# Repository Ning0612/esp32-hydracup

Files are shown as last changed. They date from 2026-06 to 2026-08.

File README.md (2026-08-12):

# HydraCup








ESP32-based smart water cup tracker. Measures cup weight via HX711, detects drink events, provides a local Device Console, and can sync with a separate LINE/LIFF service.

The firmware runs on native ESP-IDF/FreeRTOS through PlatformIO. Hardware access uses
ESP-IDF drivers; the web server, MQTT, Discord HTTPS client, NVS, and LittleFS are
all initialized from `app_main()` without the Arduino framework.

## Project Status

Personal side project for daily hydration tracking. It may continue to receive maintenance when new feature ideas or practical usage needs come up.

Real hardware:

<div align="center">
  <table align="center">
    <tr>
      <td align="center" valign="top">
        <strong>HydraCup real setup</strong><br>
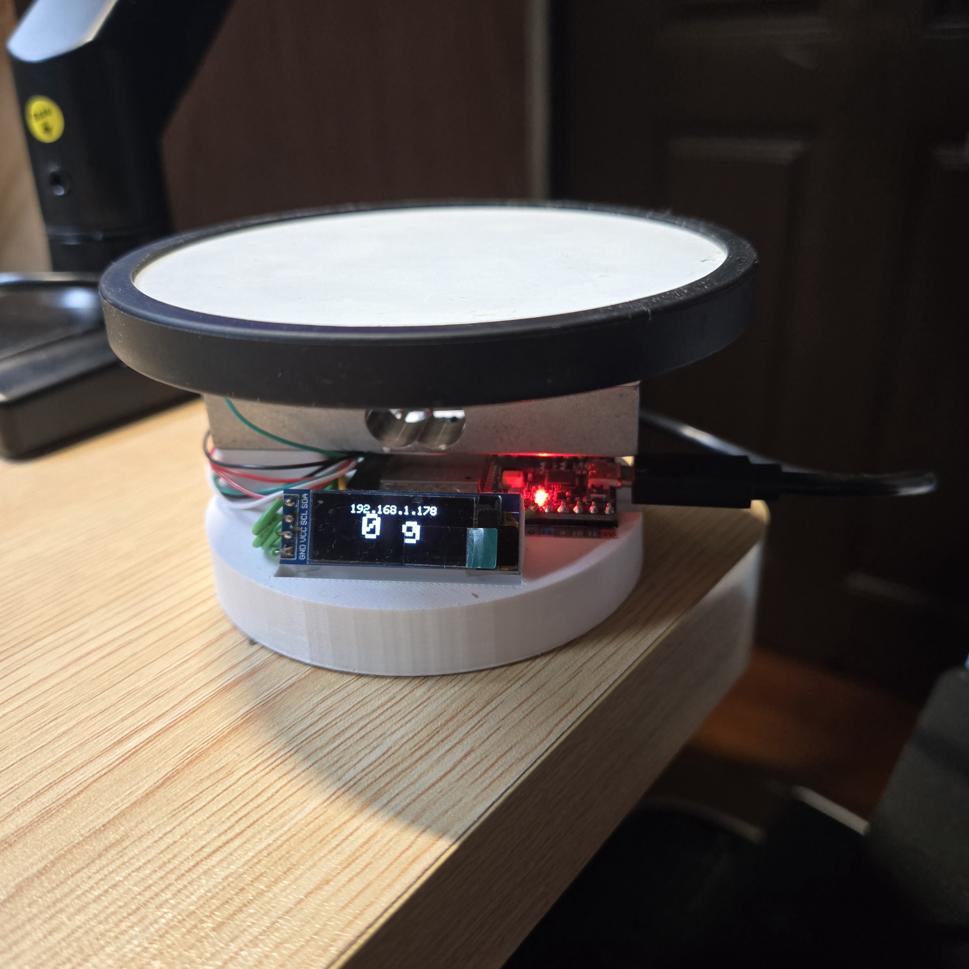
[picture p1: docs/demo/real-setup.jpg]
HydraCup real hardware setup
        
      </td>
      <td align="center" valign="top">
        <strong>OLED status</strong><br>
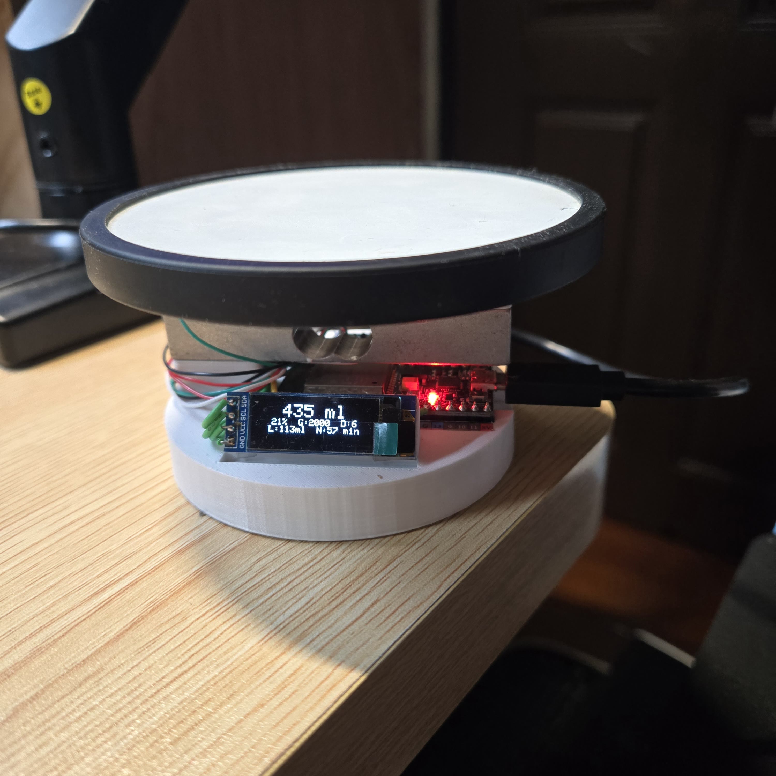
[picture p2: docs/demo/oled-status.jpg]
HydraCup OLED status on real hardware
        
      </td>
    </tr>
  </table>
</div>

## Demo

<p align="center">
  HydraCup drink detection preview
</p>

The GIF above is a compressed full-length preview; use the MP4 link below for the full-quality demo.

Full demo video:

- [Drink detection demo (MP4)](docs/demo/drink-detection-demo.mp4)

WebUI screenshots:

The local dashboard is served by the ESP32 at `http://<device-ip>`. The current Console uses the same cup-and-ripple visual language as the hosted LIFF UI, supports light and dark themes, and changes to a fixed three-item dock on small screens. It keeps live hardware diagnostics dense while the hosted UI remains focused on daily hydration. The screenshots below cover the dashboard, history analytics, and device configuration workflows; minor styling may evolve between releases.

<div align="center">
  <table align="center">
    <tr>
      <td colspan="2" align="center" valign="top">
        <strong>Dashboard overview</strong><br>
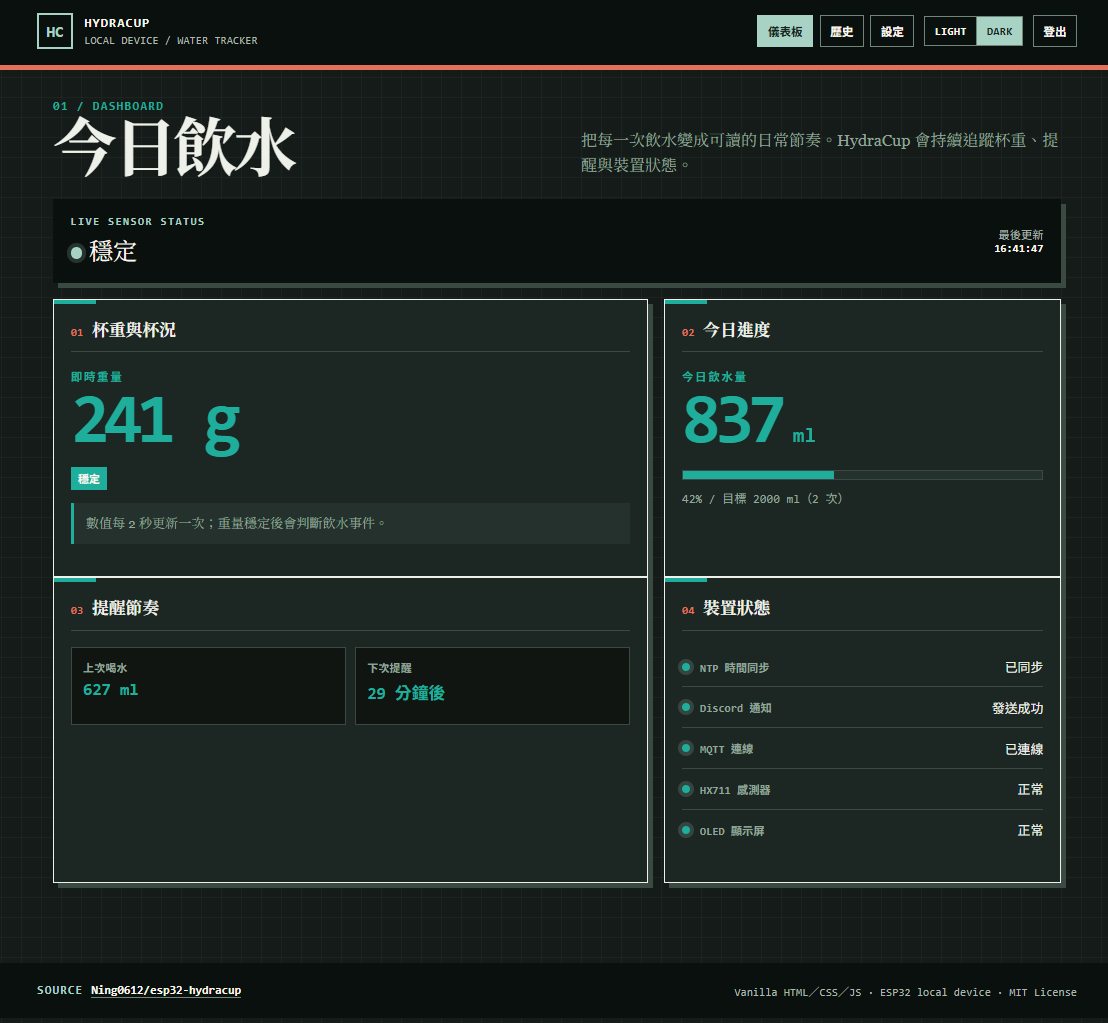
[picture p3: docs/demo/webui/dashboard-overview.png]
HydraCup WebUI dashboard overview
        
      </td>
    </tr>
    <tr>
      <td align="center" valign="top">
        <strong>History overview</strong><br>
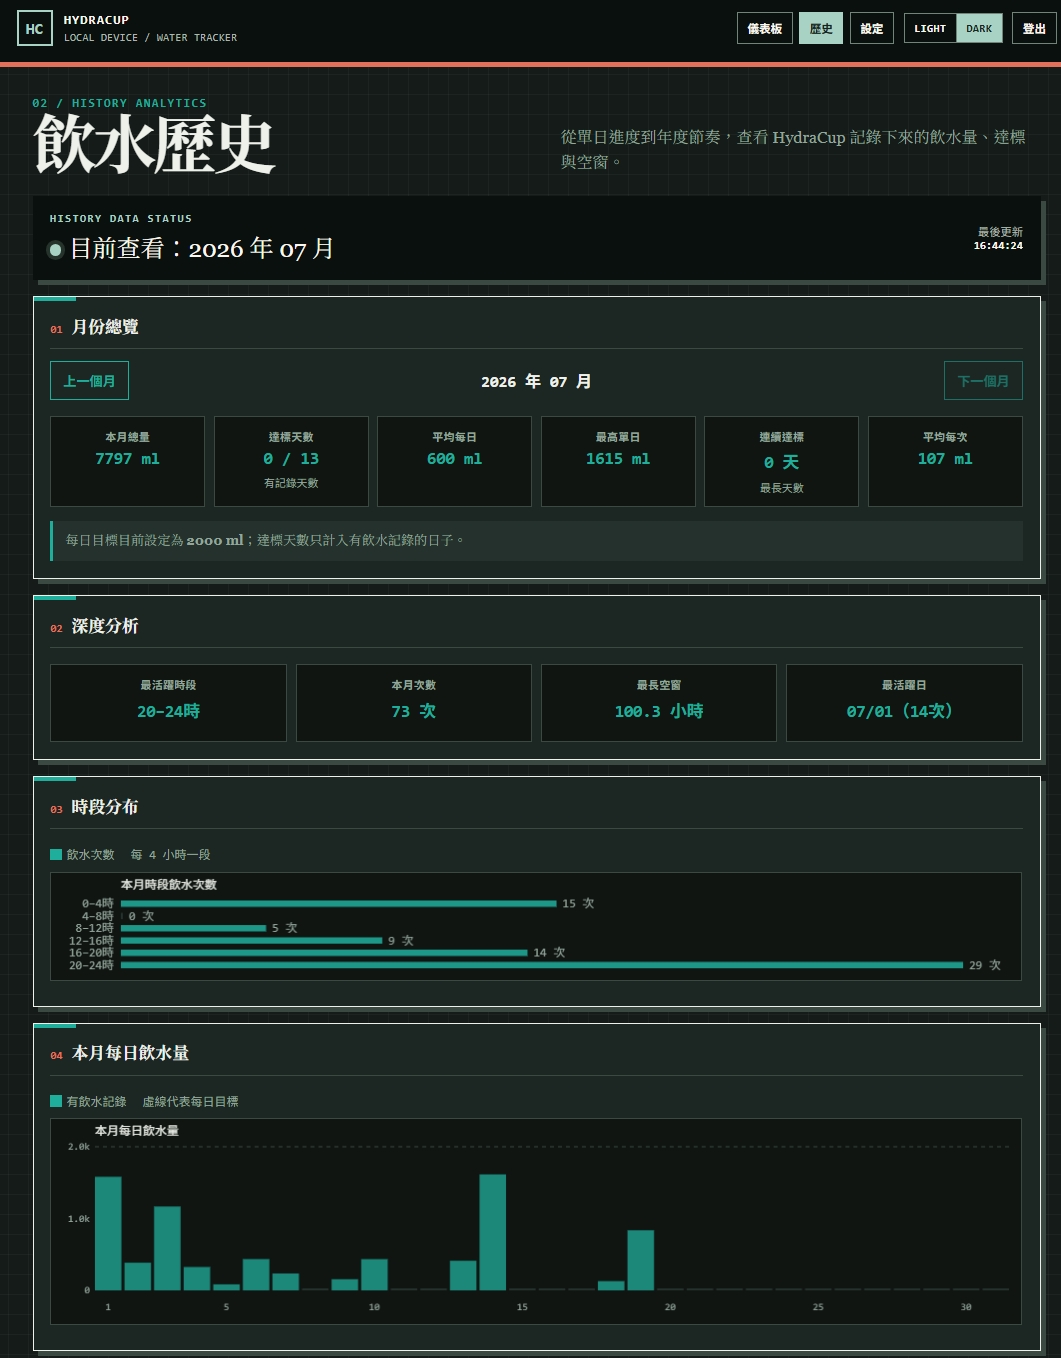
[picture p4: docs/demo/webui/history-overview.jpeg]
HydraCup WebUI history overview
        
      </td>
      <td align="center" valign="top">
        <strong>History statistics</strong><br>
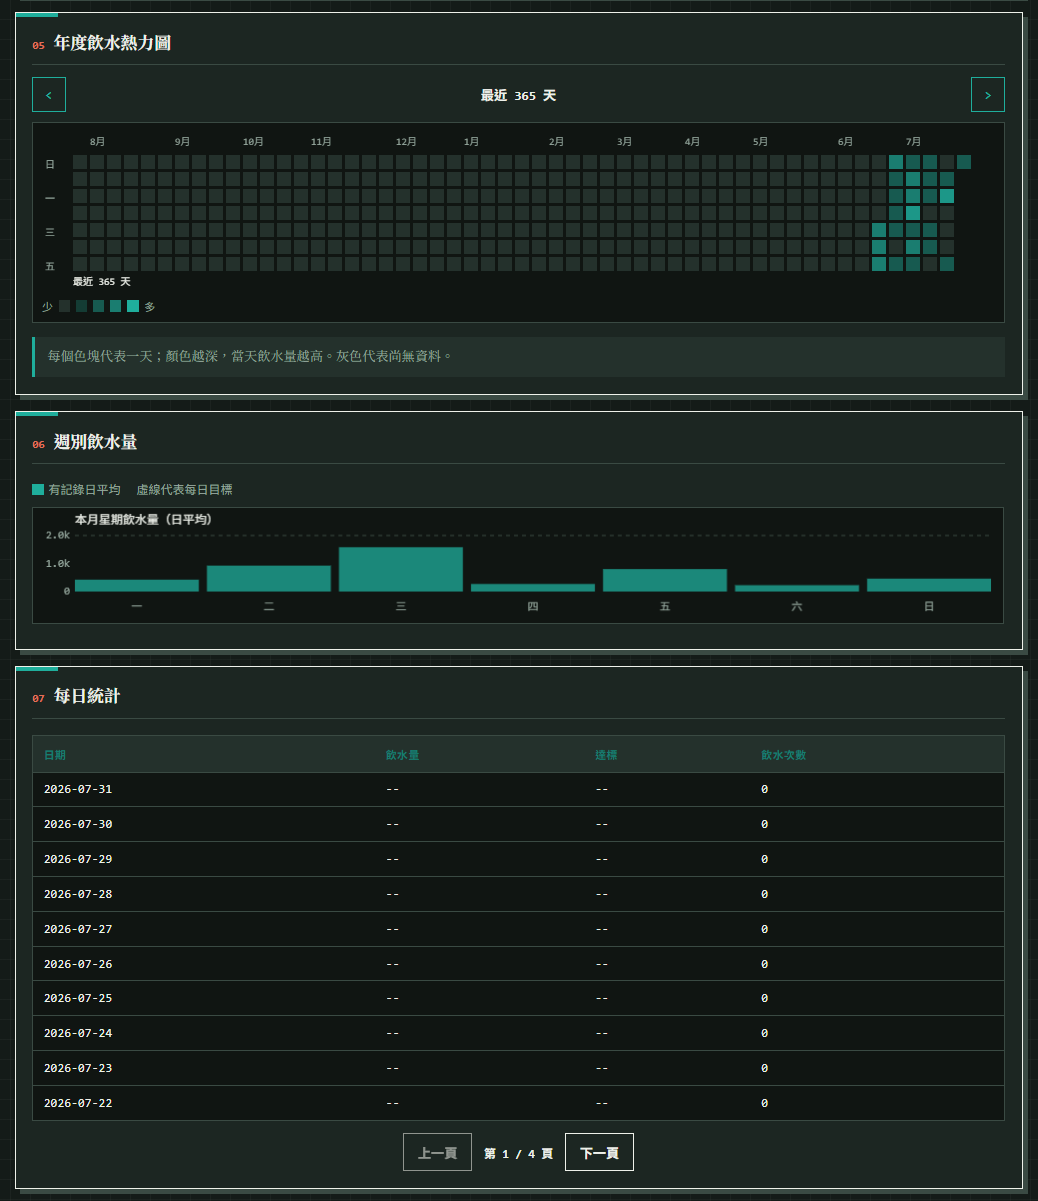
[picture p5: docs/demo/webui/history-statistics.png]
HydraCup WebUI history statistics
        
      </td>
    </tr>
    <tr>
      <td align="center" valign="top">
        <strong>Device settings</strong><br>
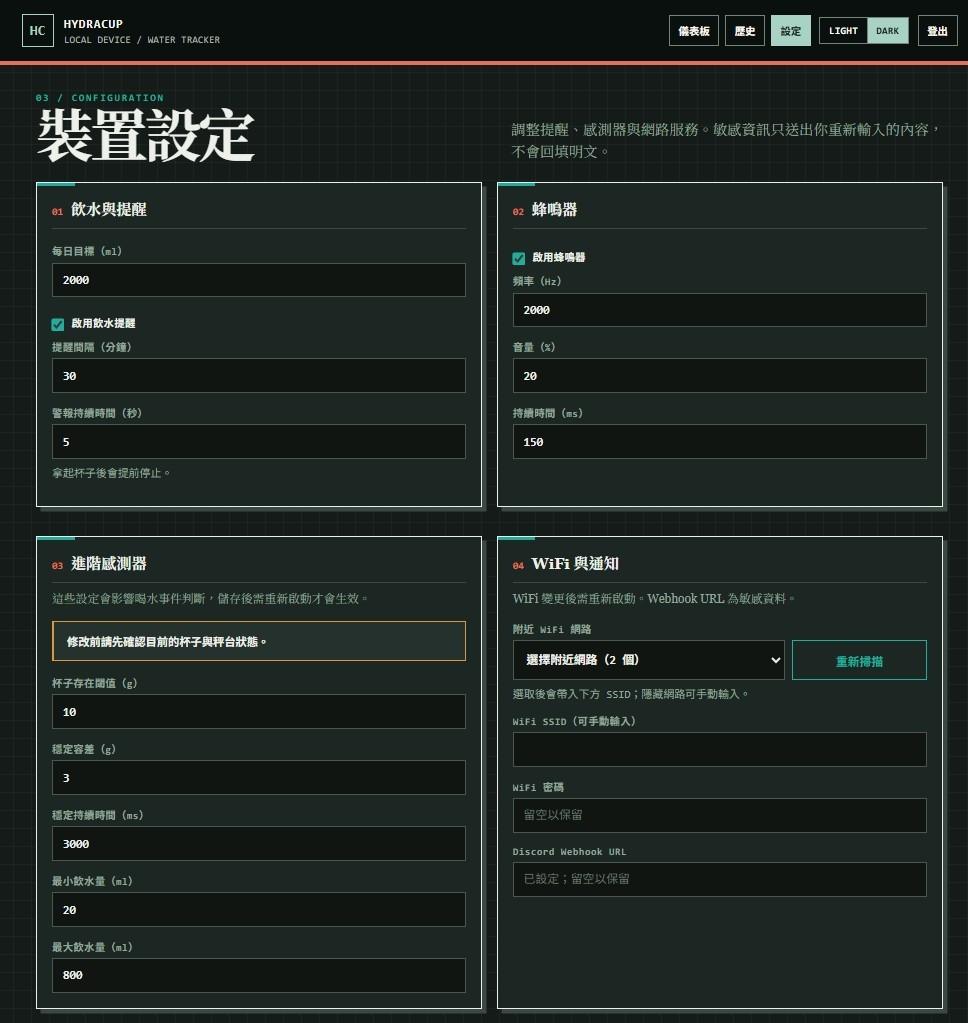
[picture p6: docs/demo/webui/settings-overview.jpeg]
HydraCup WebUI device settings
        
      </td>
      <td align="center" valign="top">
        <strong>Scale calibration</strong><br>
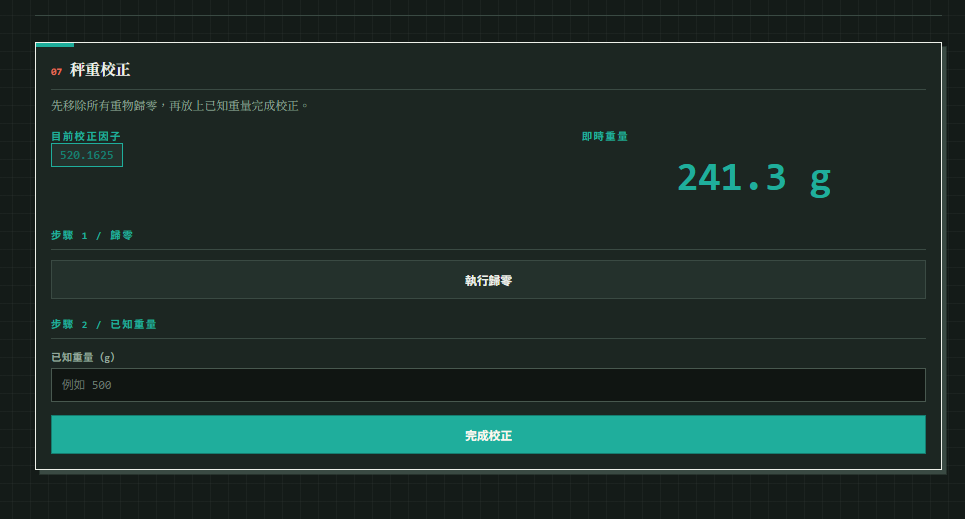
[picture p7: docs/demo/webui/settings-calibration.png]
HydraCup WebUI scale calibration
        
      </td>
    </tr>
  </table>
</div>

---

## Features

- **Automatic drink detection** — 6-state machine triggered only via cup-lift path, avoids false positives
- **Responsive Device Console** — cup/reminder state, real-time weight, progress, history, diagnostics, and progressively disclosed device settings at `http://<device-ip>`
- **Discord Webhook** — online notification, per-drink notification, daily summary at midnight
- **JSONL event log** — monthly log files stored on a dedicated LittleFS partition (`/logs/`)
- **OLED display** — 2-page rotating status display with auto-sleep
- **Cup-aware reminders** — counts only while a stable cup is present; a confirmed drink restarts the interval
- **Durable cloud sync** — LittleFS outbox with ACK-based replay plus resumable daily-history backfill for the separate LINE/LIFF WebUI service
- **OTA firmware updates** — check and install from GitHub Releases in the Device Console, with bootloader rollback if the new image fails to come up
- **Captive config portal** — WiFi setup at `192.168.4.1` on first boot (no app needed)
- **FreeRTOS control isolation** — scale/detection/reminder/display run in one high-priority control task; network operations stay in background workers
- **Non-blocking tare and workers** — tare is sample-driven; Discord, MQTT and drink logging use persistent/background workers

Cloud events are durably committed before the confirmed drink/refill callback returns. A transient LittleFS append failure falls back to an 8-record NVS emergency overflow. This adds bounded flash latency after a confirmed event; if both the 512 KiB outbox and emergency overflow are unavailable, Device Console reports a hard-drop counter. Measure worst-case LittleFS/NVS latency on the target board before production use.

---

## Hardware Requirements

| Component | Spec | GPIO |
|---|---|---|
| ESP32 dev board | 30-pin or 38-pin | — |
| HX711 load cell amplifier | 10 Hz or 80 Hz | DOUT→4, SCK→5 |
| Load cell / strain gauge | 1–5 kg range | via HX711 |
| SSD1306 OLED | 128×32, I2C | SDA→21, SCL→22 |
| Passive buzzer | 3.3 V compatible | PWM→18 |

See [docs/hardware.md](docs/hardware.md) for wiring details and BOM.

---

## Quick Start

**Prerequisites**: [PlatformIO](https://platformio.org/install/cli), Python 3.x, CP210x / CH340 USB driver

```bash
# 1. Clone
git clone https://github.com/<your-user>/esp32-hydracup.git
cd esp32-hydracup

# 2. Build firmware (ESP-IDF environment)
pio run -e esp32dev

# 3. Flash firmware + web assets (first time)
pio run -e esp32dev --target upload
pio run -e esp32dev --target uploadfs

# 4. If WiFi is not configured or the STA connection times out, the device
#    broadcasts "WaterCupTracker-Setup" AP. Connect and open http://192.168.4.1
#    The default AP password is 12345678. Enter your WiFi credentials and save.
#    This is not the admin password; no admin password has a default value.

# 5. After reboot, find the device IP and open http://<ip>/login
#    Set an admin password (at least 8 characters) on first use, then sign in.
```

See [docs/guides/getting-started.md](docs/guides/getting-started.md) for the complete first-time setup walkthrough.

---

## Architecture Overview

```
┌─────────────────── Normal Mode ───────────────────────┐
│  hydracup_control (Core 1, 10 ms)                     │
│  ├─ ScaleManager → DrinkDetector                      │
│  ├─ Reminder / Buzzer / Display / Time                │
│  └─ RuntimeSnapshot + ControlCommand Queue             │
│                                                       │
│  hydracup_service (50 ms) → WiFi / MQTT / health      │
│  esp_http_server task → Dashboard / REST API           │
│  workers → Cloud sync / Discord / MQTT / Log / NVS    │
└───────────────────────────────────────────────────────┘

┌────── AP Mode (no WiFi configured) ──────────────────┐
│  ConfigPortal  (HTTP at 192.168.4.1)                 │
└──────────────────────────────────────────────────────┘
```

---

## API Quick Reference

| Method | Path | Description |
|---|---|---|
| GET | `/api/status` | Full system state snapshot |
| GET | `/api/weight` | Current weight + cup state |
| GET | `/api/config` | All settings |
| POST | `/api/config` | Update settings |
| POST | `/api/tare` | Tare scale |
| POST | `/api/calibrate` | Calibrate with known weight |
| GET | `/api/logs?month=YYYY-MM` | Drink history |
| POST | `/api/cloud/history-backfill` | Start resumable Local-history backfill |
| GET | `/api/ota/status` | Firmware update state, progress and version |
| POST | `/api/ota/check` | Check GitHub Releases for a newer firmware |
| POST | `/api/ota/update` | Download and install the newer firmware |
| GET | `/api/wifi/scan` | Scan nearby networks |
| POST | `/api/reboot` | Reboot device |

All responses: `{"ok": true, ...}` or `{"ok": false, "error": "..."}`.  
Full API reference: [docs/api.md](docs/api.md)

---

## Documentation

| Document | Description |
|---|---|
| [docs/hardware.md](docs/hardware.md) | GPIO wiring and bill of materials |
| [docs/architecture.md](docs/architecture.md) | System architecture, boot flow, drink detection state machine |
| [docs/api.md](docs/api.md) | Complete REST API reference |
| [docs/modules.md](docs/modules.md) | Firmware module descriptions and public APIs |
| [docs/data-formats.md](docs/data-formats.md) | JSONL log format and NVS storage schema |
| [docs/guides/getting-started.md](docs/guides/getting-started.md) | First-time setup |
| [docs/guides/build-flash.md](docs/guides/build-flash.md) | Build and flash commands |
| [docs/guides/calibration.md](docs/guides/calibration.md) | Scale calibration |
| [docs/guides/configuration.md](docs/guides/configuration.md) | All settings explained |
| [docs/guides/discord-setup.md](docs/guides/discord-setup.md) | Discord Webhook setup |
| [docs/releases/v0.5.0.md](docs/releases/v0.5.0.md) | Cup-aware reminders, unified WebUI, LINE/LIFF sync, and history backfill |

The companion Cloudflare/LINE service is maintained in the private
[`hydracup-service`](https://github.com/Ning0612/hydracup-service) repository. Firmware `v0.5.0`
and service protocol v1 form the current tested pair; see the service user guide for pairing and
hosted LIFF operation.

## License

This public version is released under the MIT License. See [LICENSE](LICENSE).

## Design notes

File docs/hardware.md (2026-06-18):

# Hardware

## GPIO 腳位

所有腳位定義在 `include/pins.h`，原始碼中不得使用裸數字。

| 腳位名稱 | GPIO | 方向 | 說明 |
|---|---|---|---|
| `PIN_HX711_DOUT` | 4 | 輸入 | HX711 資料輸出（Data Out） |
| `PIN_HX711_SCK` | 5 | 輸出 | HX711 時脈（Serial Clock） |
| `PIN_OLED_SDA` | 21 | 雙向 | I2C 資料線（SSD1306 OLED） |
| `PIN_OLED_SCL` | 22 | 輸出 | I2C 時脈線（SSD1306 OLED） |
| `PIN_BUZZER` | 18 | 輸出 | LEDC PWM 蜂鳴器輸出 |

## 接線說明

### HX711 ↔ ESP32

```
HX711       ESP32
------      ------
VCC    →    3V3
GND    →    GND
DOUT   →    GPIO 4
SCK    →    GPIO 5
```

HX711 的 E+ / E- / A+ / A- 接稱重感測器（4線橋式）。  
使用 80 Hz 輸出速率時，將 RATE 腳位接高電位（3.3V）；使用 10 Hz 則接低或懸空。

### SSD1306 OLED ↔ ESP32

```
OLED        ESP32
------      ------
VCC    →    3V3
GND    →    GND
SDA    →    GPIO 21
SCL    →    GPIO 22
```

I2C 位址：`0x3C`，解析度：128×32。

### 蜂鳴器 ↔ ESP32

```
Buzzer      ESP32
------      ------
+      →    GPIO 18  (via 100Ω resistor recommended)
-      →    GND
```

使用無源蜂鳴器（Passive Buzzer）；有源蜂鳴器無法由 LEDC PWM 控制音調。

## 電源需求

| 供電 | 說明 |
|---|---|
| 5V USB | ESP32 板子 micro-USB 供電 |
| 3.3V | HX711、OLED、蜂鳴器（由 ESP32 板子 3V3 引腳供電） |

若使用超過 5 kg 的感測器或 HX711 增益 128 以外的設定，請確認感測器 E+ 供電穩定。

---

## 元件清單（BOM）

| 元件 | 規格 | 備注 |
|---|---|---|
| ESP32 Dev Board | 38-pin，帶 USB-UART（CP2102 或 CH340） | 任何標準 esp32dev 相容板皆可 |
| HX711 模組 | 10/80 Hz，24-bit ADC | 搭配 4線橋式稱重感測器 |
| 稱重感測器 | 1–5 kg，橋式應變計 | 建議搭配杯架固定 |
| SSD1306 OLED | 128×32，I2C，0.91 吋 | 0x3C 位址 |
| 無源蜂鳴器 | 3.3V，2 kHz | 不可用有源蜂鳴器 |
| 杯托 / 底座 | 平面壓力均勻分布 | 可 3D 列印 |
| 跳線 | 公對公 / 公對母 | 接麵包板或焊接 |
| 麵包板 / PCB | 830孔麵包板 或 洞洞板 | 原型用途 |

### 台灣採購建議

- ESP32 / HX711 / SSD1306：台灣各大網路電子材料商（露天、蝦皮、飆機器人）
- 稱重感測器：「應變計稱重」or「load cell 台灣」搜尋

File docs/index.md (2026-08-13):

# HydraCup Documentation

ESP32 智慧水杯追蹤器完整文件索引。

---

## 硬體與設定

- [hardware.md](hardware.md) — GPIO 接線圖、元件清單（BOM）

## 系統架構

- [architecture.md](architecture.md) — 模組架構、資料流、開機流程、飲水偵測狀態機

## API 參考

- [api.md](api.md) — 完整 REST API 端點（DashboardServer + ConfigPortal）

## 模組文件

- [modules.md](modules.md) — 18 個模組的責任、依賴與公開方法

## 資料格式

- [data-formats.md](data-formats.md) — JSONL 日誌格式、NVS 儲存 Schema

## 操作指南

- [guides/getting-started.md](guides/getting-started.md) — 首次使用設定流程
- [guides/build-flash.md](guides/build-flash.md) — 建置與燒錄指令
- [guides/calibration.md](guides/calibration.md) — 秤重校正步驟
- [guides/configuration.md](guides/configuration.md) — 所有設定說明
- [guides/discord-setup.md](guides/discord-setup.md) — Discord Webhook 設定

## LINE／LIFF 雲端服務

- [HydraCup Service 使用指南](https://github.com/Ning0612/hydracup-service/blob/main/docs/user-guide.md)（`hydracup-service` 為私有 repo，需有存取權限） — Cloud sync、配對、歷史補傳與 LIFF 操作
- [HydraCup Service v1 協定](https://github.com/Ning0612/hydracup-service/blob/main/docs/protocol.md)（`hydracup-service` 為私有 repo，需有存取權限） — 裝置同步、command／ACK 與歷史查詢合約

韌體 `v0.5.0` 與 service protocol v1 是目前驗證組合。ESP32 保留 Local 月檔並作為飲水事件與
提醒狀態的唯一真實來源；LIFF 顯示已同步事件及使用者主動執行的歷史補傳資料。

## 版本紀錄

- [releases/v0.5.0.md](releases/v0.5.0.md) — 杯況感知提醒、統一 WebUI、LINE／LIFF 同步與歷史補傳
- [releases/v0.4.0.md](releases/v0.4.0.md) — 原生 FreeRTOS/ESP-IDF 遷移與首次使用流程更新
- [releases/v0.3.0.md](releases/v0.3.0.md) — WebUI 風格重設計與展示素材更新
- [releases/v0.2.0.md](releases/v0.2.0.md) — FreeRTOS runtime 與背景 worker 更新

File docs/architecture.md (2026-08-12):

# Architecture

## 系統架構

HydraCup 以 PlatformIO + ESP-IDF 5.x 的 native FreeRTOS runtime 運行，分為兩個互斥模式。
`app_main()` 負責初始化硬體、NVS、LittleFS、網路與服務；固定在 Core 1 的高優先
`hydracup_control` task 負責感測與即時控制：

```
┌────────────────────────────────────────────────────────┐
│                    BOOT                                │
│  app_main → NVS → webfs/logfs → Config → OLED/HX711   │
│  → Buzzer → WiFi configured?                          │
│        No  → AP_MODE (ConfigPortal)                   │
│        Yes → STA connect → OK? → NORMAL : AP_MODE     │
└────────────────────────────────────────────────────────┘

┌────────── AP Mode ─────────────────────────────────────┐
│  ConfigPortal  HTTP server @ 192.168.4.1               │
│  → WiFi config saved → reboot → NORMAL                │
└────────────────────────────────────────────────────────┘

┌────────── Normal Mode ─────────────────────────────────┐
│  hydracup_control (10 ms, Core 1)                     │
│  ScaleManager → DrinkDetector                          │
│                     ├─→ EventLogger                    │
│                     ├─→ DiscordNotifier                │
│                     ├─→ ReminderManager                │
│                     ├─→ BuzzerController               │
│                     └─→ AppState                       │
│                                                        │
│  ├─ ReminderManager / BuzzerController                 │
│  ├─ DisplayManager / TimeManager                       │
│  └─ DailySummaryManager                                │
│                                                        │
│  hydracup_service (50 ms): WiFi / MQTT / health        │
│  esp_http_server task: DashboardServer                 │
│  workers: MQTT / Discord / EventLogger / CloudSync / NVS│
└────────────────────────────────────────────────────────┘
```

### 設計約束

- `hydracup_control` 是 Scale、Detector、Reminder、Buzzer、Display、Time 的單一 owner
- HTTP handler 不直接驅動控制模組；Dashboard 透過 snapshot / command 溝通
- 不使用 Arduino `setup()` / `loop()`；控制與服務 task 都必須保持非阻塞
- 所有時間取值使用 `hal_millis()` / `hal_micros()`（底層為 `esp_timer`），等待使用 `vTaskDelay`
- Discord 與 MQTT 各使用持久 FreeRTOS worker；兩者不共用阻塞 task
- tare 是 10 筆、每 100 ms 一筆的非阻塞狀態機；期間暫停飲水偵測
- NVS 操作透過共用 mutex 序列化；LogFS 讀寫也有獨立 mutex
- counter restore worker 只載入 POD，由 `hydracup_control` 套用；跨日資料即使非午夜開機也會立即結算
- Daily settlement 等待 counter save ack，再由 storage worker 寫 settled marker，控制 task 不等待 flash

---

## 模組職責表

| 模組 | 職責 |
|---|---|
| `AppState` | 共用執行時狀態結構（模式、杯子狀態、今日飲水量等） |
| `ConfigManager` | NVS 讀寫 `AppConfig`；命名空間 `water_config` |
| `WiFiManager` | STA 連線、AP 啟動、連線狀態管理 |
| `ConfigPortal` | AP Mode HTTP 伺服器（192.168.4.1），WiFi 設定 |
| `DashboardServer` | Normal Mode HTTP 伺服器，儀表板 + REST API |
| `ScaleManager` | HX711 取樣、移動平均濾波、秤台校正 |
| `DrinkDetectorCore` | framework-independent 的 6 態飲水偵測核心，輸出飲水/補水事件 |
| `DrinkDetector` | ESP32 adapter：對接 ScaleManager、AppState、每日計數器與通知管道 |
| `ReminderCore` | framework-independent 主動時間狀態機；穩定放杯才計時，杯子離開即暫停 |
| `ReminderManager` | 驅動 ReminderCore 與蜂鳴器；只有確認喝水才重新計時 |
| `CloudSyncClient` | LittleFS durable outbox、HTTPS 批次同步、command ACK、配對碼與可續傳歷史補傳 |
| `BuzzerController` | LEDC PWM 非阻塞蜂鳴佇列（7 種模式） |
| `DisplayManager` | SSD1306 OLED 輪播（2 頁，各 4 秒），自動睡眠 |
| `DiscordNotifier` | 非同步 HTTPS POST 至 Discord Webhook |
| `EventLogger` | LittleFS JSONL 飲水事件日誌（依月份分檔） |
| `OtaUpdater` | GitHub Releases 版本檢查與 `esp_https_ota` 韌體寫入；含開機確認與 rollback |
| `HistoryMaintenance` | 飲水紀錄清除：WebUI 只記錄要求，實際清除在下次開機、掛載前執行 |
| `TimeManager` | NTP 時間同步；提供 ISO-8601 時戳 |
| `DailySummaryManager` | 每日午夜聚合統計並送出 Discord 摘要 |
| `RuntimeCoordinator` | 一致 runtime snapshot、control command/result Queue |
| `StorageLock` | 跨 task 序列化 NVS 操作 |
| `Hal` | `esp_timer` 時間、FreeRTOS delay 與 ESP-IDF logging wrapper |
| `HttpAuth` | session token、CSRF、PBKDF2 密碼雜湊與 constant-time 比對 |
| `HttpServerSupport` | `esp_http_server` request、header、檔案與 response 共用工具 |

---

## 開機流程

```
1. `app_main()` 開始，ESP-IDF logging 以 115200 baud 輸出
2. `nvs_flash_init()`             → NVS 設定與計數器
2b. `ota_boot_check()`            → 記錄本次映像是否待確認（兩種模式都執行）
2c. `history_apply_pending_clear()` → 有待處理的清除要求時，在掛載前格式化 logfs 並清空計數
3. `esp_vfs_littlefs_register()`  → `/webfs` 與 `/logfs`
4. `ConfigManager.load(cfg)`      → 從 NVS 讀取設定
5. `DisplayManager.init()`        → 失敗則記錄並繼續
6. `ScaleManager.init()`          → 失敗則記錄並繼續
7. `BuzzerController.init()`      → 準備開機提示音
8. `WiFiManager.connectSTA()`
   ├─ WiFi SSID 空白 → AP_MODE
   ├─ 連線失敗       → AP_MODE
   └─ 連線成功       → NORMAL
9. NORMAL：初始化 NTP、Discord、MQTT、EventLogger、DailySummary、DashboardServer 與 OtaUpdater
10. AP_MODE：初始化 ConfigPortal（HTTP server @ `192.168.4.1`）
11. 建立 `hydracup_control`（Core 1）與 `hydracup_service` task
12. `esp_http_server` 自己處理 Dashboard／ConfigPortal request callback
```

外設（OLED、HX711）初始化失敗時**不中斷開機**，僅記錄錯誤並設
`AppState.oledOk = false` / `hx711Ok = false`。LittleFS mount 使用
`format_if_mount_failed = false`，因此 mount 失敗時不會自動格式化或清除資料。

---

## OTA 期間的併發降載

`esp_ota_write()` 內部呼叫 `spi_flash_disable_interrupts_caches_and_other_cpu()`，寫入
1 MB 級映像期間會分成約 300 次 4 KB 寫入，每次停用兩顆 core 的 flash cache 數百 µs 至數 ms。
`CONFIG_ESP_TASK_WDT_TIMEOUT_S=5`，單次停用遠低於此，不會誤觸發 watchdog。

`OtaUpdater` 只設定 `AppState::otaInProgress`（atomic），各模組在自己的迴圈頂端輪詢降載，
沒有任何模組被 OTA 直接呼叫：

| 子系統 | 處置 | 理由 |
|---|---|---|
| `drinkDetector.update()` 事件判定 | 跳過 | HX711 是時序敏感的 bit-bang，cache 停用造成的抖動會讓 24-bit 讀值失真，記入假事件會汙染 logfs 與雲端資料 |
| `ScaleManager` 取樣 | **不停** | 停掉會讓 Web 的重量顯示卡在舊值，體驗更差；資料只是暫時不可信 |
| `cloud_sync` / `discord_worker` | 暫停 | 各自的 mbedtls session 約 40 KB heap 與 1 個 socket，與韌體寫入直接競爭 |
| MQTT 心跳 | 暫停 | 省下 socket 預算 |
| `esp_http_server` | **不停** | 必須持續回報進度 |

`EventLogger` 不特別暫停：事件判定已停止，本來就不會有新的日誌寫入，且 ESP-IDF 的
spi_flash 層本身有互斥，競爭只會變慢不會損毀。

`otaInProgress` 是降載訊號，不是同步屏障——各模組只在自己的迴圈頂端觀察它，已經進入 HTTPS
請求的 worker 會持有 TLS heap 直到請求結束（其 HTTP timeout 為 10 秒）。因此下載開始前會
**輪詢等待可用 heap 回升**（每 250 ms，最多 12 秒，超過其 HTTP timeout），而不是固定延遲：
等待的對象直接就是真正稀缺的資源，worker 仍握著 session 正是 heap 偏低的原因。

`requestUpdate()` 另有一道事前檢查，可用 heap 低於 `OTA_MIN_FREE_HEAP_BYTES`（60 KB）直接回
`503`。寫入途中 OOM 會留下半寫入的 slot，事前拒絕遠優於此。

### 憑證信任

OTA 是唯一一條「壞掉之後無法用自己修好自己」的路徑，所以**不釘選根憑證**：GitHub 會把
release 資產 302 轉址到 `objects.githubusercontent.com`，兩個網域的憑證鏈由 GitHub 自行輪換，
釘選失效等於同時失去發佈修正的能力。改用 ESP-IDF 內建 CA bundle 的 CMN 子集（41 張、約
18 KB，涵蓋 DigiCert、Sectigo、ISRG、Amazon、GTS）。

`CloudSyncClient` 與 `DiscordNotifier` 維持既有的釘選 PEM——對端是自己可控的服務或固定的
第三方 API，釘選在那裡是更強的保證。

---

## 飲水偵測狀態機

### 狀態定義

| 狀態 | 值 | 說明 |
|---|----|---|
| `NO_CUP` | 0 | 無杯子（重量低於閾值） |
| `CUP_UNSTABLE` | 1 | 杯子已放上但重量未穩定 |
| `CUP_STABLE` | 2 | 杯子穩定放置 |
| `POSSIBLE_DRINK` | 3 | 重量下降中（可能正在喝） |
| `DRINK_CONFIRMED` | 4 | 飲水確認（瞬間狀態） |
| `REFILL_DETECTED` | 5 | 補水確認（瞬間狀態） |

### 狀態轉換圖

```
                    ┌─────────────────────────────┐
                    │                             │
                    ▼                             │ weight < threshold
              [NO_CUP]                            │ (_cupLifted = true)
                    │                             │
   weight >= threshold                            │
                    │                             │
                    ▼                             │
          [CUP_UNSTABLE] ◄────────────────────────┘
           (_cupLifted?)
                    │
    isStable() && !_cupLifted
                    │
                    ▼
           [CUP_STABLE] ◄──────────────────────────────────────────┐
                    │                                               │
    weight drops    │  weight < threshold          isStable()      │
    (not stable)    │  (_cupLifted = true)             │           │
                    │                                  │           │
                    ▼                                  │           │
        [POSSIBLE_DRINK]                               │           │
                    │                                  │           │
    weight < threshold     isStable()                  │           │
    (_cupLifted = true)        │                       │           │
                    │          └───────────────────────┘           │
                    │                                               │
                    └───────────────────────────────────────────────┘
                              (→ CUP_STABLE after update)

    isStable() && _cupLifted:
      delta in [minDrink, maxDrink]             → [DRINK_CONFIRMED]  → CUP_STABLE
      (newStable - prevRef) >= minDrink         → [REFILL_DETECTED]  → CUP_STABLE
      else                                      → CUP_STABLE
```

### 關鍵機制

**`_cupLifted` 旗標**：只有當狀態為 `CUP_STABLE`（或 `POSSIBLE_DRINK`）且重量低於 `cupPresentThresholdGram` 時才設置。確保**飲水與補水事件只能透過「拿起再放下」路徑觸發**，防止秤台上的重量微變造成誤判。

**`DRINK_LIFT_TIMEOUT_MS = 120,000 ms`**：若杯子被拿起超過 120 秒後放回，重置 `_cupLifted` 為 false，不觸發飲水事件（視為與飲水無關的操作）。

**杯子放置但重量變化（無拿起）**：只更新 `_prevStableWeight`，不觸發任何飲水或補水事件。

### 觸發條件參數

| 參數 | 預設值 | 說明 |
|---|---|---|
| `cupPresentThresholdGram` | 80.0 g | 低於此值視為無杯子 |
| `stableToleranceGram` | 3.0 g | 穩定判斷允許誤差 |
| `stableDurationMs` | 3000 ms | 必須在誤差內持續此時間才算穩定 |
| `minDrinkDeltaMl` | 20.0 ml | 最小有效飲水量 |
| `maxDrinkDeltaMl` | 500.0 ml | 最大有效飲水量 |

`1 g ≈ 1 ml` 在整個系統中成立。

### 濾波與穩定判定依據

`ScaleManager` 以 10 筆 moving average 平滑 HX711 讀值；取樣間隔為 100 ms，
因此約涵蓋 1 秒的短期輸入。這個窗口用來壓低單次 ADC 抖動，同時保留拿起杯子
與放回杯子的重量變化反應速度。

穩定判定預設允許重量在 ±3 g 內波動，並要求持續 3000 ms。3 g 是用來容許 load
cell 與平台的微幅噪聲；3 秒則避免短暫碰撞或放杯回彈直接進入 `CUP_STABLE`。
這兩個值是初始調校值，應依實際秤台、load cell 與環境振動調整：放寬誤差或縮短
時間會加快反應但提高誤判風險，收緊誤差或延長時間則相反。

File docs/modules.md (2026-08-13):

# Modules

HydraCup 共有 21 個模組，位於 `lib/` 目錄下。每個模組對應一個 `.h` 標頭與 `.cpp` 實作；
其中 `Hal`、`HttpAuth`、`HttpServerSupport` 是 ESP-IDF runtime 與 HTTP 安全邏輯的共用基礎模組。

---

## AppState

**職責**：保留控制 domain 內部狀態與少量 atomic worker 狀態。跨 task 的 Dashboard
讀取改由 `RuntimeCoordinator` 發布一致快照，不直接把 `AppState` 當同步機制。

**位置**：`lib/AppState/AppState.h`

| 欄位 | 型別 | 預設 | 說明 |
|---|---|---|---|
| `mode` | `AppMode` | `BOOT` | 運行模式（BOOT / AP_MODE / NORMAL） |
| `fsOk` | bool | false | `/webfs` LittleFS mount 可用 |
| `logFsOk` | bool | false | `/logfs` LittleFS mount 可用 |
| `oledOk` | bool | false | OLED 初始化成功 |
| `hx711Ok` | bool | false | HX711 初始化成功 |
| `buzzerOk` | bool | false | 蜂鳴器初始化成功 |
| `wifiConnected` | bool | false | WiFi 連線狀態 |
| `ntpSynced` | bool | false | NTP 同步狀態 |
| `weightGrams` | float | 0.0 | 目前秤重（g） |
| `cupState` | `CupState` | `NO_CUP` | 杯子狀態 |
| `todayTotalMl` | float | 0.0 | 今日累計飲水量（ml） |
| `lastDrinkMl` | float | 0.0 | 上次飲水量（ml） |
| `drinkCountToday` | uint32 | 0 | 今日飲水次數 |
| `nextReminderSec` | uint32 | 0 | 下次提醒倒數（秒） |
| `webhookConfigured` | bool | false | Discord Webhook URL 已設定 |
| `webhookLastOk` | atomic\<bool\> | false | 最後一次 Webhook 發送成功 |
| `ipAddress` | `std::string` | `""` | 目前 IP 位址 |

---

## ConfigManager

**職責**：以 ESP-IDF NVS API 持久化 `AppConfig` 的所有欄位。命名空間：`water_config`。

**位置**：`lib/ConfigManager/`

| 方法 | 說明 |
|---|---|
| `load(AppConfig& cfg)` | 從 NVS 讀取設定，未設定欄位保持預設值 |
| `save(const AppConfig& cfg)` | 將所有欄位寫入 NVS |
| `saveCalibration(float factor, long offset)` | 僅更新校正係數與 tare 偏移 |
| `saveWifi(const std::string& ssid, const std::string& password)` | 僅更新 WiFi 憑證 |
| `clear()` | 清除整個命名空間 |

NVS key 對應見 [data-formats.md](data-formats.md#nvs-schema)。

所有 NVS 操作都使用 `StorageLock` 共用 mutex，避免多個 worker 同時進入 NVS。

---

## RuntimeCoordinator

**職責**：發布帶 sequence 的一致 `RuntimeSnapshot`，並以固定大小 Queue 傳遞
`ControlCommand` / `ControlResult`。HTTP timeout 不會留下 caller-owned pointer。
同步 result Queue 明確由單一 `DashboardServer` requester 使用。

**位置**：`lib/RuntimeCoordinator/`

---

## StorageLock

**職責**：提供全專案共用的 NVS mutex；Config、飲水計數器與每日結算使用相同鎖。

**位置**：`lib/StorageLock/`

---

## Hal

**職責**：提供 ESP-IDF runtime 共用的時間與等待 wrapper，避免各模組重複處理底層 API。

**位置**：`lib/Hal/`、`include/hal_*.h`

| 函式 | 實作 |
|---|---|
| `hal_micros()` / `hal_millis()` | 由 ESP-IDF `esp_timer_get_time()` 取得單調時間 |
| `hal_delay_ms(uint32_t milliseconds)` | 以 FreeRTOS `vTaskDelay()` 非阻塞等待 |
| `LOG_INFO` / `LOG_WARN` / `LOG_ERROR` / `LOG_DEBUG` | 對應 ESP-IDF `ESP_LOG*` |

---

## HttpAuth

**職責**：提供登入 session 所需的隨機 token、Cookie 解析、constant-time 比對與
PBKDF2-HMAC-SHA256 密碼雜湊／驗證。

**位置**：`lib/HttpAuth/`、`include/hydracup_auth.h`

密碼只以雜湊寫入 NVS；session token 與 CSRF token 僅存在 runtime memory。

---

## HttpServerSupport

**職責**：封裝 ESP-IDF `esp_http_server` 共用的 request body/header/IP 讀取、JSON／檔案
回應與延遲重啟工具。

**位置**：`lib/HttpServerSupport/`、`include/http_server_support.h`

---

## WiFiManager

**職責**：管理 STA 連線與 AP 啟動，向 `AppState` 回報連線狀態與 IP。

**位置**：`lib/WiFiManager/`

| 方法 | 說明 |
|---|---|
| `begin()` | 初始化 ESP-IDF event loop、netif、WiFi driver 與事件 handler |
| `connectSTA(const std::string& ssid, const std::string& password, uint32_t timeoutMs = 10000)` | 嘗試 STA 連線，帶超時（ms）；回傳是否成功 |
| `startAP(const std::string& ssid, const std::string& password)` | 啟動 SoftAP；回傳是否成功 |
| `loop()` | 由 `hydracup_service` task 呼叫；STA 斷線時觸發重連 |
| `isConnected()` | 回傳 STA 是否已連線 |
| `getIP()` | 回傳 STA IP 字串 |
| `getAPIP()` | 回傳 AP IP 字串（AP Mode 下使用） |

---

## ConfigPortal

**職責**：AP Mode 下的 HTTP 設定伺服器，提供 WiFi 設定頁面，接收並儲存憑證後觸發重啟。

**位置**：`lib/ConfigPortal/`

**端點**：`/`、`/api/status`、`/api/config`（POST）、`/api/wifi/scan`、`/api/reboot`

---

## DashboardServer

**職責**：Normal Mode 下的 HTTP 伺服器，提供靜態 Web UI 並實作完整 REST API。

**位置**：`lib/DashboardServer/`

| 方法 | 說明 |
|---|---|
| `begin(ScaleManager&, ConfigManager&, AppState&, AppConfig&, ...)` | 啟動 ESP-IDF HTTP server 並掛載所有路由 |
| `loop()` | 保留的空實作；request 由 `esp_http_server` task callback 處理 |

Dashboard 讀取 `RuntimeSnapshot`；tare、calibrate 與立即生效的 reminder/buzzer 設定會送出
typed control command，等待固定大小的 `ControlResult`。

API 完整文件見 [api.md](api.md)。

---

## ScaleManager

**職責**：驅動 HX711，維護 10 樣本的移動平均緩衝區，並判斷重量是否穩定。

**位置**：`lib/ScaleManager/`

| 方法 | 說明 |
|---|---|
| `init(float calibFactor, long tareOffset, float stableToleranceG, uint32_t stableDurationMs)` | 初始化 HX711 與穩定偵測參數 |
| `update()` | 每 100 ms 取樣一次，更新移動平均 |
| `isReady()` | HX711 是否成功初始化 |
| `isSamplesReady()` | 移動平均緩衝區是否已填滿 10 個樣本 |
| `isStable()` | 若重量在 ±`stableToleranceG` 內持續 `stableDurationMs` 則回傳 true |
| `getWeightGrams()` | 取得目前移動平均重量（g） |
| `getStableWeightGrams()` | 取得最後穩定重量（g） |
| `getRawAverage()` | 取得原始 ADC 均值（除錯用） |
| `tare()` / `startTare()` | 啟動非阻塞歸零狀態機 |
| `isTareRunning()` | tare 是否仍在收集樣本 |
| `takeTareResult(long&)` | 取得完成的 tare offset |
| `setCalibrationFactor(float factor)` | 直接設定校正係數 |
| `calibrateWithKnownWeight(float knownGrams)` | 計算並回傳新的 calibrationFactor |
| `getTareOffset()` | 取得目前 tare 偏移 |
| `getCalibrationFactor()` | 取得目前校正係數 |

**常數**：`HX711_SAMPLE_COUNT = 10`，`HX711_READ_INTERVAL_MS = 100`

---

## DrinkDetectorCore

**職責**：framework-independent 的 6 態飲水偵測核心。輸入重量、穩定狀態與時間，
透過 `DrinkDetectorEventSink` 輸出飲水/補水事件；`DrinkDetectorEventHandler`
則隔離計數器、持久化與通知效果，供 native 測試使用 fake ports。

**位置**：`lib/DrinkDetectorCore/`

## DrinkDetector

**職責**：ESP32 adapter，將 `ScaleManager`、`AppState`、NVS、提醒、蜂鳴器與通知
管道接到 `DrinkDetectorCore`；核心仍僅透過「杯子拿起後放下」路徑觸發飲水或補水事件。

**位置**：`lib/DrinkDetector/`

| 方法 | 說明 |
|---|---|
| `init(ScaleManager& scale, AppState& state, const AppConfig& cfg, ReminderManager& reminder, BuzzerController& buzzer)` | 初始化，注入依賴並從 NVS 還原當日計數 |
| `update()` | 由 `hydracup_control` 呼叫，推進狀態機 |
| `resetScaleBaseline()` | tare 完成後清除舊杯重基準，避免誤判事件 |
| `setDiscordNotifier(DiscordNotifier* dn)` | 注入 DiscordNotifier 依賴 |
| `setEventLogger(EventLogger* el)` | 注入 EventLogger 依賴 |
| `setTimeManager(TimeManager* tm)` | 注入 TimeManager 依賴 |
| `setCounterPersistence(DrinkCounterPersistence* store)` | 替換每日計數器持久化 port；預設使用 ESP-IDF NVS counter store |
| `getCupState()` | 取得目前 `CupState` |
| `getTodayTotalMl()` | 取得今日累計飲水量（ml） |
| `getLastDrinkMl()` | 取得上次飲水量（ml） |
| `getDrinkCountToday()` | 取得今日飲水次數 |
| `resetDailyCounters()` | 重置計數器（DailySummaryManager 午夜呼叫） |

**持久化**：NVS 命名空間 `drink_ctr`；日期變更時自動重置並聚合統計。狀態機邏輯見 [architecture.md](architecture.md#飲水偵測狀態機)。
一般 counter snapshot 由單一 worker 合併儲存；pending/completed version 提供 DailySummary
使用的非阻塞 persistence barrier。Restore worker 只讀取 POD，最後由 `hydracup_control` 套用。

---

## ReminderManager

**職責**：只累積水杯穩定放置的主動時間；杯子拿走時暫停，放回後續算剩餘時間。到期後維持 alerted 狀態，只有有效喝水事件才重新計時；補水或無效重量變化不會重置。

**位置**：`lib/ReminderManager/`

| 方法 | 說明 |
|---|---|
| `init(uint32_t intervalMin, bool enabled)` | 設定提醒間隔（分鐘）與啟用狀態 |
| `update()` | 由 `hydracup_control` 呼叫，驅動提醒計時器 |
| `onDrinkConfirmed()` | 確認有效喝水後重新開始提醒週期 |
| `setBuzzer(BuzzerController* buz)` | 注入蜂鳴器依賴 |
| `setAppState(AppState* state)` | 注入 AppState 依賴 |
| `setEnabled(bool en)` | 啟用/停用提醒 |
| `setIntervalMin(uint32_t min)` | 動態更新提醒間隔 |
| `setAlertTimeoutSec(uint32_t sec)` | 動態更新提醒持續時間 |
| `getNextReminderSec()` | 取得下次提醒倒數（秒） |

提醒蜂鳴使用 `BeepPattern::REMINDER`，`_alertTimeoutMs` 後只停止聲音，狀態仍維持 alerted，直到有效喝水、稍後提醒或暫停。`BEEP_CYCLE_GAP_MS = 800` 為蜂鳴循環間隔。

---

## BuzzerController

**職責**：LEDC PWM 非阻塞蜂鳴佇列，支援最多 6 個 BeepStep 的組合序列。

**位置**：`lib/BuzzerController/`

| 方法 | 說明 |
|---|---|
| `init(uint32_t freqHz, uint8_t volumePct)` | 初始化 LEDC，GPIO 18 |
| `play(BeepPattern pattern)` | 播放預設模式 |
| `update()` | 非阻塞推進蜂鳴佇列 |
| `stop()` | 立即停止 |
| `setFrequency(uint32_t hz)` | 設定基礎頻率 |
| `setVolume(uint8_t pct)` | 設定音量（0–100%） |
| `setDuration(uint32_t ms)` | 設定基礎時長 |
| `isPlaying()` | 是否正在播放 |

**BeepPattern 列表**

| 模式 | 說明 |
|---|---|
| `BOOT_OK` | 開機成功音 |
| `AP_MODE` | AP Mode 啟動提示 |
| `WIFI_CONNECTED` | WiFi 連線成功 |
| `DRINK` | 飲水確認音 |
| `REMINDER` | 喝水提醒音 |
| `ERROR_BEEP` | 錯誤提示音 |
| `CALIBRATION_OK` | 校正完成音 |

---

## DisplayManager

**職責**：SSD1306 OLED（128×32）輪播兩個頁面，60 秒無操作後自動睡眠。

**位置**：`lib/DisplayManager/`

| 方法 | 說明 |
|---|---|
| `init()` | 初始化 ESP-IDF I2C 與 SSD1306；回傳是否成功 |
| `showBootScreen()` | 顯示開機畫面 |
| `showError(const char* msg)` | 顯示錯誤訊息 |
| `showWifiConnecting(const std::string& ssid)` | 顯示 WiFi 連線中畫面 |
| `showAPMode(const std::string& apSsid, const std::string& apPassword, const std::string& ip)` | 顯示 AP Mode 資訊 |
| `showNormalMode(float weightG, bool stable, float todayMl, uint32_t goalMl, uint32_t drinkCount, float lastDrinkMl, uint32_t nextRemSec, bool wifiOk, const std::string& ip, bool ntpSynced)` | 更新 Normal Mode 顯示資料 |
| `wake()` | 喚醒螢幕（重置睡眠計時器） |
| `sleep()` | 立即關閉螢幕 |
| `update()` | 由 `hydracup_control` 呼叫，驅動頁面切換與睡眠邏輯 |
| `isAvailable()` | 回傳 OLED 是否正常初始化 |

**頁面內容**

| 頁 | 顯示內容 |
|----|---|
| 0 | 目前秤重（g）、IP 位址 |
| 1 | 今日飲水進度（ml）、飲水次數、上次飲水量、下次提醒倒數 |

頁面每 4 秒（`PAGE_INTERVAL_MS`）切換一次；60 秒（`SCREEN_ON_DURATION_MS`）無操作後螢幕自動關閉。
文字由內建 5×7 glyph table 繪製至 128×32 framebuffer；I2C 使用 ESP-IDF
`driver/i2c_master.h` master bus/device API，保留 400 kHz 與內部 pull-up 設定。

---

## DiscordNotifier

**職責**：以單一持久 FreeRTOS worker 非同步發送 HTTPS POST。drink/summary 使用高優先
Queue；online 狀態使用可合併的低優先 Queue，不會為每次 POST 配置新 task stack。

**位置**：`lib/DiscordNotifier/`

| 方法 | 說明 |
|---|---|
| `init(AppState& state, const AppConfig& cfg)` | 初始化，設定 AppState 與 AppConfig 引用，檢查 Webhook URL 是否已設定 |
| `notifyOnline(const std::string& ipAddress)` | 裝置上線通知（含 IP） |
| `notifyDrink(float amountMl, float totalMl, uint32_t drinkCount)` | 飲水事件通知（含飲水量、今日總量、次數） |
| `notifyDailySummary(float totalMl, uint32_t drinkCount, const std::string& dateStr)` | 每日摘要通知（回傳是否排程成功） |
| `update()` | 空實作；通知由持久 FreeRTOS worker 處理 |

**安全**：Web UI 回應中，Webhook URL 末尾以 `****` 遮罩。`POST /api/config` 時若 URL 含 `****` 則略過更新，防止誤覆蓋 token。

---

## MqttPublisher

**職責**：使用 ESP-IDF `esp_mqtt_client` 發布目前飲水進度、heartbeat 與事件狀態。
MQTT client 由 ESP-IDF 負責重連；payload 先進入固定大小 queue，再由持久 FreeRTOS worker
呼叫 publish，避免控制 task 直接執行網路操作。

**位置**：`lib/MqttPublisher/`

| 方法 | 說明 |
|---|---|
| `init(AppState& state, const AppConfig& cfg)` | 依設定建立 ESP-IDF MQTT client 與 publish worker |
| `setTimeManager(TimeManager* tm)` | 注入時間來源，讓 payload 可帶 device time |
| `setDailyGoal(uint32_t dailyGoalMl)` | 更新 MQTT payload 使用的每日目標 |
| `loop(float todayTotalMl)` | 由 `hydracup_service` task 呼叫，依 heartbeat 間隔排程狀態發布 |
| `publishStatus(float currentMl, const char* event)` | 將狀態 payload 送入 publish queue |

主要 topic 為 `hydracup/status`；availability 使用 `hydracup/availability`，並以 retained
訊息發布 online／offline 狀態。

---

## OtaUpdater

**職責**：從 GitHub Releases 檢查版本並以 `esp_https_ota` 寫入備用 app slot。

**位置**：`lib/OtaUpdater/`

| 方法 | 說明 |
|---|---|
| `init(AppState& state, RuntimeCoordinator& runtime)` | 建立 `ota_worker` task 與同步物件。只在 Normal Mode 呼叫 |
| `requestCheck()` / `requestUpdate()` | 交給 worker 執行，回傳 `OtaRequestResult`（`ACCEPTED` / `BUSY` / `NO_UPDATE_AVAILABLE` / `INSUFFICIENT_MEMORY` / `OFFLINE`） |
| `snapshot()` | 以 mutex 一次原子取得 `OtaStatus`，供 `/api/ota/status` 序列化 |

worker task 參數：static stack **10,240 bytes**（不是照抄 paper-frame 的 64 KB——ESP32 classic
無 PSRAM，且既有 `cloud_sync` task 以同樣大小跑完整 mbedtls TLS 已穩定）、優先權 **3**
（低於 httpd 的 5，下載期間狀態查詢仍即時）、pin **core 0**、`xTaskCreateStaticPinnedToCore`
（OTA 期間 heap 最緊，不在此時 malloc）。重入以 `std::atomic<bool>` compare-exchange 擋住。

版本檢查讀 `version.txt` 固定資產而非 `api.github.com`：後者未認證時限 60 req/hr/IP，
家用 NAT 下多台裝置會撞牆，且需要 8 KB 靜態 buffer 解析 JSON。

**版本以映像本身為準**：manifest 與韌體資產是對同一個可變的 `latest` 指標發出的兩次請求，
之間可能不一致。因此下載開始後會先用 `esp_https_ota_get_img_desc()` 讀 app descriptor，
必須同時滿足「等於檢查時公告的版本」與「嚴格大於目前執行版本」才繼續寫入，否則 abort。
TLS 與 image header 只證明完整性，不證明身分。

這仰賴 app descriptor 帶有可比對的版本字串：專案根目錄的 `version.txt` 是 ESP-IDF 的
`PROJECT_VER` 來源（優先於 `git describe`），release workflow 直接把同一個檔案當成 manifest
資產發佈，所以 manifest 與映像描述子由建置本身保證一致。`include/version.h` 則是韌體回報
的版本，CI 會檢查兩者與 git tag 三方一致。

**網頁資源更新（v0.7.0 起）**：同一個更新動作在韌體寫入成功後，會用 release 的 `SHA256SUMS`
比對 `hydracup-esp32dev-littlefs.bin` 的雜湊與 NVS（`ota` / `webfs_sha`）記錄的已安裝值，
不同才卸載 `/webfs`、抹除分割區、邊下載邊以 4 KB 寫入並累算 SHA-256，寫完比對相符才記錄新雜湊。

webfs 的下載必須**自行跟隨轉址**：`esp_http_client` 只在 `esp_http_client_perform()` 內處理
301/302，而這裡走的是可邊下載邊寫入的 `open()`／`fetch_headers()`／`read()` 串流流程，
GitHub 的 302 會原封不動回傳。韌體那半不受影響，因為 `esp_https_ota` 內部走會處理轉址的路徑。

webfs 沒有 A/B 備援也放不進 RAM，寫入是就地覆蓋，中途失敗即損毀，需 USB `uploadfs` 復原——
這是明確接受的取捨。順序不可對調（先 webfs 後韌體會留下「網頁比韌體新」的組合），且韌體一旦
寫入成功就一定重新開機，即使 webfs 失敗。不改用「直接雜湊分割區」判斷是否需要更新，因為
LittleFS 執行期間會改寫 metadata，實際位元組會與發佈映像產生落差。

**webfs OTA 的三個缺陷（v0.7.0–v0.7.7）**：這條路徑從加入到真正可用之間修了三次，而且只能
一層一層剝——每一層都被前一層擋住，前一層沒修好就看不見下一層：

| 缺陷 | 修正於 | 症狀 |
|---|---|---|
| 串流路徑不跟隨 302 轉址 | v0.7.2 | 下載從未開始。`esp_http_client` 只在 `esp_http_client_perform()` 內處理轉址，而邊下載邊寫必須用 `open()`／`fetch_headers()`／`read()`，那條路徑會把 GitHub 的 302 原樣回傳。實測需要**兩層**轉址 |
| 寫入前先抹除整片分割區 | v0.7.4 | 抹除 384 KB 需數秒且反覆停用 flash cache，而 lwIP 執行於 flash——剛建立的 TLS 連線在這段期間無人服務，抹完回頭讀已全部逾時。分割區被抹空卻零寫入 |
| 緩衝區配置在 IRAM | **v0.7.7** | **真正的主因。**`MALLOC_CAP_INTERNAL` 只保證「非 PSRAM、cache 關閉時仍可用」，IRAM 完全符合卻只允許 32-bit 對齊存取，第一筆資料 `memcpy` 進去就 `LoadStoreError` panic |

panic 發生在 `esp_https_ota_finish()` 之後，開機分割區已切換，因此韌體照常更新、從外部看就是
「韌體燒完就重開」。診斷靠的是 serial 擷取到的暫存器 dump：`EXCVADDR` 落在 IRAM、長度 `0x1000`
正是 `OTA_WEBFS_CHUNK`、`PC` 在 ROM memcpy。

v0.7.6 曾推測為 OTA task stack 不足而由 10 KB 提高到 16 KB，**那不是原因**——修好之後的 log
顯示 `stack_free=11178`，16 KB 還剩 11 KB。該值保留為餘裕。

姊妹專案 esp32-paper-frame **沒有 webfs OTA**（`components/pf_ota/ota_worker_esp_idf.cpp` 註明
`webfs/imagefs are never touched here`），其網頁資源僅能以 esptool 手動燒錄。上述三個缺陷都是
本專案新增此功能後才出現的，沒有既有實作可對照。

**開機確認（獨立於本類別）**：`ota_boot_check()` / `ota_mark_app_valid_if_due(bool)` 是自由
函式，因為未設定 WiFi 的裝置走 AP Mode、根本不會建立 `OtaUpdater`。若把確認綁在它身上
（或綁在連線狀態上），那些裝置每次開機都會在 30 秒後被 bootloader 回滾。確認條件只有
兩項：uptime 滿 `OTA_MARK_VALID_DELAY_MS`，且控制任務心跳正常。

**併發降載**：更新期間 `AppState::otaInProgress` 為 true，各模組自行輪詢降載——控制任務
跳過 `drinkDetector.update()`（保留 `scaleManager` 讀取，維持重量顯示）、`cloud_sync` 與
`discord_worker` 暫停（各自的 TLS session 約 40 KB heap）、MQTT 心跳暫停。`esp_ota_write()`
期間兩顆 core 的 flash cache 會被停用，HX711 的 bit-bang 讀值會失真，寧可漏記也不要記入
假事件。

---

## EventLogger

**職責**：將每次飲水事件以 JSONL 格式追加至 logfs 分割區，依月份分檔案。

**位置**：`lib/EventLogger/`

| 方法 | 說明 |
|---|---|
| `init(bool fsOk)` | 初始化 logfs 狀態、檔案 mutex、queue 與 worker |
| `logDrink(const std::string& ts, float amountMl, float totalMl, TimeManager* tm)` | 將飲水記錄送入非同步 log queue |

日誌格式與路徑規則見 [data-formats.md](data-formats.md)。

---

## TimeManager

**職責**：透過 ESP-IDF `esp_sntp_*` API 進行 NTP 時間同步與時戳產生，每 12 小時重新同步
防止漂移。未同步時以 `hal_millis()` 回退。

**位置**：`lib/TimeManager/`

| 方法 | 說明 |
|---|---|
| `init(const AppConfig& cfg)` | 設定 NTP 伺服器與時區偏移，開始同步 |
| `update()` | 每 12 小時（`RESYNC_INTERVAL_MS`）重新同步 NTP |
| `isSynced()` | 是否已完成 NTP 同步 |
| `getLocalTm(struct tm& t)` | 取得本地時間結構（失敗回傳 false） |
| `getISOTimestamp()` | 取得 ISO-8601 時間戳（含時區偏移）；未同步時回傳 `"boot+<ms>ms"` |
| `getYearMonth()` | 取得 `"YYYY-MM"` 格式字串（用於日誌路徑）；未同步時回傳 `"unsynced"` |
| `getDateString()` | 取得 `"YYYY-MM-DD"` 格式字串；未同步時回傳空字串 |

時區偏移由 `timezoneOffsetSec`（預設 +28800，即 UTC+8）與 `daylightOffsetSec`（預設 0）組合而成。

---

## DailySummaryManager

**職責**：偵測每日午夜（00:00）時刻，呼叫 `DrinkDetector.resetDailyCounters()` 並透過 `DiscordNotifier` 發送當日總結。

**位置**：`lib/DailySummaryManager/`

| 方法 | 說明 |
|---|---|
| `init(DiscordNotifier& discord, DrinkDetector& detector, TimeManager& time, const AppConfig& cfg)` | 初始化四個依賴模組 |
| `update()` | 由 `hydracup_control` 呼叫，以非阻塞 settlement stages 推進每日摘要 |

午夜摘要包含：當日總飲水量、飲水次數、相對每日目標的達成率。

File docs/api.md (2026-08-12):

# REST API Reference

## 共通規則

- 所有端點回應 JSON
- 成功：`{"ok": true, ...}`
- 失敗：`{"ok": false, "error": "<message>"}`
- Normal Mode 的頁面與資料 API 需要登入；未登入頁面回到 `/login`，未登入 API 回 `401`
- 狀態變更的 `POST` API 需要 `X-CSRF-Token`；登入前使用每次開機的 token，登入後使用 session 綁定 token
- session 是裝置端單一有效 session，新登入會取代舊 session；idle timeout 30 分鐘、absolute timeout 24 小時
- 管理密碼以 PBKDF2-HMAC-SHA256 雜湊儲存，不會由 API 回傳
- 目前 WebUI 使用 HTTP；同網段主動攻擊者仍可能攔截並重放密碼、session 或 CSRF token，建議限制在信任的隔離 LAN
- 埠號：80

---

## DashboardServer（Normal Mode）

Normal Mode 下運行，ESP32 連上 WiFi 後提供。

### 靜態頁面

| 方法 | 路徑 | 說明 |
|---|---|---|
| GET | `/` | 儀表板首頁（`index.html`） |
| GET | `/settings` | 設定頁面（`settings.html`） |
| GET | `/history` | 飲水歷史頁面（`history.html`） |
| GET | `/login` | 登入／首次設定管理密碼 |
| GET | `/style.css` | 共用樣式表 |
| GET | `/ui.js` | 共用主題與 session 輔助腳本 |
| GET | `/favicon.svg` | HydraCup favicon |
| GET | `/calibration` | 重定向至 `/settings#calibration` |

### 認證端點

#### `GET /api/auth/csrf`

取得登入頁或已登入 session 使用的 CSRF token。回應包含 `configured` 與
`authenticated` 狀態；token 僅應由同源前端放入 `X-CSRF-Token` header。

#### `POST /api/auth/login`

首次尚未設定管理密碼時，body 必須包含相同的 `password`／`confirm`，且密碼至少 8 個字元；
已設定密碼時只驗證 `password`。成功後回傳 `session` HttpOnly cookie。

#### `POST /api/auth/password`

需要已登入 session 與 CSRF token，**並在 body 提供目前密碼**——session 本身不足以授權變更
憑證，再驗一次是為了讓「沒關掉的分頁」無法被轉換成永久存取權。

```json
{"current": "...", "next": "...", "confirm": "..."}
```

新密碼至少 8 個字元、最多 128 bytes，且 `next` 與 `confirm` 必須相同（以 constant-time 比對）。

成功後**會結束目前的 session** 並清除 cookie，回傳 `{"ok": true, "state": "reauth_required"}`，
需以新密碼重新登入。裝置只保留單一 session slot，留著舊 session 等於讓它活得比產生它的憑證還久。

| 狀態 | 錯誤 | 條件 |
|---|---|---|
| 401 | `invalid_credentials` | 目前密碼錯誤。失敗計入與登入共用的 IP 鎖定 |
| 429 | `rate_limited` | 嘗試次數過多 |
| 400 | `weak_or_mismatched_password` | 新密碼過短、過長或兩次輸入不符 |
| 500 | `password_persist_failed` | 寫入 NVS 失敗。**舊密碼仍然有效**，不會把裝置鎖死 |

#### `POST /api/auth/logout`

需要已登入 session 與 CSRF token；伺服器端會撤銷唯一有效 session。

---

### `GET /api/weight`

取得目前秤重與杯子狀態。

**回應**

```json
{
  "ok": true,
  "weight_g": 342.5,
  "cup_state": 2
}
```

| 欄位 | 型別 | 說明 |
|---|---|---|
| `weight_g` | float | 目前重量（公克） |
| `cup_state` | int | 杯子狀態代碼（見下表） |

**cup_state 代碼**

| 值 | 名稱 | 說明 |
|----|---|---|
| 0 | `no_cup` | 無杯子 |
| 1 | `unstable` | 不穩定 |
| 2 | `stable` | 穩定 |
| 3 | `possible_drink` | 可能正在喝 |
| 4 | `drink_confirmed` | 飲水確認 |
| 5 | `refill_detected` | 補水確認 |

---

### `GET /api/status`

取得完整系統狀態快照。由 `index.html` 每 2 秒輪詢。

**回應**

```json
{
  "ok": true,
  "mode": "normal",
  "wifi_connected": true,
  "ip": "192.168.1.100",
  "ntp_synced": true,
  "weight_g": 342.5,
  "cup_state": 2,
  "cup_state_name": "stable",
  "today_total_ml": 1250.0,
  "daily_goal_ml": 2000,
  "drink_count_today": 5,
  "last_drink_ml": 230.0,
  "next_reminder_sec": 1800,
  "cloud_history_backfill_state": "complete",
  "cloud_history_backfill_running": false,
  "cloud_history_backfill_uploaded_days": 45,
  "cloud_history_backfill_http_status": 200,
  "webhook_configured": true,
  "webhook_last_ok": true,
  "discord_worker_ready": true,
  "discord_queue_drops": 0,
  "hw_hx711": true,
  "hw_oled": true,
  "hw_fs": true,
  "hw_logfs": true,
  "rtos": true,
  "rtos_healthy": true,
  "rtos_sequence": 8124,
  "rtos_command_drops": 0,
  "rtos_result_drops": 0,
  "log_queue_drops": 0
}
```

| 欄位 | 型別 | 說明 |
|---|---|---|
| `mode` | string | `"normal"` 或 `"ap"` |
| `wifi_connected` | bool | WiFi 連線狀態 |
| `ip` | string | 目前 IP 位址 |
| `ntp_synced` | bool | NTP 時間同步狀態 |
| `weight_g` | float | 目前重量（g） |
| `cup_state` | int | 杯子狀態代碼 |
| `cup_state_name` | string | 杯子狀態名稱 |
| `today_total_ml` | float | 今日累計飲水量（ml） |
| `daily_goal_ml` | uint32 | 每日目標飲水量（ml） |
| `drink_count_today` | uint32 | 今日飲水次數 |
| `last_drink_ml` | float | 上次飲水量（ml） |
| `next_reminder_sec` | uint32 | 下次提醒倒數（秒） |
| `cloud_history_backfill_state` | string | `idle`、`queued`、`uploading`、`retrying` 或 `complete` |
| `cloud_history_backfill_running` | bool | 歷史補傳背景工作是否仍會繼續 |
| `cloud_history_backfill_uploaded_days` | uint32 | 本次開機／工作已由 service 確認的日期數 |
| `cloud_history_backfill_http_status` | int | 最近一次歷史補傳 HTTP status；尚未送出為 0 |
| `webhook_configured` | bool | Webhook URL 已設定 |
| `webhook_last_ok` | bool | 最後一次 Webhook 是否成功 |
| `discord_worker_ready` | bool | 持久 Discord worker 已建立 |
| `discord_queue_drops` | uint32 | Discord Queue 滿或不可用的累計丟棄數 |
| `hw_hx711` | bool | HX711 初始化成功 |
| `hw_oled` | bool | OLED 初始化成功 |
| `hw_fs` | bool | webfs 初始化成功 |
| `hw_logfs` | bool | logfs 初始化成功 |
| `rtos` | bool | control task 已啟動 |
| `rtos_healthy` | bool | 最近 2 秒內收到 control heartbeat |
| `rtos_sequence` | uint32 | runtime snapshot 發布序號 |
| `rtos_command_drops` | uint32 | control command Queue 滿的累計次數 |
| `rtos_result_drops` | uint32 | command result Queue 滿的累計次數 |
| `log_queue_drops` | uint32 | 非同步飲水 log 無法排入/寫入的累計次數 |

---

### `GET /api/config`

取得所有設定值。密碼與 Webhook URL 已遮罩。

**回應**

```json
{
  "ok": true,
  "wifiSsid": "MyWiFi",
  "wifiPassword": "****",
  "wifiPasswordSet": true,
  "discordWebhookUrl": "https://discord.com/api/webhooks/123/****",
  "reminderEnabled": true,
  "reminderIntervalMin": 60,
  "reminderAlertTimeoutSec": 60,
  "dailyGoalMl": 2000,
  "buzzerEnabled": true,
  "buzzerFrequencyHz": 2000,
  "buzzerDurationMs": 150,
  "buzzerVolumePercent": 50,
  "ntpEnabled": true,
  "ntpServer1": "pool.ntp.org",
  "ntpServer2": "time.google.com",
  "timezone": "Asia/Taipei",
  "calibrationFactor": 427.5,
  "cupPresentThresholdGram": 80.0,
  "stableToleranceGram": 3.0,
  "stableDurationMs": 3000,
  "minDrinkDeltaMl": 20.0,
  "maxDrinkDeltaMl": 500.0
}
```

---

### `POST /api/config`

儲存設定。若 `wifiPassword` 或 `discordWebhookUrl` 包含 `"****"` 則略過更新（防誤覆蓋）。

**請求 Body（JSON，所有欄位可選）**

```json
{
  "dailyGoalMl": 2500,
  "reminderEnabled": true,
  "reminderIntervalMin": 45,
  "reminderAlertTimeoutSec": 30,
  "buzzerEnabled": true,
  "buzzerFrequencyHz": 2000,
  "buzzerDurationMs": 150,
  "buzzerVolumePercent": 70,
  "ntpEnabled": true,
  "ntpServer1": "pool.ntp.org",
  "ntpServer2": "time.google.com",
  "timezone": "Asia/Taipei",
  "wifiSsid": "MyWiFi",
  "wifiPassword": "newpassword",
  "discordWebhookUrl": "https://discord.com/api/webhooks/.../token",
  "cupPresentThresholdGram": 80.0,
  "stableToleranceGram": 3.0,
  "stableDurationMs": 3000,
  "minDrinkDeltaMl": 20.0,
  "maxDrinkDeltaMl": 500.0
}
```

WiFi、NTP、MQTT 或進階感測器設定有異動時，回應會要求重新啟動。

**回應**

```json
{
  "ok": true,
  "reboot_required": true,
  "control_applied": true
}
```

`reboot_required` 為 `true` 表示至少一項設定需重啟後完整套用；`control_applied`
表示 daily goal、reminder 與 buzzer 的即時 control commands 都已成功處理。

---

### `POST /api/tare`

歸零由 `hydracup_control` 收集 10 筆 tare 樣本，再等待 10 筆 warm-up 樣本。HTTP handler
最多等待 4.5 秒；
執行期間再次要求會回傳 `409`，尚未暖機回傳 `503`。

秤重歸零（Tare）。將目前重量設為 0 基準點並儲存偏移至 NVS。

**請求 Body**：無

**回應**

```json
{"ok": true}
```

---

### `POST /api/calibrate`

以已知重量校正感測器。校正係數（`calibrationFactor`）儲存至 NVS。

**請求 Body**

```json
{"known_weight_g": 200.0}
```

**回應**

```json
{
  "ok": true,
  "calibration_factor": 427.53,
  "current_weight_g": 200.1
}
```

---

### `GET /api/wifi/scan`

掃描附近 WiFi 網路。

**回應**

```json
{
  "ok": true,
  "networks": [
    {"ssid": "MyWiFi", "rssi": -45, "secure": true},
    {"ssid": "GuestNet", "rssi": -72, "secure": false}
  ]
}
```

---

### `GET /api/logs`

取得指定月份的飲水記錄。

**查詢參數**

| 參數 | 說明 |
|---|---|
| `month` | 格式 `YYYY-MM`（例：`2025-02`）；或 `"unsynced"`（NTP 未同步期間的記錄） |

**回應**

```json
{
  "ok": true,
  "month": "2025-02",
  "entries": [
    {"ts": "2025-02-18T14:30:45+08:00", "ml": 250.0, "total": 1500.0},
    {"ts": "2025-02-18T15:45:20+08:00", "ml": 180.0, "total": 1680.0}
  ],
  "skipped": 0
}
```

| 欄位 | 說明 |
|---|---|
| `entries[].ts` | ISO-8601 時間戳（含時區偏移） |
| `entries[].ml` | 本次飲水量（ml） |
| `entries[].total` | 當日累計飲水量（ml） |
| `skipped` | 無法解析的行數（JSONL 損毀行） |

---

### `POST /api/reboot`

重啟裝置。

**回應**

```json
{"ok": true}
```

---

### `POST /api/cloud/history-backfill`

需要登入與 CSRF token。建立可跨重啟續傳的背景工作，逐月讀取 `/logfs/logs`，只把今天
以前的每日累計量、飲水次數與最後飲水時間送到已設定的 HydraCup Service。重複呼叫進行中
的工作不會重設游標；完成後再次呼叫會從頭安全重送。

成功排入回 `202`：

```json
{"ok": true, "state": "queued"}
```

logfs 不可用回 `503 logfs_unavailable`；Cloud sync 未完整設定回
`409 cloud_not_configured`。執行狀態由 `GET /api/status` 查詢。

---

### `POST /api/logs/clear`

需要登入與 CSRF token，**並在 body 再次提供管理密碼**。session 本身不足以授權這個操作，
因為它無法復原。

```json
{"password": "..."}
```

**這個端點不會當場清除任何東西。** 它只把要求記在 NVS，回應後重新啟動；真正的清除發生在
下次開機、掛載檔案系統之前。回應為 `{"ok": true, "state": "restarting"}`。

清除內容：格式化整個 `logfs`（飲水月檔 `/logfs/logs/drink-*.jsonl` 與尚未上傳的同步佇列
`/logfs/cloud/outbox.jsonl`）、NVS `drink_ctr` 的今日累計與飲水次數、以及 `cloud_sync` 的
`evt_overflow` 溢位暫存（留著會把剛刪掉的事件放回佇列）。

**不會**刪除已同步到雲端的資料，也不動 `cloud_sync` 的 sequence 狀態、校正值、WiFi 或其他設定。

| 狀態 | 錯誤 | 條件 |
|---|---|---|
| 401 | `invalid_credentials` | 密碼錯誤、未設定或超過 128 bytes。失敗計入與登入相同的鎖定機制 |
| 429 | `rate_limited` | 密碼嘗試次數過多 |
| 409 | `history_backfill_in_progress` | 歷史補傳進行中——它會在回應與重開機之間繼續上傳並推進 cursor，而那些歷史即將消失 |
| 500 | `request_not_stored` | 要求無法寫入 NVS，**沒有排定任何清除** |

#### 為什麼在開機時清除

在系統運行中清除，等於要和每一個正在寫入這些資料的來源賽跑：EventLogger 佇列中的事件
（包含已出佇列、正等待檔案系統鎖的那一筆）、計數器儲存的佇列與重試路徑、開機時仍在讀取
舊值的 NVS restore，以及 Cloud sync 在鎖內讀出、鎖外送出的批次。每一項都需要各自的屏障，
而檔案清除與計數清除之間仍然無法對「剛好在此時發生的一次飲水」保持原子性。

開機時這些都還不存在——沒有任何 task 被建立、分割區也尚未掛載，清除因此是一條沒有併發的
直線。`/logfs/logs` 與 `/logfs/cloud` 由 `EventLogger` 與 `CloudSyncClient` 在同一次開機的
初始化中重建，不需要額外處理。

執行順序為 **NVS 計數先、logfs 格式化後**，讓不可逆的一步排在最後：計數抹除失敗就直接中止，
此時一個位元組都還沒被刪；格式化失敗則計數已歸零但月檔仍在。兩種情況下要求旗標都會保留，
下次開機重跑一次。旗標**最後才清除**，因此中途斷電也只是再跑一次，不會回報一個沒做到的成功。

已知取捨：旗標清除失敗（NVS 持續性故障）時每次開機都會重新格式化一次 logfs。這是更深層的
硬體問題，且格式化是冪等的、log 會明確指出，因此不另設重試上限。

---

### `GET /api/ota/status`

需要登入。回傳韌體更新的完整狀態快照。只在 Normal Mode 下註冊；AP Mode 沒有外網，
`OtaUpdater` 不會建立，此時回 `503 ota_unavailable`。

```json
{
  "ok": true,
  "check_state": "update_available",
  "update_state": "idle",
  "running_version": "0.6.0",
  "latest_version": "0.6.1",
  "running_partition": "app0",
  "progress_percent": 0,
  "image_size": 0,
  "bytes_read": 0,
  "last_http_status": 200,
  "message": "有新版本 0.6.1 可更新",
  "pending_verify": false
}
```

| 欄位 | 說明 |
|---|---|
| `check_state` | `unknown` / `checking` / `up_to_date` / `update_available` / `check_failed` |
| `update_state` | `idle` / `downloading` / `writing` / `ready_pending_reboot` / `failed` |
| `stage` | 更新期間指出正在處理哪一段：`firmware` 或 `webfs` |
| `last_outcome` | 最後一次更新的結果，存於 NVS 因此**跨重開機保留**。更新以重開機收尾，`message` 只存在約 2.5 秒，沒有這個欄位就查不到究竟發生了什麼 |
| `message` | 面向使用者的中文說明，**由韌體產生**。裝置可能處於「UI 比韌體舊」的狀態（webfs 寫入被跳過或失敗、或以 USB 燒入舊映像），舊版 UI 必須能顯示新韌體的狀態與錯誤，因此前端只做渲染、不自行組字串 |
| `pending_verify` | 目前執行的映像尚未確認。控制任務持續心跳滿 30 秒後自動確認；在此之前重新開機會回滾到前一個 slot |

此端點的 JSON 欄位**只增不改**——移除或改名會讓尚未以 USB 更新 web 資產的裝置顯示錯誤。

---

### `POST /api/ota/check`

需要登入與 CSRF token。向 GitHub Releases 查詢最新版本（`version.txt` 固定資產），
與韌體內的 `APP_VERSION` 做 SemVer 比對，只有**嚴格大於**才視為有更新。

成功回 `200 {"ok": true, "state": "checking"}`。實際結果由 `GET /api/ota/status` 查詢。

進行中回 `409 ota_busy`；未連上 WiFi 回 `503 offline`。

---

### `POST /api/ota/update`

需要登入與 CSRF token。單一動作依序處理韌體與網頁資源，完成後約 2.5 秒自動重新開機。
必須先呼叫 `/api/ota/check` 且結果為 `update_available`。

順序為**先韌體、後 webfs**：韌體失敗則整個更新中止且 webfs 未被觸碰；反過來做，失敗時會留下
「網頁比韌體新」的組合，而相容性契約只保證反向。webfs 僅在 `SHA256SUMS` 取得成功、且其雜湊
與 NVS 記錄的已安裝值不同時才會重寫。

**webfs 沒有備援分割區**，寫入是就地覆蓋，中途失敗會使靜態頁面損毀，需以
`pio run -e esp32dev --target uploadfs` 復原。此時 `/api/*` 仍可正常運作。

成功排入回 `202`：

```json
{"ok": true, "state": "queued"}
```

| 狀態 | 錯誤 | 條件 |
|---|---|---|
| 409 | `ota_busy` | 已有檢查或更新進行中 |
| 409 | `no_update_available` | 尚未檢查，或目前已是最新版 |
| 503 | `insufficient_memory` | 內部可用 heap 低於 60 KB。寧可拒絕，也不要在寫入途中 OOM 而留下半寫入的 slot |
| 503 | `offline` | 未連上 WiFi |

更新期間裝置會主動降載：暫停飲水事件判定、Cloud sync、Discord 通知與 MQTT 心跳
（詳見 `docs/architecture.md`）。失敗不影響目前執行的韌體，可直接重試。

---

## ConfigPortal（AP Mode）

AP Mode 下（WiFi 未設定或連線失敗）運行，固定位址 `192.168.4.1`。首次尚未設定管理
密碼時可直接設定 WiFi；已有管理密碼的 recovery AP 必須先登入，才能掃描或修改設定。

### `GET /`

提供 WiFi 設定頁面 HTML。

---

### `GET /api/status`

已有管理密碼時需要有效 session；首次 provisioning 可直接讀取。

**回應**

```json
{
  "ok": true,
  "mode": "ap",
  "ap_ssid": "WaterCupTracker-Setup",
  "ap_ip": "192.168.4.1"
}
```

---

### `POST /api/config`

需要 `X-CSRF-Token`；已有管理密碼時另外需要有效 session。

儲存 WiFi 憑證並觸發重啟。

**請求 Body**

```json
{
  "wifi_ssid": "MyWiFi",
  "wifi_password": "mypassword"
}
```

**回應**

```json
{"ok": true}
```

---

### `GET /api/wifi/scan`

掃描附近 WiFi 網路（格式同 DashboardServer）；已有管理密碼時需要有效 session。

---

### `POST /api/reboot`

重啟裝置（格式同 DashboardServer），需要 `X-CSRF-Token`；已有管理密碼時另外需要有效
session。

---

## curl 範例

以下 Normal Mode 範例假設已登入，`cookies.txt` 內有 `session` cookie，並將
`<session-csrf-token>` 替換成 `GET /api/auth/csrf` 回傳的 session token。

```bash
# 查看系統狀態
curl -b cookies.txt http://192.168.1.100/api/status

# 秤重歸零
curl -b cookies.txt -H "X-CSRF-Token: <session-csrf-token>" \
  -X POST http://192.168.1.100/api/tare

# 以 200g 物品校正
curl -b cookies.txt -H "X-CSRF-Token: <session-csrf-token>" \
  -X POST -H "Content-Type: application/json" \
  -d '{"known_weight_g": 200.0}' \
  http://192.168.1.100/api/calibrate

# 更新每日目標
curl -b cookies.txt -H "X-CSRF-Token: <session-csrf-token>" \
  -X POST -H "Content-Type: application/json" \
  -d '{"dailyGoalMl": 2500}' \
  http://192.168.1.100/api/config

# 查看本月記錄
curl -b cookies.txt "http://192.168.1.100/api/logs?month=2025-02"
```

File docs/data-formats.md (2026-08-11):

# Data Formats

## JSONL 飲水日誌

### 檔案位置

```
logfs partition (0x2F0000, 1 MB)
└── /logs/
    ├── drink-2025-01.jsonl
    ├── drink-2025-02.jsonl
    ├── drink-unsynced.jsonl    ← NTP 未同步期間
    └── ...
```

路徑規則：`/logs/drink-<YYYY-MM>.jsonl`，月份由 `TimeManager.getYearMonth()` 取得。  
若 NTP 未同步，所有記錄寫入 `drink-unsynced.jsonl`。

### 格式

每筆飲水事件佔一行（JSON Lines，`\n` 分隔），UTF-8 無 BOM。

```json
{"ts":"2025-02-18T14:30:45+08:00","ml":250.0,"total":1500.0}
```

| 欄位 | 型別 | 說明 |
|---|---|---|
| `ts` | string | ISO-8601 時間戳，含時區偏移（NTP 同步後）；未同步時為 `"boot+<ms>ms"` 格式（例：`"boot+12345ms"`） |
| `ml` | number | 本次飲水量（毫升）；格式為無小數整數（`%.0f`） |
| `total` | number | 當日累計飲水量（ml）；格式為無小數整數（`%.0f`） |

### 範例

```jsonl
{"ts":"2025-02-18T08:10:22+08:00","ml":185.0,"total":185.0}
{"ts":"2025-02-18T10:33:05+08:00","ml":230.0,"total":415.0}
{"ts":"2025-02-18T12:58:47+08:00","ml":310.0,"total":725.0}
{"ts":"2025-02-18T15:20:11+08:00","ml":200.0,"total":925.0}
```

### 注意事項

- 追加寫入（`FILE_APPEND`），不覆寫
- `logfs` mount 使用 `format_if_mount_failed = false`；首次未格式化或損毀時不會自動清除資料
- `uploadfs` 指令只觸及 `webfs`，不影響日誌資料
- `/api/logs?month=YYYY-MM` 可透過 Web API 讀取全月記錄
- `skipped` 欄位回報無法解析的損毀行數

---

## NVS Schema

ESP-IDF `nvs_flash` 儲存於 NVS flash 分割區（0x9000，20 KB）。`ConfigManager` 使用
`nvs_open()`、`nvs_get_*()`、`nvs_set_*()` 與 `nvs_commit()` 管理資料；所有存取都由
`StorageLock` 序列化。

### 命名空間：`water_config`

由 `ConfigManager` 管理，對應 `AppConfig` 結構體的所有欄位。

| NVS Key | 型別 | 預設值 | 對應 AppConfig 欄位 |
|---|---|---|---|
| `wifi_ssid` | string | `""` | `wifiSsid` |
| `wifi_pass` | string | `""` | `wifiPassword` |
| `webhook_url` | string | `""` | `discordWebhookUrl` |
| `rem_en` | u8 | `1` | `reminderEnabled` |
| `rem_interval` | u32 | `60` | `reminderIntervalMin` |
| `rem_alert_to` | u32 | `60` | `reminderAlertTimeoutSec` |
| `daily_goal` | u32 | `2000` | `dailyGoalMl` |
| `buz_en` | u8 | `1` | `buzzerEnabled` |
| `buz_freq` | u32 | `2000` | `buzzerFrequencyHz` |
| `buz_dur` | u32 | `150` | `buzzerDurationMs` |
| `buz_vol` | u32 | `50` | `buzzerVolumePercent` |
| `ntp_en` | u8 | `1` | `ntpEnabled` |
| `ntp_srv1` | string | `"pool.ntp.org"` | `ntpServer1` |
| `ntp_srv2` | string | `"time.google.com"` | `ntpServer2` |
| `tz` | string | `"Asia/Taipei"` | `timezone` |
| `tz_off` | i32 | `28800` | `timezoneOffsetSec` |
| `dst_off` | i32 | `0` | `daylightOffsetSec` |
| `mqtt_en` | u8 | `0` | `mqttEnabled` |
| `mqtt_host` | string | `""` | `mqttBrokerHost` |
| `mqtt_port` | u32 | `1883` | `mqttBrokerPort` |
| `mqtt_user` | string | `""` | `mqttUsername` |
| `mqtt_pass` | string | `""` | `mqttPassword` |
| `mqtt_cid` | string | `"hydracup-device"` | `mqttClientId` |
| `mqtt_hb` | u32 | `60` | `mqttHeartbeatSec` |
| `cal_factor` | blob(float) | `1.0` | `calibrationFactor` |
| `tare_offset` | i32 | `0` | `tareOffset` |
| `cup_thresh` | blob(float) | `80.0` | `cupPresentThresholdGram` |
| `stable_tol` | blob(float) | `3.0` | `stableToleranceGram` |
| `stable_dur` | u32 | `3000` | `stableDurationMs` |
| `min_drink` | blob(float) | `20.0` | `minDrinkDeltaMl` |
| `max_drink` | blob(float) | `500.0` | `maxDrinkDeltaMl` |
| `ap_ssid` | string | `"WaterCupTracker-Setup"` | `apSsid` |
| `ap_pass` | string | `"12345678"` | `apPassword` |
| `admin_hash` | string | `""` | `adminPasswordHash` |

### 命名空間：`drink_ctr`

由 `DrinkDetector` 管理，用於跨重啟持久化每日計數器。

| NVS Key | 型別 | 說明 |
|---|---|---|
| `period` | string | 目前計數的日期（`YYYY-MM-DD`） |
| `total_ml` | blob(float) | 當日累計飲水量（ml） |
| `count` | u32 | 當日飲水次數 |
| `last_ml` | blob(float) | 上次飲水量（ml） |

**日期重置機制**：NTP 同步後，`DrinkDetector` 比對 `period` 欄位與目前日期。相同日期
會還原計數；不同日期會先把舊數據留在 RAM，交由 `DailySummaryManager` 聚合，之後由
`resetDailyCounters()` 清零並以新日期寫入 NVS。沒有既有資料時會建立當日的零值紀錄。

### 命名空間：`cloud_sync`

除 durable event sequence、command ledger 與緊急 overflow 外，歷史補傳使用以下游標：

| NVS Key | 型別 | 說明 |
|---|---|---|
| `hist_active` | u8 | `1` 表示補傳工作尚未完成；重開後自動繼續 |
| `hist_cursor` | string | service 已確認完成的最後月份（`YYYY-MM`） |
| `hist_identity` | string | Service origin、device ID 與 token 的 SHA-256；身分變更時游標失效 |

游標只在 service 回覆批次接受天數符合 request 後前進，且只適用於相同 cloud identity。
每日內容由月檔內同日最大的
`total`、有效行數與最晚 `ts` 組成；`drink-unsynced.jsonl` 不補傳，當日也延後到隔日
重新執行時才會納入。

---

## Flash 分割表

來源：`partitions.csv`

| 名稱 | 標籤 | 型別 | 偏移 | 大小 | 說明 |
|---|---|---|---|---|---|
| nvs | nvs | data | 0x9000 | 20 KB | WiFi 憑證 + AppConfig（NVS） |
| otadata | ota | data | 0xe000 | 8 KB | OTA 狀態 |
| app0 | ota_0 | app | 0x10000 | 1.3 MB | 韌體 A（主要） |
| app1 | ota_1 | app | 0x150000 | 1.3 MB | 韌體 B（OTA 備份） |
| **webfs** | spiffs | data | 0x290000 | 384 KB | 靜態 Web 資源（`data/`） |
| **logfs** | — | data | 0x2F0000 | 1 MB | 飲水事件 JSONL 日誌 |

`uploadfs` 目標只燒錄 `webfs`（0x290000）；`logfs` 不受影響。

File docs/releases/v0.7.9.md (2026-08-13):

# HydraCup v0.7.9

## STA 連線改為重試三次才退回 AP mode

`connectSTA()` 原本只嘗試一次，10 秒逾時就直接啟動設定入口。重置後存取點通常還沒釋放前一次
關聯，因此在一個其實幾秒後就連得上的網路上，單次嘗試經常失敗。

實際造成的困擾不只是「要多按一次 reset」：

1. 更新完成後裝置自動重開，若剛好落入 AP mode，使用者會以為更新失敗
2. 使用者手動 reset 以恢復連線
3. 新韌體此時處於 `pending verification`，需要控制任務健康運行滿 30 秒才會被標記有效
4. 手動 reset 若發生在 30 秒內，bootloader 判定新韌體未通過驗證，**回滾到舊版**

實測中這個組合連續造成兩次非預期的版本回滾。現在改為最多嘗試 `WIFI_STA_ATTEMPTS`（3）次、
每次間隔 `WIFI_STA_RETRY_GAP_MS`（2 秒），全部失敗才退回 AP mode。

代價是網路真的消失時，退回設定入口最多延後約 34 秒。常見情況（重置後的暫時性失敗）第二次
嘗試就會成功。

## 不調整 rollback 的 30 秒確認視窗

該視窗的用途是偵測「新韌體會在開機時崩潰」，縮短它會削弱保護。而且它在先前的回滾中其實
**做了正確的事**——當時 v0.7.7 確實 panic 了，只是 panic 發生在 webfs 寫入而非開機路徑，
rollback 無法分辨兩者。

確認條件本身也不需要改：它只檢查 uptime 與控制任務心跳，**不檢查 WiFi 或模式**，AP mode
一樣會完成確認。這是刻意的設計——未設定 WiFi 的裝置永遠在 AP mode，若把連線納入條件，
那些裝置會每次開機都被回滾。

## 驗證

- `pio run -e esp32dev`
- `pio test -e native`

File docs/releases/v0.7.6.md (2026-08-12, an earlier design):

# HydraCup v0.7.6

## OTA task stack 由 10 KB 提高到 16 KB

v0.7.5 的更新中，韌體正常寫入，狀態顯示「開始更新網頁資源 · 0%」後裝置立刻重新開機，
webfs 未被更新也未被寫壞，而重開後 `last_outcome` 是空字串。

`saveLastOutcome()` 在正常路徑的最後才執行，沒有值代表**那段程式碼沒有被執行到**；正常路徑
還會在最終訊息停留 2.5 秒，而使用者並未看到。三項合起來指向：`_updateWebfs()` 開始後隨即崩潰。

最可能的位置是 `esp_http_client_open()` 內的 TLS handshake——那是整段流程中 stack 用量最深的
一點，而且緊接在韌體那次 TLS session 拆除之後。

原本 10 KB 的依據是「既有 `cloud_sync` task 以同樣大小跑完整 mbedtls TLS 已穩定」，但這個類比
並不成立：`cloud_sync` 一次只有一個 session，而 OTA task 在同一次執行中要建立**兩個**——韌體
一個、網頁資源一個——並且還要做 raw partition 寫入。姊妹專案 esp32-paper-frame 的 OTA worker
用 16 KB，而它**完全不碰 webfs**，做的事嚴格更少。

`CONFIG_FREERTOS_CHECK_STACKOVERFLOW_CANARY=y` 已啟用，因此若真為 stack 溢位，serial 會直接
指名 `ota_worker`。

## 診斷輸出

- `_updateWebfs()` 在關鍵步驟印出 log，包含每次轉址的狀態碼、content-length 與當下的
  stack 餘裕，崩潰時可從 serial 直接看出停在哪一步
- 開機時印出 `esp_reset_reason()`——正常 `esp_restart()` 與 panic／watchdog 從外部看完全相同，
  裝置都只是「換了版本重新出現」

## 參考：paper-frame 沒有 webfs OTA

`components/pf_ota/ota_worker_esp_idf.cpp` 明確註明 `webfs/imagefs are never touched here`，
其網頁資源僅能以 esptool 手動燒錄。轉址、抹除時序、raw partition 串流寫入這些問題，
都是 hydracup 自行新增此功能後才出現的，沒有既有實作可對照。

## 驗證

- `pio run -e esp32dev`
- `pio test -e native`

本版需由 v0.7.6 執行更新才能驗證 stack 是否為真正原因。

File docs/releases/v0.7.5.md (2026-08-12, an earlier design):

# HydraCup v0.7.5

## 新增：從設定頁變更管理密碼

設定頁新增「09 變更管理密碼」。需要已登入 session 與 CSRF token，**並再次輸入目前密碼**——
session 本身不足以授權變更憑證，再驗一次是為了讓「沒關掉的分頁」無法被轉換成永久存取權。
驗證失敗計入與登入端點共用的 IP 鎖定。

新密碼至少 8 個字元、最多 128 bytes，兩次輸入以 constant-time 比對。變更成功後**會結束目前
的 session**，需以新密碼重新登入——裝置只保留單一 session slot，留著舊 session 等於讓它活得
比產生它的憑證還久。

寫入 NVS 失敗時會還原原本的雜湊，**舊密碼仍然有效**，不會把裝置鎖死。

## 同時驗證 v0.7.4 的邊抹邊寫修正

OTA 下載程式碼的修正，必須讓裝置「已經在跑」該版本、再更新到下一版才會執行——因為執行下載的
永遠是裝置上原本的韌體，而不是被下載的那一份。裝置目前跑 v0.7.4，所以更新到本版時，
`_updateWebfs()` 走的才是 v0.7.4 的邊抹邊寫流程。

本版新增的功能都在 `DashboardServer`，不觸及 OTA 下載路徑，因此不影響這項驗證。

| 版本 | 修正 | 生效條件 | 結果 |
|---|---|---|---|
| v0.7.2 | webfs 下載跟隨轉址 | 裝置跑 v0.7.2 後更新 | ✅ v0.7.3 更新時證實：下載真的開始，耗時約 30 秒 |
| v0.7.4 | 邊抹邊寫，取代整片抹除 | 裝置跑 v0.7.4 後更新 | ⏳ 本版驗證 |

每一層問題只有在前一層修好之後才看得見：轉址沒修好時下載根本沒開始，自然碰不到抹除的問題。
若本版的 webfs 更新仍失敗，v0.7.4 的更新結果保存機制會生效，設定頁重開後會顯示
「上次更新結果：⋯」，直接指出卡在哪一步。

## 驗證

- `pio run -e esp32dev`
- `pio run -e esp32dev --target buildfs`
- `pio test -e native`

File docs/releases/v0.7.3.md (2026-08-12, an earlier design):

# HydraCup v0.7.3

## 更新結果保留到重開機之後

每次 OTA 都以重新開機收尾，因此更新結果只在畫面上存在約 2.5 秒——而那正是使用者不會盯著看
的時刻。v0.7.1 的 webfs 失敗就是這樣被錯過的：訊息一閃即逝，重開後頁面重新載入，什麼都不剩，
只能靠推理還原發生了什麼。

現在最後一次更新的結果會寫進 NVS，開機後由 `GET /api/ota/status` 以 `last_outcome` 回傳，
設定頁「08 韌體更新」會顯示「上次更新結果：⋯」。不論成功或失敗、不論當下有沒有人在看，
重開後都查得到。

## 這一版也是轉址修正的第一次真正驗證

v0.7.2 修好了 webfs 下載不跟隨轉址的問題，但那次更新是由**尚未修正的 v0.7.1 韌體**執行的，
所以修正沒有機會生效——OTA 的修正永遠只能由下一次更新來驗證，因為執行下載的是舊韌體。

本版由已含修正的 v0.7.2 執行下載，因此是第一次真的走到修正後的路徑。若 webfs 這次成功，
設定頁會出現「10 清除飲水紀錄」卡片（它從未透過 OTA 送達過），且狀態會顯示「網頁資源已更新」。

## 驗證

- `pio run -e esp32dev`
- `pio run -e esp32dev --target buildfs`
- `pio test -e native`

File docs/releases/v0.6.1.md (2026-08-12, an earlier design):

# HydraCup v0.6.1

## 修正：歷史頁熱力圖需要數分鐘才載入

v0.6.0 把 `DashboardServer` 的 `max_open_sockets` 明確設為 5（低於 ESP-IDF 預設的 7），
理由是要替 OTA 下載保留 socket。這個取捨是錯的，因為同一版已經把 `CONFIG_LWIP_MAX_SOCKETS`
從 10 提高到 16，而且 OTA 期間其他網路 worker 本來就會降載。

**症狀**：瀏覽器對同一主機固定維持最多 6 條 keep-alive 連線，一旦超過 httpd 能接受的數量，
多出來的連線就停在 TCP backlog，直到既有連線被回收才輪得到。年度熱力圖會一次展開 13 個月份
的請求，因此表現為「持續卡在載入中」，實測需要超過 5 分鐘才會完成。

單獨用 `curl` 測不出來——每個 `curl` 跑完就結束、連線立即釋放，永遠累積不到上限。實際重現
方式是持有數條閒置 TCP 連線（完全不送請求），此時任何新連線都無法建立。

**修正**：
- `max_open_sockets` 提高到 8，容得下瀏覽器的 6 條連線再加餘裕
- 啟用 `lru_purge_enable`，連線額滿時關閉最久未使用的閒置連線，而不是拒絕新連線。
  如此即使有客戶端持有超出預算的連線，退化的是延遲而不是可達性

## 前端請求逾時

`data/ui.js` 的 `hydraFetch` 先前使用裸 `fetch()`，沒有任何逾時。裝置若在載入途中離線
（OTA 重新開機、reset 後 STA 連線逾時退回 AP mode），請求永遠不會 settle，呼叫端也就走不到
自己的錯誤處理——熱力圖的 `Promise.allSettled` 會無限停在「載入中…」，即使程式碼裡早已備好
「熱力圖暫時無法載入，請稍後再試。」的分支。

現在改用 `AbortController`，預設 15 秒逾時，可由呼叫端以 `timeoutMs` 覆寫。

> **此項不隨 OTA 生效。** `data/` 位於 webfs 分割區，OTA 只寫 app 分割區，需另以
> `pio run -e esp32dev --target uploadfs` 更新。韌體端的 socket 修正則可直接由 OTA 送達。

## 升級

可直接由設定頁「08 韌體更新」以 OTA 更新。

## 驗證

- `pio run -e esp32dev`
- `pio test -e native`
- 重現測試：持有 4 條閒置 TCP 連線後，新連線在 v0.6.0 上完全無法建立

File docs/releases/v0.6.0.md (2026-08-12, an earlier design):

# HydraCup v0.6.0

## 主要更新：OTA 韌體更新

- 設定頁新增「08 韌體更新」卡片，可直接從 GitHub Releases 檢查版本並更新韌體，完成後自動重新開機。
- 新增 `lib/OtaUpdater/`：專屬 `ota_worker` task（10 KB static stack、優先權 3、pin core 0），以 `esp_https_ota` 寫入備用 app slot。下載期間 Web UI 仍可正常查詢進度。
- 新增 `GET /api/ota/status`、`POST /api/ota/check`、`POST /api/ota/update` 三個端點，沿用既有的登入 session 與 CSRF 保護。
- 版本檢查讀取 release 的 `version.txt` 固定資產，而非 `api.github.com`：後者未認證時限 60 req/hr/IP，家用 NAT 下多台裝置會撞牆，且需要 8 KB 靜態 buffer 解析 JSON。SemVer 比對為**嚴格大於**，遠端版本較舊時不會觸發更新。
- 下載開始後會讀取映像的 app descriptor，版本必須同時等於檢查時公告的版本、且嚴格大於目前執行版本，否則中止。manifest 與韌體資產是對可變 `latest` 指標的兩次請求，TLS 只證明完整性不證明身分。
- 新增專案根目錄 `version.txt` 作為 ESP-IDF `PROJECT_VER` 來源（此前是 `git describe`，產出 `v0.4.0-8-g55db70d-dirty` 這類無法比對的字串）。release workflow 直接發佈同一個檔案當 manifest，manifest 與映像描述子因此由建置保證一致；CI 檢查它與 `include/version.h`、git tag 三方相同。
- 啟用 bootloader rollback（`CONFIG_BOOTLOADER_APP_ROLLBACK_ENABLE`）。新韌體須在控制任務持續心跳滿 30 秒後才確認為 valid，否則下次開機自動回滾到前一個 slot。
- 確認條件**只看 uptime 與控制任務心跳，不含 WiFi**。未設定 WiFi 的裝置走 AP Mode，若把連線納入條件會導致每次開機都被回滾。

## 韌體體積最佳化

原本 `firmware.bin` 已佔 1.25 MB app slot 的 90.0%（1,179,312 B），沒有空間容納 OTA。本版改用
size 最佳化並移除未使用的 C++ 執行期機制：

| 變更 | 節省 |
|---|---|
| `CONFIG_COMPILER_OPTIMIZATION_SIZE`（`-Og` → `-Os`） | 98,672 B |
| `CONFIG_COMPILER_CXX_EXCEPTIONS=n` / `CXX_RTTI=n`（全專案零 `try`/`catch`、零 `dynamic_cast`/`typeid`；`virtual` 不受影響） | 47,664 B |

加入 OTA 後 `firmware.bin` 為 1,067,910 B（**81.5%**），較改版前多出約 240 KB 餘裕。
分割區表未變動，`logfs` 飲水紀錄不受影響。

新增 `[env:esp32dev-debug]`，以 `-Og` 建置同一份韌體供 GDB 使用；發佈與 OTA 映像一律來自
`esp32dev`。CI 與 release workflow 都會擋下超過 app slot 92% 的韌體。

## 併發降載

`esp_ota_write()` 期間兩顆 core 的 flash cache 會被反覆停用，因此更新時：

- **暫停飲水事件判定**——HX711 是時序敏感的 bit-bang，此時讀值會失真，寧可漏記也不要把假事件寫進 logfs 與雲端。秤重取樣本身不停，Web 的即時重量顯示照常。
- **暫停 Cloud sync 與 Discord**——各自的 mbedtls session 約 40 KB heap，與韌體寫入直接競爭。事件留在佇列中，更新結束或失敗後自動排出。
- **暫停 MQTT 心跳**——節省 socket 預算。
- 更新前檢查內部可用 heap，低於 60 KB 直接回 `503 insufficient_memory`；寫入途中 OOM 會留下半寫入的 slot，事前拒絕更安全。

`CONFIG_LWIP_MAX_SOCKETS` 由 10 提高到 16，並將 httpd 的 `max_open_sockets` 顯式設為 5——
GitHub 會 302 轉址到 `objects.githubusercontent.com`，下載期間需要 2–3 條連線，原本的預算不夠。

## 憑證信任

OTA 改用 ESP-IDF 內建 CA bundle 的 CMN 子集（41 張、約 18 KB），**不釘選根憑證**。GitHub 的
release 轉址跨兩個網域且憑證鏈自行輪換，釘選一旦失效就等於同時失去發佈修正的能力。
`CloudSyncClient` 與 `DiscordNotifier` 維持既有的釘選 PEM。

## 升級與相容性

**本版必須以 USB 燒錄一次，之後才能使用 OTA。** rollback 是 bootloader 的行為，只有重燒
bootloader 才會生效：

```powershell
pio run -e esp32dev --target upload     # bootloader + partitions + otadata + firmware
pio run -e esp32dev --target uploadfs   # webfs（設定頁的韌體更新卡片）
```

`uploadfs` 只更新 `webfs`，不會清除 `logfs` 飲水月檔，也不需清除 NVS。

**OTA 不會更新 `webfs`。** 日後設定頁改版仍需 `uploadfs`。為此 `/api/ota/status` 的 JSON 欄位
只增不改，且所有面向使用者的文字都由韌體回傳、前端只做渲染，讓舊版 UI 也能顯示新韌體的
狀態與錯誤。

完整操作見 [Build & Flash](../guides/build-flash.md)。

## 驗證

- `pio run -e esp32dev`
- `pio run -e esp32dev-debug`
- `pio test -e native`
- `pio run -e esp32dev --target buildfs`

尚未在實機驗證的項目見本版 PR 說明：`-Os` 對 HX711 bit-bang 時序的長時間影響、完整
OTA 端到端流程，以及刻意推送壞韌體的 rollback 驗證。

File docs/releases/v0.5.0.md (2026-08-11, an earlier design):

# HydraCup v0.5.0

## 主要更新：杯況感知提醒與 LINE／LIFF 整合

- 提醒只在水杯穩定放置後開始或繼續倒數；杯子拿走時保留剩餘時間。
- 有效喝水事件會重新開始完整提醒週期；補水與不符合飲水量門檻的重量變化不會重設提醒。
- Local Device Console 與 LIFF 採用一致的飲水進度、水滴、漣漪、滿杯與溢水視覺語言，並支援亮暗主題與 `prefers-reduced-motion`。
- 點擊、觸碰或以鍵盤啟用進度水杯只播放晃水與摘要互動，不會新增或修改飲水紀錄。

## Cloud sync、配對與歷史補傳

- 新增 `CloudSyncClient`，以 LittleFS durable outbox 保存已確認的飲水／補水事件；server ACK 前會持續重送，並以 NVS emergency overflow 處理短暫 outbox append 失敗。
- 裝置使用 NVS 產生的 256-bit raw token，Local WebUI 只顯示 Device ID 與 token SHA-256；raw token 不進瀏覽器、Cloudflare secrets、文件或 Git。
- 第一次成功同步且尚未綁定時，Device Console 顯示 8 碼、10 分鐘有效的 LIFF 配對碼；配對完成後由後續同步清除。
- 設定頁可啟動可恢復的歷史補傳，逐月將今天以前的 Local 每日摘要送到 service；server 逐日取事件 aggregate 與裝置快照的最大值，重跑不會重複累加。
- 歷史補傳游標綁定 service origin、Device ID 與 token identity；身分變更後會從頭安全重送。

## Local 與 LIFF 使用體驗

- Local History 與 LIFF 趨勢熱力圖預設顯示最近 365 天，並可切換指定完整年份；平年顯示 365 格、閏年顯示 366 格。
- Local History 直接讀取 LittleFS 月檔；LIFF 讀取已同步事件及歷史補傳快照。啟用 Cloud sync 後需保持 `UTC+8`，讓即時事件、Local 月檔與 service 的 Asia/Taipei 日期邊界一致。
- ESP32 仍是飲水事件、重量與提醒狀態的唯一真實來源；Web／LIFF 不提供手動新增飲水量。

## 升級與相容性

1. 先部署支援 protocol v1 與 `device_history_days` migration 的 `hydracup-service`。
2. 建置並燒錄 firmware，再以 `uploadfs` 更新 Local WebUI；不要執行整片 erase。
3. 登入 Device Console，確認 Cloud sync 的 Service URL、`UTC+8`、Device ID 與 token SHA-256 allowlist。
4. 等待 HTTP `200` 並完成 LIFF 配對；需要既有 Local 歷史時，再由設定頁手動啟動補傳。

`uploadfs` 只更新 `webfs`，不會清除 `logfs` 飲水月檔；一般 firmware／webfs 升級也不需清除
NVS。完整操作見 [Build & Flash](../guides/build-flash.md)、[Configuration](../guides/configuration.md)
與 [HydraCup Service 使用指南](https://github.com/Ning0612/hydracup-service/blob/main/docs/user-guide.md)。

## 驗證

- `pio run -e esp32dev`
- `pio test -e native`
- `pio run -e esp32dev --target buildfs`
- `git diff --check`
- 實機交付另確認：放杯後才倒數、拿杯暫停、有效喝水重計時、Cloud sync HTTP `200`、LIFF 配對、歷史補傳，以及 Local／LIFF 的 365 天與指定年份切換。

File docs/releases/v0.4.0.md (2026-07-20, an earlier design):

# HydraCup v0.4.0

## 主要更新：原生 FreeRTOS／ESP-IDF 遷移

- 韌體由 Arduino runtime 遷移至 PlatformIO `framework = espidf`，以 ESP-IDF 5.4 與 FreeRTOS 執行。
- `src/main.cpp` 只保留啟動與 loop orchestration；WiFi、HTTP、MQTT、Discord、NVS、LittleFS、HX711、蜂鳴器與 OLED 邏輯分拆至可重用模組。
- 控制流程集中於 FreeRTOS control task，MQTT、Discord、事件記錄與每日摘要使用背景 worker，避免網路或儲存 I/O 阻塞感測與飲水偵測。
- 保留既有 NVS 設定格式與資料分割區相容性；升級時不需要清除 NVS 或 `logfs`。

## 硬體與驅動

- OLED 已改用 ESP-IDF `i2c_master` bus/device API，移除 legacy I2C driver warning，保留 400 kHz 與內部 pull-up 設定。
- OLED 單位顯示統一為小寫 `g` 與 `ml`，避免字型與顯示截斷問題。
- 新增 `release-assets/`，提供 HydraCup 上下件的 STEP 與 STL CAD 檔案。

## WebUI、AP 與登入

- AP 設定頁恢復 WiFi 掃描、輸入欄位與操作按鈕，並與 WebUI 採用一致的視覺風格。
- 首次設定 AP SSID 為 `WaterCupTracker-Setup`，AP 密碼為 `12345678`。
- admin 沒有預設密碼；連上區域網路後前往 `/login`，首次設定至少 8 個字元的 admin 密碼。
- 修正登入 session cookie 保留與登入後跳轉，並保留 session、CSRF、逾時與登入失敗 rate limiting。

## 網路通知與穩定性修正

- Discord Webhook 改以 HTTP POST 發送，並回報 HTTP failure，避免訊息未送出時沒有明確診斷。
- 修正 WiFi scan 結果被重複消費造成 AP 掃描失效的問題。
- 保留既有 MQTT、Discord、NTP、事件記錄與 WebUI 設定資料，並完成 reconnect、heap、task stack 與 NVS 相容性驗證。

## 驗證

- `pio run -e esp32dev` — ESP-IDF firmware build 成功；RAM 使用 12.2%，Flash 使用 87.3%。
- `pio test -e native` — 16/16 測試通過。
- 已在 COM5 實機載入既有 NVS，成功連線 WiFi、MQTT 與 Discord；OLED 不再出現 legacy I2C warning。
- 已完成 24 小時穩定性測試，觀察 heap、task stack、WiFi reconnect 與既有 NVS 設定相容性。

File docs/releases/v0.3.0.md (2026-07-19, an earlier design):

# HydraCup v0.3.0

## 主要更新：WebUI 風格重設計

- Dashboard、History、Settings 與登入頁統一為 HydraCup 的深色／淺色主題、導覽列、卡片、狀態橫幅與指標元件。
- History 新增月份總覽、深度分析、時段分布、週別飲水量、年度熱力圖、每日統計與最近記錄。
- Dashboard 與 History 圖表、熱力圖及卡片版面支援不同螢幕寬度；主題切換標籤統一為 `LIGHT`／`DARK`。
- Settings 重新整理提醒、蜂鳴器、感測器、Wi-Fi／Discord、NTP、MQTT 與秤重校正流程。
- README 新增 WebUI 截圖畫廊、實機照片，並更新飲水偵測 Demo 的 MP4 與 GIF。

## 安全與通知

- Normal Mode 與 ConfigPortal 加入登入 session、CSRF token、idle／absolute timeout 與登入失敗 rate limiting。
- Discord Webhook 使用憑證鏈驗證，並調整傳送失敗處理，避免在無法確認結果時重送造成重複通知。

## 修正

- 修正 annual heatmap 在窄螢幕上的響應式版面。
- 避免 Discord 每日摘要在重複觸發時重複發送。

## 驗證

- `pio test -e native` — 16/16 測試通過。
- `pio run -e esp32dev` — firmware build 成功。
- 已更新 README 版本徽章、韌體 `APP_VERSION` 與 release tag 至 `v0.3.0`。

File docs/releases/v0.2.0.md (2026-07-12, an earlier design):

# HydraCup v0.2.0

## FreeRTOS runtime

- 新增 Core 1 `hydracup_control` task，集中管理 HX711、飲水偵測、提醒、蜂鳴器、OLED 與時間服務。
- 新增 `RuntimeCoordinator`，以一致 snapshot 與固定大小 command/result Queue 隔離 Dashboard 與控制 domain。
- tare 改為非阻塞取樣與 warm-up 流程；控制 task 期間不會被 HTTP handler 的 tare 操作卡住。
- Discord 改為持久 worker；MQTT 保留背景 worker；飲水 log 與 counter persistence 改為背景寫入。
- 新增 NVS `StorageLock`，並加入 counter version barrier、restore retry、跨日 settlement marker ack。
- `/api/status` 增加 RTOS heartbeat、健康狀態與 Queue drop telemetry。

## Validation

- `pio test -e native`：16/16 通過。
- `pio run -e esp32dev`：成功。
- firmware 與 `webfs` 已寫入 ESP32-D0WDQ6（COM5，MAC `cc:50:e3:8c:d9:d0`）。
- 實機曾成功輸出 RTOS heartbeat：`stack_free=6012`、`heap=191084`、`cmd_drop=0`、`result_drop=0`。

## Known limitations

- 硬體 cold boot 在 WiFi 連線階段曾觸發 brownout reset；需使用穩定 5V 供電後再進行完整 WiFi、Dashboard、MQTT、Discord 與 24 小時 soak 驗證。
- 尚未執行硬體上的 tare/calibrate、慢速 log client、WiFi reconnect 與長時間壓力測試。

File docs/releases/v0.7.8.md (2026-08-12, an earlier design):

# HydraCup v0.7.8

## 只有版本號，沒有功能變更

本版存在的唯一目的，是讓 v0.7.7 的 IRAM 緩衝區修正有機會以「執行端」的身分運作一次。

OTA 下載由裝置上**原本**的韌體執行，不是被下載的那一份。因此修正必須等裝置先跑到含有它的
版本，再更新到下一版才會生效。裝置更新到 v0.7.7 之後，本版就是它的第一次執行——也是
webfs OTA 自 v0.7.0 引入以來，第一次有機會真正把網頁資源寫進分割區。

只升版本號是為了只留一個變因：成功即可歸因於 `MALLOC_CAP_8BIT`，失敗則由 v0.7.6 加入的
步驟 log 與 v0.7.3 的更新結果保存指出下一層問題。

## 這一串問題的完整軌跡

| 版本 | 修正 | 是否為 webfs 從未成功的原因 |
|---|---|---|
| v0.7.2 | 下載跟隨轉址 | 不是主因，但**必要**——沒有它下載不會開始，後面的問題都碰不到 |
| v0.7.4 | 邊抹邊寫取代整片抹除 | 不是主因，但**有價值**——讓崩潰不再留下被抹空的分割區 |
| v0.7.6 | OTA task stack 10→16 KB | **不是**。當時推測為 stack 溢位，實際不是；16 KB 保留為餘裕 |
| v0.7.7 | 緩衝區改用 `MALLOC_CAP_8BIT` | **是**。`MALLOC_CAP_INTERNAL` 也可能配到 IRAM，而 IRAM 只允許 32-bit 對齊存取，memcpy 第一批資料時即 panic |

真正的原因由 serial 擷取到的暫存器 dump 直接指出：`LoadStoreError`、出錯位址在 IRAM、
長度 4096 正是 `OTA_WEBFS_CHUNK`、PC 在 ROM memcpy。

## 驗證

- `pio run -e esp32dev`
- `pio test -e native`

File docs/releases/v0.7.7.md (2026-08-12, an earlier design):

# HydraCup v0.7.7

## 修正：webfs 下載緩衝區配置在 IRAM，一寫入就 panic

自 v0.7.0 引入 webfs OTA 以來，它從未成功過一次。serial 擷取到崩潰現場後，暫存器 dump
直接給出答案：

```
Guru Meditation Error: Core 0 panic'ed (LoadStoreError)
EXCCAUSE: 0x00000003        LoadStoreError
EXCVADDR: 0x40096bc0        出錯位址
A2      : 0x40096668        目的緩衝區
A12     : 0x00001000        4096 = OTA_WEBFS_CHUNK
PC      : 0x4000c325        ROM memcpy
```

`0x40096668` 位於 **IRAM**（ESP32 的 `0x40080000`–`0x400A0000`），而 IRAM 只允許 32-bit
對齊存取。`memcpy` 會做 byte 存取，因此第一批資料抵達、要複製進緩衝區時就 panic。

原因是配置緩衝區時只寫了 `MALLOC_CAP_INTERNAL`：

```cpp
heap_caps_malloc(OTA_WEBFS_CHUNK, MALLOC_CAP_INTERNAL)   // 錯
```

`MALLOC_CAP_INTERNAL` 只保證「不是 PSRAM、cache 關閉時仍可用」，**不保證可逐位元組存取**——
IRAM 完全符合前者卻不符合後者。要拿到 byte 可存取的記憶體必須加上 `MALLOC_CAP_8BIT`。

同樣的概念錯誤也出現在兩處 `heap_caps_get_free_size(MALLOC_CAP_INTERNAL)`：它們把不能當
byte 緩衝區用的 IRAM 也算進可用量，使更新前的記憶體檢查高估。一併修正。

## 這解釋了先前所有的失敗現象

- 崩潰發生在 `esp_https_ota_finish()` 之後，開機分割區已切換，所以韌體照常更新到新版本
- `saveLastOutcome()` 在正常路徑的最後才執行，panic 讓它沒機會執行——`last_outcome` 因此為空
- 崩潰在任何抹除或寫入之前，所以 webfs 有時完好（v0.7.4 邊抹邊寫之後）
- 從外部看就是「韌體燒完就重開」

`reset reason=4`（`ESP_RST_PANIC`）也在 v0.7.6 的開機記錄中確認了這一點。

## 先前兩個修正的定位

| 版本 | 修正 | 是否為本次崩潰的原因 |
|---|---|---|
| v0.7.2 | 下載跟隨轉址 | 否，但**必要**——沒有它下載根本不會開始，也就碰不到這個 panic |
| v0.7.4 | 邊抹邊寫 | 否，但**有價值**——它讓崩潰不再留下被抹空的分割區 |
| v0.7.6 | stack 10→16 KB | 否。當時的推論是 stack 溢位，實際不是；16 KB 保留作為餘裕，並非修正 |

## 驗證

- `pio run -e esp32dev`
- `pio test -e native`

依慣例，本修正需由 v0.7.7 執行下一次更新才會生效。

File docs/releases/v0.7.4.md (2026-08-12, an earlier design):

# HydraCup v0.7.4

## 修正：webfs 寫入前的整片抹除會拖垮下載連線

v0.7.3 的更新中，webfs 的轉址問題已修好、下載也確實開始了，但重開機後 webfs 掛載失敗
（`Corrupted dir pair`），裝置只剩「Web assets unavailable」。

把分割區 dump 出來比對，答案很直接：**384 KB 全部是 `0xFF`——抹除成功了，但一個位元組都
沒有寫進去**。耗時約 30 秒，正是讀取逾時（15 秒）的量級。

**原因**：流程是「開啟 HTTP 連線 → 抹除整個 384 KB 分割區 → 開始讀取」。整片抹除是數秒等級
的操作，而且每次抹除都會停用兩顆 core 的 flash cache；lwIP 執行於 flash，這段期間 TCP/TLS
連線等同無人服務。等抹除結束回頭要讀，連線已經失效，`esp_http_client_read()` 一路逾時到放棄。

**修正**：改為**邊抹邊寫**——每寫入一個 4 KB 區塊前才抹除該區塊，讓連線持續有資料流動。
單次 4 KB 抹除是毫秒等級，不會中斷連線。這也正是 `esp_ota_write()` 內部採用的做法。
下載完成後才把映像之後的殘餘區域一次抹掉，此時已無連線需要維持。

## 為什麼前幾版沒發現

這一系列問題有個共同結構：**OTA 的修正只能由下一次更新來驗證**，因為執行下載的永遠是舊韌體。

- v0.7.2 修好轉址，但那次更新由未修正的 v0.7.1 執行，修正沒有機會跑
- v0.7.3 由已修正的 v0.7.2 執行，轉址修正確實生效、下載真的開始了——才因此暴露出下一層的
  抹除問題

本版同理，需要由 v0.7.3 執行更新才能驗證。

## 驗證

- `pio run -e esp32dev`
- `pio test -e native`
- 損毀分割區的 dump 已與預期映像逐位元組比對，確認為「已抹除、未寫入」

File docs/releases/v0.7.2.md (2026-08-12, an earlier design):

# HydraCup v0.7.2

## 修正：webfs OTA 因未處理轉址而必定失敗

v0.7.0 加入的網頁資源 OTA 從來沒有成功過。實機更新到 v0.7.1 時，韌體正常寫入，但狀態顯示
「網頁資源更新失敗」。

**原因**：`esp_http_client` 只在 `esp_http_client_perform()` 的狀態機裡處理 301/302
（`esp_http_check_response()`）。webfs 因為要邊下載邊寫入分割區，走的是低階的
`esp_http_client_open()` / `fetch_headers()` / `read()` 串流流程，**這條路徑不會跟隨轉址**，
GitHub 的 302 會原封不動回傳。程式看到狀態碼 302 不在 2xx 範圍就直接放棄。

韌體那一半沒有受影響，是因為 `esp_https_ota` 內部走的是會處理轉址的路徑。

**這個失敗是安全的**：放棄發生在卸載與抹除分割區**之前**，webfs 一個位元組都沒被動到，
裝置全程可用。

**修正**：`_updateWebfs()` 自行跟隨轉址（最多 `OTA_MAX_REDIRECTS` 次），每次以
`esp_http_client_set_redirection()` 取得新位址後重新開啟連線。

## 失敗訊息不再被通用文字蓋掉

先前 webfs 失敗時，最終狀態一律顯示「網頁資源更新失敗，需以 USB 重新燒錄」，把
`_updateWebfs()` 記錄的具體原因蓋掉了——既看不出是哪一步失敗，也在分割區根本沒被觸碰時
錯誤地要求使用者重新燒錄。現在會保留具體原因，例如「網頁資源下載失敗（HTTP 302）」。

## 升級

可直接由設定頁「08 韌體更新」以 OTA 更新。本版是第一個網頁資源真的會隨 OTA 更新的版本。

## 驗證

- `pio run -e esp32dev`
- `pio test -e native`

轉址修正尚未在實機驗證——這正是本版要驗證的事。

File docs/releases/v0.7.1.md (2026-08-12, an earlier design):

# HydraCup v0.7.1

## 新增：從設定頁清除飲水紀錄

設定頁新增「10 清除飲水紀錄」，需再次輸入管理密碼確認。清除範圍：

- `logfs` 全部（飲水月檔 `/logfs/logs/drink-*.jsonl` 與尚未上傳的同步佇列）
- NVS `drink_ctr` 的今日累計與飲水次數——今日計數存在 NVS 而非 logfs，只清檔案會讓儀表板
  顯示一個沒有任何紀錄支撐的總量
- NVS `cloud_sync` 的 `evt_overflow` 溢位暫存，留著會把剛刪掉的事件放回佇列

**不會**刪除已同步到雲端的資料，也不動 `cloud_sync` 的 sequence 與 cursor（重置可能造成雲端
重複累加或拒收），校正值、WiFi 與其他設定同樣不受影響。

## 清除在下次開機時執行

端點本身不清除任何東西：它把要求記進 NVS、回應、然後重新開機，實際的清除發生在下次開機、
掛載檔案系統之前、任何 task 建立之前。

這個間接性是設計本身，不是實作細節。在系統運行中清除，等於要和每一個正在寫入這些資料的來源
賽跑：EventLogger 佇列裡的事件（包含已出佇列、正阻塞在檔案系統鎖上的那一筆）、計數器儲存的
佇列與重試路徑、開機時仍在讀取舊值的 NVS restore，以及 Cloud sync 在鎖內讀出、鎖外送出的批次。
每一項都需要各自的屏障，而檔案清除與計數清除之間仍然無法對「剛好在此時發生的一次飲水」保持
原子性。

先前的實作走的正是執行期清除，兩輪審查找出八個這樣的窗口，而且問題數是增加而非收斂——每補上
一個屏障就暴露出下一個。該版本已整個捨棄。

開機時這些都還不存在，清除因此是一條沒有併發的直線。`/logfs/logs` 與 `/logfs/cloud` 由
`EventLogger` 與 `CloudSyncClient` 在同一次開機的初始化中重建，不需要額外處理。

## 失敗與中斷的處理

執行順序為 **NVS 計數先、logfs 格式化後**，讓不可逆的一步排在最後：

- 計數抹除失敗 → 直接中止，一個位元組都還沒被刪，要求保留至下次開機
- 格式化失敗 → 計數已歸零但月檔仍在，同樣保留要求重試
- 要求旗標**最後才清除**，因此中途斷電只會再跑一次，不會回報一個沒做到的成功

歷史補傳進行中時，清除要求會被拒絕（`409`）——它會在回應與重開機之間繼續上傳並推進 cursor，
而那些歷史即將消失。

已知取捨：若旗標本身無法清除（NVS 持續性故障），每次開機都會重新格式化一次 logfs。那是更深層
的硬體問題，格式化是冪等的且 log 會明確指出，因此不另設重試上限。

## 安全

需要登入 session 與 CSRF token，**並在 body 再次提供管理密碼**——session 本身不足以授權一個
無法復原的操作。密碼以既有的 PBKDF2-HMAC-SHA256 雜湊比對，長度上限 128；驗證失敗計入與登入
端點共用的 IP 鎖定，避免這個端點成為繞過登入防護的暴力破解入口。

## 驗證

- `pio run -e esp32dev`
- `pio run -e esp32dev --target buildfs`
- `pio test -e native`

尚未在實機驗證清除流程。

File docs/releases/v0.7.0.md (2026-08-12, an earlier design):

# HydraCup v0.7.0

## 主要更新：OTA 一併更新網頁資源

v0.6.0 的 OTA 只寫 app 分割區，`data/` 底下的網頁資源位於 webfs，必須另接 USB 執行
`uploadfs`。本版把 webfs 併入同一個「立即更新」動作，設定頁按一次就會處理完韌體與網頁。

流程：
1. 先取得 release 的 `SHA256SUMS`。取不到就完全不動 webfs——沒有備援分割區，無法驗證的
   映像不該寫進去。
2. 寫韌體。失敗則整個更新中止，webfs 一個位元組都不會被碰。順序不可對調：先寫 webfs 再寫
   韌體，失敗時會留下「網頁比韌體新」的組合，而相容性契約只保證反向。
3. 比對 `SHA256SUMS` 裡 `hydracup-esp32dev-littlefs.bin` 的雜湊與 NVS 記錄的已安裝值。
   相同就跳過，不做無謂的抹除。
4. 需要更新時卸載 `/webfs`，抹除分割區，邊下載邊以 4 KB 為單位寫入並累算 SHA-256，
   寫完比對雜湊，相符才把新雜湊寫回 NVS。
5. 重新開機。

## 已知風險：webfs 沒有備援分割區

app 有 `app0`/`app1` 可以先寫再切換、失敗自動回滾；webfs 只有一塊，寫入是就地覆蓋，
而 384 KB 的映像也放不進 RAM 先驗證。因此**寫入途中失敗會使網頁資源損毀，需接 USB 執行
`uploadfs` 復原**。這是本功能明確接受的取捨。

失敗範圍僅限靜態頁面：API 由韌體提供，`/api/*` 在 webfs 損毀時仍可正常運作，裝置也照常
記錄飲水。狀態訊息會明確指出需要 USB 重新燒錄。

韌體寫入成功之後，無論 webfs 結果如何都會重新開機——新韌體優於舊韌體，即使網頁沒跟上。

## 與 HTTP server 的競態處理

httpd 在自己的 task 上服務靜態頁面，因此在卸載並抹除分割區的瞬間，可能正有請求處於
`fread()` 之中。靜態檔案的讀取現在受一把讀取鎖保護：OTA 先取得該鎖（等待進行中的傳送結束），
在仍持有鎖的狀態下把 webfs 標記為不可用，才釋放並卸載。通過檢查的請求因此不可能在卸載之後
才碰到檔案系統。若 10 秒內取不到鎖，本次就跳過 webfs——韌體已經寫入完成，不值得為此冒險。

`/api/*` 不受此鎖影響，更新期間狀態查詢照常回應。失敗路徑會嘗試重新掛載：校驗不符的情況下
分割區上其實是一份完整映像，通常仍可掛載成功。

## 其他

- `GET /api/ota/status` 新增 `stage` 欄位（`firmware` / `webfs`），指出目前正在更新哪一段。
- 設定頁的進度文字改為直接採用韌體回傳的 `message` 再附加百分比。所有面向使用者的文字都由
  韌體產生，因此比韌體舊的頁面仍能描述它沒學過的狀態。
- 首次由 USB `uploadfs` 安裝後，NVS 沒有已安裝雜湊的記錄，第一次 OTA 會重寫一次 webfs 即使
  內容相同。之後才會正確跳過。不改用「直接雜湊分割區內容」判斷，是因為 LittleFS 執行期間會
  改寫 metadata，實際位元組會與發佈的映像產生落差。

## 升級

可直接由設定頁「08 韌體更新」以 OTA 更新，本版起網頁資源會一併處理。

## 驗證

- `pio run -e esp32dev`
- `pio test -e native`

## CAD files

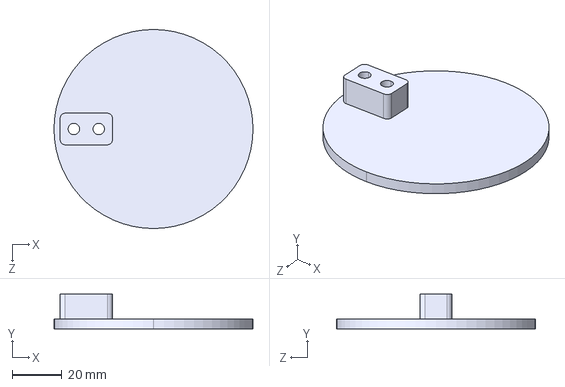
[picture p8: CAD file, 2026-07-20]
release-assets/hydracup-top.step
80.0 x 14.0 x 80.0 mm

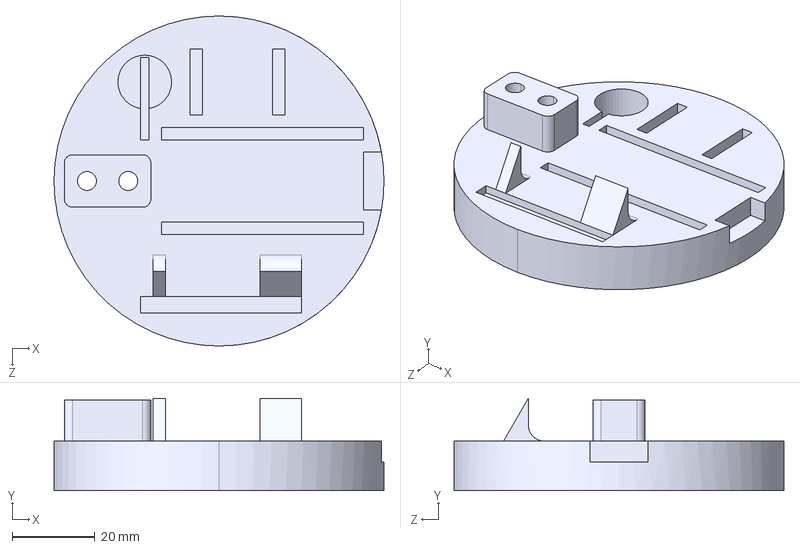
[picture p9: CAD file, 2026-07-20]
release-assets/hydracup-bottom.step
80.0 x 22.4 x 80.0 mm

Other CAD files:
release-assets/hydracup-bottom.stl
release-assets/hydracup-top.stl

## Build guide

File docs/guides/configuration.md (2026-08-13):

# Configuration

所有設定均可透過登入後的 `http://<ip>/settings` 頁面或帶有效 session／CSRF token 的
`POST /api/config` 修改，並持久化至 NVS。首次進入 Normal Mode 時，`/login` 會要求設定
至少 8 個字元的管理密碼；密碼只以 PBKDF2-HMAC-SHA256 雜湊儲存。

Normal Mode 使用伺服器端單一 session slot：新登入會取代舊 session，閒置 30 分鐘或登入後
24 小時自動失效；裝置重開機也會讓 session 失效。管理介面目前以 HTTP 提供，因此請將它
限制在信任的隔離 LAN，避免同網段攻擊者攔截並重放 token。

設定頁第一層只顯示日常會調整的「飲水與提醒」及「蜂鳴器」。感測器、WiFi、NTP、Cloud
sync 與 MQTT 收在「網路、感測器與整合」進階區；秤重校正仍是獨立區塊，避免誤把校正操作
當成一般設定。

---

## 飲水偵測

| 設定 | API 欄位 | 預設值 | 有效範圍 | 說明 |
|---|---|---|---|---|
| 杯子偵測閾值 | `cupPresentThresholdGram` | 80.0 g | 10–500 g | 低於此重量視為無杯子 |
| 穩定誤差 | `stableToleranceGram` | 3.0 g | 0.5–20 g | 重量允許波動範圍 |
| 穩定持續時間 | `stableDurationMs` | 3000 ms | 500–10000 ms | 判定穩定需持續的時間 |
| 最小飲水量 | `minDrinkDeltaMl` | 20.0 ml | 5–100 ml | 低於此量不記錄為飲水 |
| 最大飲水量 | `maxDrinkDeltaMl` | 500.0 ml | 50–1000 ml | 超過此量不記錄（防誤判） |

**調整建議**：
- 若常出現「沒喝卻觸發」→ 調高 `stableToleranceGram` 或調高 `minDrinkDeltaMl`
- 若喝水後未觸發 → 調低 `minDrinkDeltaMl`
- 若穩定等待太久 → 調低 `stableDurationMs`（建議不低於 1500 ms）

### 為什麼預設是這些值？

HX711 讀值先經過 10 筆 moving average；系統每 100 ms 取樣一次，因此窗口約涵蓋
1 秒。這能降低單次讀值抖動，又不會讓拿起或放回杯子的反應延遲太久。

`stableToleranceGram` 預設 3 g，用來容許秤台與 load cell 的微幅噪聲；
`stableDurationMs` 預設 3000 ms，要求重量在容許範圍內持續 3 秒，避免短暫碰撞或
放杯回彈被誤判為穩定。實際安裝若振動較大，可提高容許誤差或延長時間；若需要更
快的反應，可反向調整，但必須以實機流程確認誤判率。

---

## 每日目標與提醒

| 設定 | API 欄位 | 預設值 | 有效範圍 | 說明 |
|---|---|---|---|---|
| 每日飲水目標 | `dailyGoalMl` | 2000 ml | 100–9999 ml | 顯示於儀表板進度條 |
| 啟用提醒 | `reminderEnabled` | true | — | 開啟/關閉提醒蜂鳴器 |
| 提醒間隔 | `reminderIntervalMin` | 60 min | 1–1440 min | 多久沒喝水就提醒 |
| 提醒持續時間 | `reminderAlertTimeoutSec` | 60 sec | 5–3600 sec | 提醒蜂鳴最長持續時間 |

---

## 蜂鳴器

| 設定 | API 欄位 | 預設值 | 有效範圍 | 說明 |
|---|---|---|---|---|
| 啟用蜂鳴器 | `buzzerEnabled` | true | — | 開啟/關閉所有蜂鳴 |
| 頻率 | `buzzerFrequencyHz` | 2000 Hz | 500–5000 Hz | 蜂鳴音調（無源蜂鳴器） |
| 時長 | `buzzerDurationMs` | 150 ms | 50–2000 ms | 單次蜂鳴時長 |
| 音量 | `buzzerVolumePercent` | 50% | 0–100% | LEDC PWM 占空比控制音量 |

---

## NTP 時間同步

| 設定 | API 欄位 | 預設值 | 說明 |
|---|---|---|---|
| 啟用 NTP | `ntpEnabled` | true | 關閉後時間戳將無效 |
| NTP 伺服器 1 | `ntpServer1` | `"pool.ntp.org"` | 主要 NTP 伺服器 |
| NTP 伺服器 2 | `ntpServer2` | `"time.google.com"` | 備用 NTP 伺服器 |
| 時區標籤 | `timezone` | `"Asia/Taipei"` | 顯示與儲存用的說明文字 |

**時區設定**：`timezone` 欄位僅作為說明性標籤儲存於 NVS，**不會自動影響時區偏移**。
實際的 UTC 偏移由 `timezoneOffsetSec`（預設 +28800，即 UTC+8）與
`daylightOffsetSec`（預設 0）決定，`TimeManager` 會透過 ESP-IDF `esp_sntp_*` API
同步時間，並以 `TZ` 環境設定產生本地時間。若 NTP 未同步，飲水記錄的時間戳會以
`"boot+<ms>ms"` 格式儲存，日誌存在 `drink-unsynced.jsonl`。

---

## WiFi

| 設定 | API 欄位 | 說明 |
|---|---|---|
| SSID | `wifiSsid` | 家庭 WiFi 名稱 |
| 密碼 | `wifiPassword` | WiFi 密碼（API 回應中以 `****` 顯示） |

> WiFi 設定異動後裝置會自動重啟。

---

## Discord Webhook

| 設定 | API 欄位 | 說明 |
|---|---|---|
| Webhook URL | `discordWebhookUrl` | 完整 Discord Webhook URL（API 回應中末尾以 `****` 遮罩） |

Discord 通知類型：
- **上線通知**：裝置連上 WiFi 後發送，含 IP 位址
- **飲水通知**：每次 `DRINK_CONFIRMED` 後發送，含飲水量與今日進度
- **每日摘要**：午夜 00:00 發送，含當日總量與達成率

設定步驟見 [discord-setup.md](discord-setup.md)。

---

## Cloud sync

Cloud sync 將 ESP32 已確認的飲水／補水事件透過 HTTPS durable outbox 同步至獨立的
HydraCup Service。ESP32 仍是飲水事件與提醒狀態的唯一真實來源，雲端 WebUI 不提供
手動新增飲水量。目前 service protocol v1 的驗證組合需要 HydraCup firmware `v0.5.0`
以上；若任一端修改 schema、history backfill 或 command／ACK 語意，必須同步升級兩個 repo。

| 設定 | API 欄位 | 說明 |
|---|---|---|
| 啟用 HTTPS 同步 | `cloudEnabled` | 開啟裝置背景同步；變更後需重新啟動 |
| Service URL | `cloudBaseUrl` | 只填 HTTPS origin，例如 `https://hydracup-service.pages.dev` |
| Device ID | `cloudDeviceId` | 首次啟動由裝置依 MAC 產生；WebUI 唯讀顯示 |
| Device token SHA-256 | `cloudDeviceTokenHash` | 供 Cloudflare allowlist 使用；不是 raw token，WebUI 唯讀顯示 |

Service v1 的日期邊界固定為 Asia/Taipei，因此啟用 Cloud sync 時裝置時區必須是 `UTC+8`；
其他時區會被設定 API 拒絕，既有非 UTC+8 設定也不會開始同步。這可確保即時事件、Local
月檔與 LIFF 熱力圖使用同一天界。

WebUI 與 `POST /api/config` 都會移除 Service URL 前後空白與結尾斜線，並只接受純 HTTPS
origin。不可附加 `/api/v1/device/sync`、其他 path、query、fragment 或帳密；不合法值會在
套用其他設定前回傳 `400`。背景 worker 每 15 秒同步一次；新事件或 command ACK 會要求
提早同步。登入後的裝置首頁「03 裝置狀態」會顯示：

- `正常 · 待送 0`／HTTP `200`：最近一次同步成功，durable outbox 已送完。
- `待送 N`：尚有事件等待 server ACK；短暫離線時屬正常現象。
- HTTP `401`：Device ID 或 token hash 與部署環境 allowlist 不一致。
- HTTP `--`：尚未送出，或 HTTPS 在取得 HTTP status 前失敗；先檢查 URL 空白、DNS、網路與 TLS 時間。
- `儲存失敗 N 筆`：LittleFS outbox 與 NVS emergency overflow 都無法保存事件，需立即排查儲存空間。

裝置未綁定時，第一次成功同步會在同區顯示 8 碼、10 分鐘有效的「WebUI 配對碼」。
配對完成後 server 回傳 `deviceBound=true`，裝置會清除顯示中的配對碼。完整 LINE／LIFF
使用流程見
[HydraCup Service 使用指南](https://github.com/Ning0612/hydracup-service/blob/main/docs/user-guide.md)（`hydracup-service` 為私有 repo，需有存取權限）。

Raw device token 只存在 ESP32 NVS，不會顯示在 WebUI，也不應放入 Cloudflare、repo、文件
或訊息。Device Console 目前使用 LAN HTTP，請只在信任的隔離網路操作。

### 補傳 Local 歷史到 LIFF

Cloud sync 已正常連線後，在設定頁「06 Cloud sync」按「開始補傳」。背景 worker 每批處理
一個月份，把 LittleFS 中今天以前的每日摘要送往 `/api/v1/device/history-backfill`；原始
token 不會交給瀏覽器。service 確認後才持久化 `hist_cursor`，所以離線、5xx 或重開機後會
重送相同月份，不會跳過資料，也不會重複累加。完成後可再次執行，補上前次執行時仍屬今日
的資料。游標會綁定 Service origin 與裝置身分；身分變更後從頭安全重送。月檔以短批次
持有 filesystem lock、在鎖外解析，避免阻塞新的飲水日誌。

狀態為 `retrying` 時裝置每 15 秒自動重試。HTTP 400 通常表示 firmware 與 service 協定
版本不一致；401 是裝置身分不符；410 是雲端帳號刪除後的停用 tombstone。

---

## AP 模式設定

| 設定 | API 欄位 | 預設值 | 說明 |
|---|---|---|---|
| AP SSID | `apSsid` | `WaterCupTracker-Setup` | AP Mode 廣播的 WiFi 名稱 |
| AP 密碼 | `apPassword` | `12345678` | AP 連線密碼 |

---

## curl 批次設定範例

以下假設已登入，`cookies.txt` 內有 `session` cookie，並已取得 session CSRF token。

```bash
curl -b cookies.txt -H "X-CSRF-Token: <session-csrf-token>" \
  -X POST -H "Content-Type: application/json" \
  -d '{
    "dailyGoalMl": 2500,
    "reminderEnabled": true,
    "reminderIntervalMin": 45,
    "buzzerVolumePercent": 70,
    "ntpServer1": "pool.ntp.org",
    "timezone": "Asia/Taipei"
  }' \
  http://192.168.1.100/api/config
```

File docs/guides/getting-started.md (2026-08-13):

# Getting Started

首次使用 HydraCup 的完整設定流程。

---

## 前置需求

| 工具 | 安裝方式 |
|---|---|
| [PlatformIO CLI](https://platformio.org/install/cli) | `pip install platformio` |
| Python 3.x | [python.org](https://www.python.org) |
| USB-UART 驅動 | CP2102：[Silicon Labs](https://www.silabs.com/developer-tools/usb-to-uart-bridge-vcp-drivers)；CH340：[WCH](http://www.wch.cn/downloads/CH341SER_EXE.html) |
| Git | [git-scm.com](https://git-scm.com) |

---

## 步驟 1：取得程式碼

```powershell
git clone https://github.com/<your-user>/esp32-hydracup.git
cd esp32-hydracup
```

---

## 步驟 2：接線

依照 [hardware.md](../hardware.md) 將 HX711、OLED、蜂鳴器接至 ESP32 對應 GPIO。  
通電前確認：

- HX711 VCC → 3V3（不要接 5V，防止 OLED 損毀）
- 稱重感測器已正確固定在杯托底座
- USB-UART 線接妥

---

## 步驟 3：首次燒錄

```powershell
# 建置 ESP-IDF 韌體
pio run -e esp32dev

# 燒錄韌體、bootloader 與分割表
pio run -e esp32dev --target upload

# 燒錄 Web UI 靜態資源至 webfs
pio run -e esp32dev --target uploadfs
```

驗證 `uploadfs` 目標位址正確：

```bash
pio run -e esp32dev -v -t uploadfs | Select-String address
# 預期輸出：address 0x290000, size 0x60000
```

---

## 步驟 4：設定 WiFi

1. ESP32 上電後，若沒有可用 WiFi 設定或 STA 連線逾時，蜂鳴器播放 `AP_MODE` 音效
2. 在手機或電腦的 WiFi 列表中找到 `WaterCupTracker-Setup`
3. 輸入 AP 密碼 `12345678` 連線；這是設定 AP 的 WiFi 密碼，不是 admin 密碼
4. 開啟瀏覽器前往 `http://192.168.4.1`
5. 在設定頁掃描或輸入目標 WiFi 的 SSID 與密碼，點擊「儲存並重新啟動」
6. 裝置自動重啟並嘗試連線 WiFi
7. 由 OLED 或路由器查到裝置在區域網路的 IP，開啟 `http://<裝置 IP>/login`
8. 初次使用沒有預設 admin 密碼；在 `/login` 輸入一組至少 8 個字元的管理密碼並確認，完成後即可登入 WebUI

---

## 步驟 5：秤重歸零（Tare）

1. 開啟瀏覽器，前往 `http://<裝置 IP>`（IP 顯示於 OLED 頁 0）
2. 點選「Settings」→「Calibration」
3. **移除杯子**，確認秤台淨空
4. 點擊「Tare」，等待確認訊息
5. 放上一個已知重量（例如 200g 砝碼），點擊「Calibrate」並輸入精確重量

詳細校正流程見 [calibration.md](calibration.md)。

---

## 步驟 6：連接 LINE／LIFF 雲端服務（選用）

這個步驟需要 HydraCup firmware `v0.5.0` 以上、已部署的獨立 `hydracup-service`、已設定的裝置 allowlist，以及可用的
LINE Login／Messaging API channel。完整的使用與配對流程見
[HydraCup Service 使用指南](https://github.com/Ning0612/hydracup-service/blob/main/docs/user-guide.md)（`hydracup-service` 為私有 repo，需有存取權限）。

1. 登入 `http://<裝置 IP>/settings`
2. 在「Cloud sync」勾選「啟用 HTTPS 同步」
3. Service URL 只填 Pages origin，例如 `https://hydracup-service.pages.dev`；不要附加
   `/api/v1/device/sync`，也不要在前後留下空白
4. 確認裝置時區為 `UTC+8`，並核對唯讀的 Device ID 與 Device token SHA-256 已和 Cloudflare production allowlist 一致
5. 儲存設定並依提示重新啟動裝置
6. 回到裝置首頁「03 裝置狀態」，等待 Cloud sync 顯示 `正常 · 待送 0`，HTTP 顯示 `200`
7. 同一區的「WebUI 配對碼」會顯示 8 碼、10 分鐘有效的配對碼；完成 LINE 配對後該碼會消失
8. 若 Local 歷史早於啟用 Cloud sync，回到設定頁「06 Cloud sync」按「開始補傳」，等待
   顯示完成後重新開啟 LIFF「趨勢」

配對碼只顯示於登入後的本機 Device Console，不會顯示在 OLED。請勿分享管理密碼、
raw device token 或 Device token SHA-256。

---

## 步驟 7：確認運作

1. OLED 頁 0 顯示 IP 位址與 WiFi 狀態
2. 開啟 `http://<ip>`，儀表板顯示目前重量與今日進度
3. 放上裝水的杯子，等待 3 秒後「Cup State」顯示 `stable`
4. 拿起杯子喝水後放回，數秒後應看到「Drink Confirmed」並更新今日飲水量
5. 歷史頁面（`/history`）查看月份記錄與年度熱力圖

首頁「今日進度」會依完成比例改變水面、氣泡與滿杯效果；超過 100% 時以溢水呈現，
但 150% 以上不再增加動畫強度。有效飲水事件會短暫顯示落水、漣漪與本次增加的 ml；
點擊或用鍵盤啟用水杯只會播放晃水動畫並顯示進度摘要，不會新增或修改飲水紀錄。
作業系統啟用「減少動態效果」時，頁面會保留靜態狀態而停用主要動畫。

Local History 與 LIFF「趨勢」的年度熱力圖都預設顯示最近 365 天，並可用左右箭頭切換
指定完整年份；平年為 365 格、閏年為 366 格。Local 直接讀取裝置 LittleFS 月檔，LIFF
只顯示已同步的雲端事件與完成歷史補傳的每日摘要，因此兩邊在補傳完成前可能暫時不同。

---

## 常見問題

| 問題 | 排查方式 |
|---|---|
| OLED 無顯示 | 確認 GPIO 21/22 接線與 I2C 位址（0x3C） |
| 重量一直跳動 | 調高 `stableToleranceGram` 或固定稱重平台 |
| 飲水未觸發 | 確認拿起杯子後放回的動作；調低 `minDrinkDeltaMl` |
| Discord 通知失敗 | 確認 Webhook URL 正確；確認 WiFi 可存取外網 |
| 找不到裝置 IP | 查看路由器 DHCP 清單，或觀察 OLED 頁 0 顯示 |
| NTP 未同步 | 確認 NTP 伺服器可達；先讓裝置連上有 DNS 的網路 |
| Cloud sync 顯示 `HTTP --` | 確認 Service URL 前後沒有空白且只填 HTTPS origin；儲存後重新啟動，等待至少 15 秒 |
| Cloud sync 顯示 HTTP 401 | 核對 Cloudflare production 的 `DEVICE_ID` 與 `DEVICE_TOKEN_HASH` 是否和 Device Console 完全一致 |
| 配對碼一直顯示等待產生 | 先確認 Cloud sync HTTP 200；配對碼只會在裝置尚未綁定且成功同步後出現 |
| 歷史補傳停在暫時失敗 | 會每 15 秒自動重試；先確認 Cloud sync HTTP 200，400 時需確認 service 已部署相容版本與 D1 migration |

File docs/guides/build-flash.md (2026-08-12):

# Build & Flash

## 開發環境

HydraCup 使用 PlatformIO 的兩個 environment：

- `esp32dev`：ESP32 + native ESP-IDF/FreeRTOS firmware，`framework = espidf`
- `native`：主機端 C++17 + Unity 測試，執行不依賴硬體的 `DrinkDetectorCore` 與 `ReminderCore` 測試

目前 PlatformIO environment 設定為 `espressif32@~6.10.0`，由 PlatformIO 管理對應的
ESP-IDF toolchain。若 Windows 的 `pio` 不在 PATH，可使用目前機器的完整路徑：
`C:\Users\Ning\.platformio\penv\Scripts\pio.exe`；其他電腦請替換使用者名稱。

## CI

GitHub Actions 會在 push、pull request 與手動 workflow dispatch 時執行
`.github/workflows/ci.yml`：

- 建置 `pio run -e esp32dev`
- 執行 `pio test -e native`

CI 不會燒錄裝置、上傳 Web 資源、連接 HX711/OLED，也不會執行硬體或 Discord/MQTT
整合測試。

## 常用指令

以下指令在 repository 根目錄執行。PowerShell 請逐行執行，不要把多個命令串在同一行。

```powershell
# 建置 ESP-IDF firmware
pio run -e esp32dev

# 執行 native host-side tests
pio test -e native

# 清除 ESP32 建置快取
pio run -e esp32dev --target clean

# 燒錄 firmware、bootloader 與 partition table
pio run -e esp32dev --target upload --upload-port COM5

# 燒錄 data/ 到 webfs 分割區
pio run -e esp32dev --target uploadfs --upload-port COM5

# 開啟 Serial monitor
pio device monitor -e esp32dev --port COM5 --baud 115200
```

`native` environment 明確設定 `test_build_src = no`，只建置測試引用的純 C++ core；不要把
`src/main.cpp` 或 FreeRTOS／ESP-IDF 硬體模組加入 native test build。

`upload` 與 `uploadfs` 是兩個不同步驟：firmware 不會自動包含 `data/` 靜態資源。
若 `pio` 不在 PATH，可將上述命令中的 `pio` 替換為 PlatformIO 虛擬環境內的執行檔。

## 燒錄速率

`platformio.ini` 設定 `upload_speed = 921600`，monitor baud 為 `115200`。若燒錄不穩定，
可暫時將 `upload_speed` 降為 `460800` 或 `115200`。

## uploadfs 位址驗證

`board_build.filesystem = littlefs` 會將 `data/` 寫入第一個符合 PlatformIO filesystem
目標的資料分割區，即 `webfs`（`0x290000`、`0x60000` bytes）。PowerShell 可用：

```powershell
pio run -e esp32dev -v --target uploadfs | Select-String address
```

預期位址為 `0x290000`。若位址不符，先確認 `partitions.csv` 與 `platformio.ini` 沒有被
修改。

## 分割區與資料保護

| 分割區 | 偏移 | 大小 | 用途 |
|---|---|---|---|
| `nvs` | `0x9000` | 20 KB | WiFi、AppConfig、管理密碼雜湊 |
| `app0` / `app1` | `0x10000` / `0x150000` | 各 1.25 MB | OTA firmware slot |
| `webfs` | `0x290000` | 384 KB | `/webfs` 靜態 Web 資源 |
| `logfs` | `0x2F0000` | 1 MB | `/logfs/logs/` JSONL 飲水日誌 |

- `uploadfs` 只寫入 `webfs`，不會影響 `logfs` 歷史日誌。
- firmware 以 `esp_vfs_littlefs_register()` 掛載 `/webfs` 與 `/logfs`。
- `logfs` 使用 `format_if_mount_failed = false`；mount 失敗時不會自動格式化或清除資料。
- 完整 erase 或變更分割區位置可能使 NVS、Web 資源與日誌失效；執行前應先備份需要保留的資料。

## OTA 韌體更新

v0.6.0 起，Normal Mode 可從 GitHub Releases 直接更新韌體（設定頁「08 韌體更新」，
API 見 `docs/api.md`）。

**首次啟用需要一次 USB 燒錄**，之後才能改用 OTA：

```powershell
pio run -e esp32dev --target upload     # bootloader + partitions + otadata + firmware
pio run -e esp32dev --target uploadfs   # webfs（設定頁的韌體更新卡片）
```

`upload` 這一步不可省略成「只寫 app 分割區」：rollback（`CONFIG_BOOTLOADER_APP_ROLLBACK_ENABLE`）
是 **bootloader** 的行為，只有重燒 bootloader 才會生效。若沒重燒就跑新韌體，開機會把
`ota_state` 設成 PENDING_VERIFY 而舊 bootloader 不認得——不會變磚，但回滾功能會靜默失效。

**v0.7.0 起 OTA 會一併更新 `webfs`**（先韌體後網頁，僅在 `SHA256SUMS` 的雜湊與 NVS 記錄的
已安裝值不同時才重寫）。但 webfs 只有一塊分割區、沒有 A/B 備援，寫入是就地覆蓋——中途失敗
會使靜態頁面損毀，需以 `uploadfs` 復原（此時 `/api/*` 仍正常，因為 API 由韌體提供）。

因此 `/api/ota/status` 的欄位仍維持只增不改，所有面向使用者的文字也仍由韌體回傳：裝置可能
處於「UI 比韌體舊」的狀態（webfs 寫入被跳過或失敗、或以 USB 燒入舊映像）。

`sdkconfig.defaults` 中與 OTA 直接相關的設定：

| 設定 | 值 | 原因 |
|---|---|---|
| `CONFIG_LWIP_MAX_SOCKETS` | 16 | GitHub 會 302 轉址到 `objects.githubusercontent.com`，下載期間需要 2–3 條連線；預設 10 不夠 |
| `CONFIG_MBEDTLS_CERTIFICATE_BUNDLE` + `_DEFAULT_CMN` | y | OTA 不能釘選根憑證（見 `docs/architecture.md`）。CMN 子集約 18 KB，全量約 67 KB |
| `CONFIG_BOOTLOADER_APP_ROLLBACK_ENABLE` | y | 新韌體若在 30 秒內崩潰，bootloader 自動回滾到前一個 slot |

> **改 `sdkconfig.defaults` 後必須刪掉 `sdkconfig.esp32dev` 再建置**，否則新值會被既有檔
> 蓋過而靜默失效。詳見 `CLAUDE.md` 的 Known Environment Constraints。

版本有兩個必須同步的來源：專案根目錄的 `version.txt`（ESP-IDF 的 `PROJECT_VER`，會寫進 app
descriptor 供 OTA 下載後驗證，優先於 `git describe`）與 `include/version.h` 的 `APP_VERSION`
（韌體回報與比對用）。release workflow 會檢查兩者與 git tag 三方一致，並直接把 `version.txt`
當成 manifest 資產發佈。

`[env:esp32dev-debug]` 是同一份韌體以 `-Og` 建置的除錯環境（`scripts/sdkconfig_debug_defaults.py`
會把 `sdkconfig.debug.defaults` 疊在 `sdkconfig.defaults` 之上）。它**不可用於發佈或 OTA**。

## ESP-IDF 相依元件

專案不再使用 Arduino `lib_deps`。韌體相依元件由 `src/CMakeLists.txt` 與
`src/idf_component.yml` 管理，包含：

- ESP-IDF：`driver`、`esp_event`、`esp_netif`、`esp_wifi`、`esp_http_server`、
  `esp_http_client`、`esp_https_ota`、`esp-tls`、`app_update`、`mqtt`、`nvs_flash`、
  `json`、`mbedtls`、FreeRTOS 等
- registry component：`joltwallet/littlefs`（`>=1.14.6,<2.0.0`）

不要再安裝或新增 `bogde/HX711`、`ArduinoJson`、`Adafruit SSD1306`、`Adafruit GFX`
等 Arduino library；目前硬體驅動與 JSON 處理使用 ESP-IDF API。

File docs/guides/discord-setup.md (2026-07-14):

# Discord Webhook Setup

設定後，HydraCup 將自動發送三種通知至指定的 Discord 頻道：上線通知、飲水通知、每日摘要。

HydraCup 對 Discord Webhook 使用憑證鏈驗證，不會在 TLS 失敗時降級為未驗證連線。內嵌的
trust anchor 目前是 Google Trust Services `GTS Root R4`（經 `WE1` 簽發的
`discord.com` 鏈）；Discord 或憑證鏈更新時，需同步更新 `lib/DiscordNotifier/DiscordNotifier.cpp`
中的 CA，並在裝置上重新燒錄韌體。

裝置會等 NTP 時間同步成功後才送出 Discord 通知；若關閉 NTP 或同步失敗，通知會略過，
避免在 RTC 時間不可信時誤判 TLS 憑證有效期。

---

## 步驟 1：建立 Discord Webhook

1. 在 Discord 中開啟目標**伺服器**與**頻道**（例如 `#water-tracker`）
2. 點擊頻道右鍵 → **「編輯頻道」**
3. 左側選單選擇 **「整合」**
4. 點擊 **「Webhooks」** → **「建立 Webhook」**
5. 設定 Webhook 名稱（例如 `HydraCup`）
6. 點擊 **「複製 Webhook 網址」**
7. URL 格式如下：

```
https://discord.com/api/webhooks/1234567890/abcdefghijklmnopqrstuvwxyz0123456789
```

---

## 步驟 2：輸入 Webhook URL

### 透過 Web UI

1. 前往 `http://<裝置 IP>/settings`
2. 找到「Discord」區塊
3. 貼上複製的 Webhook URL
4. 點擊「Save」

### 透過 API

API 需要已登入的 session cookie 與 `X-CSRF-Token`；首次使用請先透過 Web UI
設定管理密碼並登入，再從瀏覽器開發者工具複製請求，或依序呼叫
`GET /api/auth/csrf`、`POST /api/auth/login` 取得 token 與 cookie。

```bash
curl -b cookies.txt -X POST \
  -H "Content-Type: application/json" \
  -H "Cookie: session=<session-token>" \
  -H "X-CSRF-Token: <session-csrf-token>" \
  -d '{"discordWebhookUrl": "https://discord.com/api/webhooks/..."}' \
  http://192.168.1.100/api/config
```

---

## 步驟 3：確認運作

1. 儲存設定後，`/api/status` 的 `webhook_configured` 欄位應為 `true`
2. 重啟裝置（`POST /api/reboot`），約 10 秒後 Discord 頻道應收到上線通知
3. 進行一次飲水動作，確認收到飲水通知

---

## URL 安全遮罩

`/api/config`（GET）回應中，Webhook URL 末尾 token 以 `****` 遮罩：

```
https://discord.com/api/webhooks/1234567890/****
```

`POST /api/config` 時，若 URL 含 `****` 則**跳過更新**，防止意外清除 token。

---

## 通知格式

### 上線通知

```
✅ HydraCup 已上線
WebUI: http://192.168.1.100
```

### 飲水通知

```
💧 本次 +230 ml（今日 920/2000 ml）
```

### 每日摘要（午夜 00:00）

每日摘要使用 Discord L2 embed，包含日期、進度條、達成率、今日攝取、今日目標、
完成度、飲水次數、平均每次與剩餘／超標量等欄位。

---

## 常見問題

| 問題 | 解決方法 |
|---|---|
| `webhook_last_ok` 為 false | 確認 URL 正確、裝置可存取外網（ping discord.com） |
| 通知延遲 | Discord API 偶發限速，屬正常現象，裝置會自動重試 |
| Webhook URL 已遺失 | 回到 Discord 頻道「整合 → Webhooks」重新複製，或建立新 Webhook |
| 想關閉通知 | 將 `discordWebhookUrl` 清空並儲存，或刪除 Discord 端的 Webhook |

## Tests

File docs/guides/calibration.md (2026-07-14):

# Scale Calibration

HX711 需要兩個步驟才能正確轉換 ADC 原始值為公克：**歸零（Tare）** 與 **校正（Calibrate）**。

---

## 原理

HX711 輸出的是原始 24-bit ADC 值，需要兩個參數轉換：

```
weightGrams = (rawADC - tareOffset) / calibrationFactor
```

| 參數 | 說明 | 儲存位置 |
|---|---|---|
| `tareOffset` | 空秤台的 ADC 基準值 | NVS key `tare_offset` |
| `calibrationFactor` | ADC 值 / 公克 的比值 | NVS key `cal_factor` |

---

## 步驟 1：歸零（Tare）

1. **移除秤台上的所有物品**（確保淨空）
2. 前往 `http://<ip>/settings`，找到「Calibration」區塊
3. 點擊「**Tare**」按鈕
4. 確認頁面顯示「Tare OK」且重量顯示接近 0

```bash
# 或使用 curl（需先登入並取得 session cookie／CSRF token）
curl -b cookies.txt -H "X-CSRF-Token: <session-csrf-token>" \
  -X POST http://192.168.1.100/api/tare
```

---

## 步驟 2：校正（Calibrate）

1. 準備一個**已知精確重量**的物品（建議 100–500 g；砝碼最佳）
2. 將物品放上秤台
3. 在「Calibration」區塊輸入已知重量（例如 `200`）
4. 點擊「**Calibrate**」
5. 確認顯示的重量與已知重量一致（誤差 ±2 g 以內）

```bash
# 或使用 curl（需先登入並取得 session cookie／CSRF token）
curl -b cookies.txt -H "X-CSRF-Token: <session-csrf-token>" \
  -X POST -H "Content-Type: application/json" \
  -d '{"known_weight_g": 200.0}' \
  http://192.168.1.100/api/calibrate
# 回應：{"ok":true,"calibration_factor":427.53}
```

---

## 步驟 3：驗證

移除校正物，放上水杯（加水）後觀察：

1. 重量讀數穩定（跳動 ≤ 3 g）
2. 拿起杯子再放下，`Cup State` 應依序顯示 `no_cup → unstable → stable`
3. 喝水後放回，`DRINK_CONFIRMED` 顯示，今日飲水量增加

若重量持續跳動，可嘗試：

- 將 `stableToleranceGram` 調高（預設 3.0 g，可試 5.0 g）
- 確認秤台固定平穩、無晃動
- 將 HX711 改為 80 Hz 輸出速率（RATE 腳位接高電位）

---

## 重新校正

若感測器更換或讀數長期偏移，重複步驟 1–3 即可。校正係數會立即存入 NVS，重啟後仍有效。

---

## 注意事項

- 歸零與校正時，**感測器必須已完全靜置**（放置 10 秒以上再操作）
- 環境溫度變化可能影響 HX711 讀值，建議在實際使用環境下校正
- `calibrationFactor` 預設值 `1.0`（未校正），此時重量讀值無意義

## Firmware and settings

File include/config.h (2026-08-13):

#pragma once

// Serial
#define SERIAL_BAUD_RATE 115200

// OLED
#define OLED_I2C_ADDRESS    0x3C
#define OLED_SCREEN_WIDTH   128
#define OLED_SCREEN_HEIGHT   32
#define OLED_RESET_PIN       -1
#define OLED_UPDATE_INTERVAL_MS 500

// Buzzer LEDC
#define BUZZER_LEDC_CHANNEL    0
#define BUZZER_LEDC_RESOLUTION 8
#define BUZZER_DEFAULT_FREQ_HZ    2000
#define BUZZER_DEFAULT_DURATION_MS 150
#define BUZZER_DEFAULT_VOLUME_PCT   50

// HX711
#define HX711_INIT_TIMEOUT_MS    3000
#define HX711_SAMPLE_COUNT         10
#define HX711_READ_INTERVAL_MS    100
#define SCALE_SERIAL_INTERVAL_MS 1000

// NVS
#define NVS_NAMESPACE "water_config"

// STA connect retries before falling back to the config portal. Worst case is
// WIFI_STA_ATTEMPTS x timeout plus the gaps, which only applies when the network really is
// gone - the common case is a reset where the second attempt succeeds within seconds.
#define WIFI_STA_ATTEMPTS       3
#define WIFI_STA_RETRY_GAP_MS   2000

// AP Mode defaults
#define AP_DEFAULT_SSID     "WaterCupTracker-Setup"
#define AP_DEFAULT_PASSWORD "12345678"

// Drink detection defaults
#define DEFAULT_CUP_THRESHOLD_G    80.0f
#define DEFAULT_STABLE_TOLERANCE_G  3.0f
#define DEFAULT_STABLE_DURATION_MS 3000
#define DEFAULT_MIN_DRINK_ML        20.0f
#define DEFAULT_MAX_DRINK_ML       500.0f

// Reminder defaults
#define DEFAULT_REMINDER_INTERVAL_MIN    60
#define DEFAULT_REMINDER_ALERT_TIMEOUT_SEC 60
#define DEFAULT_DAILY_GOAL_ML          2000

// NTP defaults
#define DEFAULT_NTP_SERVER1    "pool.ntp.org"
#define DEFAULT_NTP_SERVER2    "time.google.com"
#define DEFAULT_TIMEZONE       "Asia/Taipei"
#define DEFAULT_TZ_OFFSET_SEC  (8 * 3600)
#define DEFAULT_DST_OFFSET_SEC 0

// OTA firmware update
// Both assets are published by .github/workflows/release.yml under fixed names; the URLs
// are baked in, so renaming a release asset breaks updates on every deployed device.
// /releases/latest/download/ resolves only to non-draft, non-prerelease releases, which
// makes prereleases safe for internal testing.
#define OTA_MANIFEST_URL "https://github.com/Ning0612/esp32-hydracup/releases/latest/download/version.txt"
#define OTA_FIRMWARE_URL "https://github.com/Ning0612/esp32-hydracup/releases/latest/download/hydracup-esp32dev-firmware.bin"
// The web assets live in a data partition esp_https_ota cannot target, so they are streamed
// straight onto it. SHA256SUMS is published alongside them and is the only way to tell whether
// the image actually arrived intact - there is no second webfs partition to fall back to.
#define OTA_WEBFS_URL      "https://github.com/Ning0612/esp32-hydracup/releases/latest/download/hydracup-esp32dev-littlefs.bin"
#define OTA_CHECKSUMS_URL  "https://github.com/Ning0612/esp32-hydracup/releases/latest/download/SHA256SUMS"
#define OTA_WEBFS_ASSET    "hydracup-esp32dev-littlefs.bin"
#define OTA_WEBFS_LABEL    "webfs"
#define OTA_WEBFS_CHUNK    4096
// GitHub sends one redirect to its asset CDN; the allowance leaves room for another hop.
#define OTA_MAX_REDIRECTS  4
#define OTA_WEBFS_DEADLINE_MS    (3 * 60 * 1000)
#define OTA_OVERALL_DEADLINE_MS  (5 * 60 * 1000)
#define OTA_HTTP_TIMEOUT_MS      15000
#define OTA_HTTP_BUFFER_BYTES    4096
#define OTA_MIN_FREE_HEAP_BYTES  (60 * 1024)
// Uptime a freshly flashed image must reach, with the control task still beating, before
// the bootloader's rollback is cancelled. Never add connectivity to this condition.
#define OTA_MARK_VALID_DELAY_MS  30000
#define OTA_MARK_VALID_RETRY_MS  5000
// Wait for in-flight cloud sync / Discord requests to release their TLS heap after the shed
// flag goes up. The timeout exceeds their 10 s HTTP timeout so a request that is already
// blocked still gets to finish rather than making the update fail.
#define OTA_SETTLE_MIN_MS        1000
#define OTA_SETTLE_POLL_MS       250
#define OTA_SETTLE_TIMEOUT_MS    12000

// MQTT defaults
#define DEFAULT_MQTT_BROKER_PORT    1883
#define DEFAULT_MQTT_CLIENT_ID      "hydracup-device"
#define DEFAULT_MQTT_HEARTBEAT_SEC  60

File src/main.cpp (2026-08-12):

#include <algorithm>
#include <cstdio>
#include <cstring>
#include <string>

#include "AppState.h"
#include "BuzzerController.h"
#include "CloudSyncClient.h"
#include "ConfigManager.h"
#include "ConfigPortal.h"
#include "DashboardServer.h"
#include "DailySummaryManager.h"
#include "DiscordNotifier.h"
#include "DisplayManager.h"
#include "DrinkDetector.h"
#include "EventLogger.h"
#include "HistoryMaintenance.h"
#include "MqttPublisher.h"
#include "OtaUpdater.h"
#include "ReminderManager.h"
#include "RuntimeCoordinator.h"
#include "ScaleManager.h"
#include "TimeManager.h"
#include "WiFiManager.h"
#include "config.h"
#include "esp_littlefs.h"
#include "esp_system.h"
#include "esp_heap_caps.h"
#include "esp_log.h"
#include "freertos/FreeRTOS.h"
#include "freertos/task.h"
#include "hal_log.h"
#include "hal_time.h"
#include "nvs_flash.h"
#include "version.h"

namespace {
constexpr const char* TAG = "HydraCup";
AppState appState;
AppConfig appConfig;
ConfigManager configManager;
BuzzerController buzzerController;
CloudSyncClient cloudSyncClient;
DisplayManager displayManager;
ScaleManager scaleManager;
WiFiManager wifiManager;
ConfigPortal configPortal;
DashboardServer dashboardServer;
DrinkDetector drinkDetector;
ReminderManager reminderManager;
TimeManager timeManager;
DiscordNotifier discordNotifier;
EventLogger eventLogger;
DailySummaryManager dailySummaryManager;
MqttPublisher mqttPublisher;
OtaUpdater otaUpdater;
RuntimeCoordinator runtimeCoordinator;
TaskHandle_t controlTaskHandle = nullptr;
uint32_t controlHeartbeat = 0;
uint32_t dailyGoalMl = DEFAULT_DAILY_GOAL_ML;
uint32_t reminderIntervalMinSetting = DEFAULT_REMINDER_INTERVAL_MIN;
bool reminderEnabledSetting = true;
std::string reminderPausedUntilDate;
uint32_t pendingTareRequestId = 0;
bool onlineNotified = false;

bool validDateString(const char* value) {
    if (!value || std::strlen(value) != 10 || value[4] != '-' || value[7] != '-') return false;
    for (size_t i = 0; i < 10; ++i) {
        if (i != 4 && i != 7 && (value[i] < '0' || value[i] > '9')) return false;
    }
    const int month = (value[5] - '0') * 10 + value[6] - '0';
    const int day = (value[8] - '0') * 10 + value[9] - '0';
    const int year = (value[0] - '0') * 1000 + (value[1] - '0') * 100 +
                     (value[2] - '0') * 10 + value[3] - '0';
    if (month < 1 || month > 12 || day < 1) return false;
    static constexpr uint8_t daysPerMonth[] = {31, 28, 31, 30, 31, 30,
                                                31, 31, 30, 31, 30, 31};
    int maxDay = daysPerMonth[month - 1];
    if (month == 2 && (year % 400 == 0 || (year % 4 == 0 && year % 100 != 0))) ++maxDay;
    return day <= maxDay;
}

CloudAppliedSettings currentCloudSettings() {
    CloudAppliedSettings settings;
    settings.reminderEnabled = reminderEnabledSetting;
    settings.reminderIntervalMin = reminderIntervalMinSetting;
    settings.dailyGoalMl = dailyGoalMl;
    std::snprintf(settings.pausedUntilDate, sizeof(settings.pausedUntilDate), "%s",
                  reminderPausedUntilDate.c_str());
    return settings;
}

void mountFilesystems() {
    esp_vfs_littlefs_conf_t web = {};
    web.base_path = "/webfs"; web.partition_label = "webfs"; web.format_if_mount_failed = false; web.dont_mount = false;
    esp_err_t result = esp_vfs_littlefs_register(&web);
    if (result == ESP_OK) appState.fsOk = true;
    else LOG_WARN(TAG, "webfs mount failed: %s", esp_err_to_name(result));
    esp_vfs_littlefs_conf_t log = {};
    log.base_path = "/logfs"; log.partition_label = "logfs"; log.format_if_mount_failed = false; log.dont_mount = false;
    result = esp_vfs_littlefs_register(&log);
    if (result == ESP_OK) appState.logFsOk = true;
    else LOG_WARN(TAG, "logfs mount failed: %s", esp_err_to_name(result));
}

void replyControl(const ControlCommand& command, ControlResultStatus status) {
    ControlResult result; result.requestId = command.requestId; result.status = status; result.calibrationFactor = scaleManager.getCalibrationFactor(); result.tareOffset = scaleManager.getTareOffset(); result.weightGrams = scaleManager.getWeightGrams(); runtimeCoordinator.reply(result);
}

void processControlCommands() {
    ControlCommand command;
    for (uint8_t i = 0; i < 4 && runtimeCoordinator.receive(command); ++i) {
        switch (command.type) {
            case ControlCommandType::TARE:
                if (pendingTareRequestId || scaleManager.isTareRunning()) replyControl(command, ControlResultStatus::BUSY);
                else if (!scaleManager.isReady() || !scaleManager.isSamplesReady()) replyControl(command, ControlResultStatus::NOT_READY);
                else if (scaleManager.startTare()) { pendingTareRequestId = command.requestId; buzzerController.stop(); }
                else replyControl(command, ControlResultStatus::FAILED);
                break;
            case ControlCommandType::CALIBRATE:
                if (scaleManager.isTareRunning()) replyControl(command, ControlResultStatus::BUSY);
                else if (!scaleManager.isReady() || !scaleManager.isSamplesReady() || command.floatValue <= 0.0f || scaleManager.getRawAverage() == scaleManager.getTareOffset()) replyControl(command, ControlResultStatus::FAILED);
                else { scaleManager.calibrateWithKnownWeight(command.floatValue); replyControl(command, ControlResultStatus::OK); }
                break;
            case ControlCommandType::SET_DAILY_GOAL_ML: dailyGoalMl = command.uintValue; mqttPublisher.setDailyGoal(command.uintValue); replyControl(command, ControlResultStatus::OK); break;
            case ControlCommandType::SET_REMINDER_ENABLED: reminderEnabledSetting = command.boolValue; reminderManager.setEnabled(command.boolValue); replyControl(command, ControlResultStatus::OK); break;
            case ControlCommandType::SET_REMINDER_INTERVAL_MIN: reminderIntervalMinSetting = command.uintValue; reminderManager.setIntervalMin(command.uintValue); replyControl(command, ControlResultStatus::OK); break;
            case ControlCommandType::SET_REMINDER_ALERT_TIMEOUT_SEC: reminderManager.setAlertTimeoutSec(command.uintValue); replyControl(command, ControlResultStatus::OK); break;
            case ControlCommandType::SET_BUZZER_ENABLED: buzzerController.setEnabled(command.boolValue); replyControl(command, ControlResultStatus::OK); break;
            case ControlCommandType::SET_BUZZER_FREQUENCY_HZ: buzzerController.setFrequency(command.uintValue); replyControl(command, ControlResultStatus::OK); break;
            case ControlCommandType::SET_BUZZER_DURATION_MS: buzzerController.setDuration(command.uintValue); replyControl(command, ControlResultStatus::OK); break;
            case ControlCommandType::SET_BUZZER_VOLUME_PERCENT: buzzerController.setVolume(static_cast<uint8_t>(command.uintValue)); replyControl(command, ControlResultStatus::OK); break;
        }
    }
}

void processCloudCommands() {
    CloudCommand command;
    for (uint8_t i = 0; i < 4 && cloudSyncClient.receiveCommand(command); ++i) {
        bool ok = true;
        switch (command.type) {
            case CloudCommandType::SET_SETTINGS:
                if (command.reminderIntervalMin < 1 || command.reminderIntervalMin > 1440 ||
                    command.dailyGoalMl < 100 || command.dailyGoalMl > 9999) {
                    ok = false;
                } else {
                    reminderEnabledSetting = command.reminderEnabled;
                    reminderIntervalMinSetting = command.reminderIntervalMin;
                    reminderManager.setEnabled(command.reminderEnabled);
                    reminderManager.setIntervalMin(command.reminderIntervalMin);
                    dailyGoalMl = command.dailyGoalMl;
                    mqttPublisher.setDailyGoal(command.dailyGoalMl);
                }
                break;
            case CloudCommandType::SET_REMINDER_ENABLED:
                reminderEnabledSetting = command.boolValue;
                reminderManager.setEnabled(command.boolValue);
                break;
            case CloudCommandType::SET_REMINDER_INTERVAL_MIN:
                if (command.uintValue < 1 || command.uintValue > 1440) ok = false;
                else {
                    reminderIntervalMinSetting = command.uintValue;
                    reminderManager.setIntervalMin(command.uintValue);
                }
                break;
            case CloudCommandType::SET_DAILY_GOAL_ML:
                if (command.uintValue < 100 || command.uintValue > 9999) ok = false;
                else {
                    dailyGoalMl = command.uintValue;
                    mqttPublisher.setDailyGoal(command.uintValue);
                }
                break;
            case CloudCommandType::SNOOZE_MINUTES:
                if (command.uintValue != 20 && command.uintValue != 40 &&
                    command.uintValue != 60) ok = false;
                else reminderManager.snooze(command.uintValue);
                break;
            case CloudCommandType::PAUSE_TODAY:
                if (!validDateString(command.stringValue) ||
                    (timeManager.isSynced() && timeManager.getDateString() != command.stringValue)) {
                    ok = false;
                } else {
                    reminderPausedUntilDate = command.stringValue;
                    reminderManager.setPausedToday(true);
                }
                break;
            default:
                ok = false;
                break;
        }
        cloudSyncClient.acknowledgeCommand(command, ok, currentCloudSettings());
    }
}

void runControlIteration() {
    processControlCommands(); processCloudCommands(); buzzerController.update(); scaleManager.update(); timeManager.update();
    long tareOffset = 0;
    if (scaleManager.takeTareResult(tareOffset) && pendingTareRequestId) { drinkDetector.resetScaleBaseline(); ControlResult result; result.requestId = pendingTareRequestId; result.status = ControlResultStatus::OK; result.calibrationFactor = scaleManager.getCalibrationFactor(); result.tareOffset = tareOffset; result.weightGrams = scaleManager.getWeightGrams(); runtimeCoordinator.reply(result); pendingTareRequestId = 0; }
    else if (scaleManager.takeTareFailure() && pendingTareRequestId) { ControlResult result; result.requestId = pendingTareRequestId; result.status = ControlResultStatus::FAILED; result.calibrationFactor = scaleManager.getCalibrationFactor(); result.tareOffset = scaleManager.getTareOffset(); result.weightGrams = scaleManager.getWeightGrams(); runtimeCoordinator.reply(result); pendingTareRequestId = 0; }
    const bool persistenceReadyBefore = drinkDetector.isPersistenceInitialized(); if (persistenceReadyBefore) dailySummaryManager.update(); if (!scaleManager.isTareRunning() && !appState.otaInProgress.load()) drinkDetector.update(); if (!persistenceReadyBefore && drinkDetector.isPersistenceInitialized()) dailySummaryManager.update(); reminderManager.update();
    appState.weightGrams = scaleManager.getWeightGrams(); appState.nextReminderSec = reminderManager.getNextReminderSec(); appState.ntpSynced = timeManager.isSynced();
    static bool pauseRestored = false;
    if (!pauseRestored && appState.ntpSynced) {
        pauseRestored = true;
        const std::string today = timeManager.getDateString();
        if (!reminderPausedUntilDate.empty() && today <= reminderPausedUntilDate) {
            reminderManager.setPausedToday(true);
        } else if (!reminderPausedUntilDate.empty()) {
            reminderPausedUntilDate.clear();
            cloudSyncClient.persistSettings(currentCloudSettings());
        }
    }
    if (appState.ntpSynced && reminderManager.getState() == ReminderState::PAUSED_TODAY &&
        !reminderPausedUntilDate.empty() &&
        timeManager.getDateString() > reminderPausedUntilDate) {
        reminderPausedUntilDate.clear();
        reminderManager.setPausedToday(false);
        cloudSyncClient.persistSettings(currentCloudSettings());
    }
    CloudDeviceStatus cloudStatus;
    cloudStatus.todayTotalMl = appState.todayTotalMl; cloudStatus.lastDrinkMl = appState.lastDrinkMl;
    cloudStatus.drinkCount = appState.drinkCountToday; cloudStatus.reminderRemainingSec = appState.nextReminderSec;
    cloudStatus.alertEpisodeUptimeMs = reminderManager.getAlertEpisodeUptimeMs();
    cloudStatus.dailyGoalMl = dailyGoalMl; std::strncpy(cloudStatus.cupState, DrinkDetector::cupStateName(appState.cupState), sizeof(cloudStatus.cupState) - 1);
    std::strncpy(cloudStatus.reminderState, reminderManager.getStateName(), sizeof(cloudStatus.reminderState) - 1);
    std::strncpy(cloudStatus.lastDrinkAt, appState.lastDrinkAt, sizeof(cloudStatus.lastDrinkAt) - 1);
    cloudSyncClient.updateStatus(cloudStatus);
    if (appState.mode == AppMode::NORMAL && !onlineNotified && appState.ntpSynced) { const RuntimeSnapshot connectivity = runtimeCoordinator.snapshot(); discordNotifier.notifyOnline(connectivity.ipAddress); onlineNotified = true; }
    static CupState previousCup = CupState::NO_CUP; static uint32_t previousReminder = 1;
    if (appState.mode == AppMode::NORMAL) { const CupState current = drinkDetector.getCupState(); if (current != previousCup) { if (current == CupState::NO_CUP || previousCup == CupState::NO_CUP) displayManager.wake(); previousCup = current; } if (appState.nextReminderSec == 0 && previousReminder > 0) displayManager.wake(); previousReminder = appState.nextReminderSec; const RuntimeSnapshot state = runtimeCoordinator.snapshot(); displayManager.showNormalMode(appState.weightGrams, scaleManager.isStable(), appState.todayTotalMl, dailyGoalMl, appState.drinkCountToday, appState.lastDrinkMl, appState.nextReminderSec, state.wifiConnected, state.ipAddress, appState.ntpSynced); }
    displayManager.update();
    RuntimeSnapshot snapshot; snapshot.controlHeartbeat = ++controlHeartbeat; snapshot.mode = appState.mode; snapshot.fsOk = appState.fsOk; snapshot.logFsOk = appState.logFsOk; snapshot.oledOk = appState.oledOk; snapshot.hx711Ok = appState.hx711Ok; snapshot.buzzerOk = appState.buzzerOk; snapshot.ntpSynced = appState.ntpSynced; snapshot.scaleStable = scaleManager.isStable(); snapshot.scaleSamplesReady = scaleManager.isSamplesReady(); snapshot.tareRunning = scaleManager.isTareRunning(); snapshot.weightGrams = appState.weightGrams; snapshot.todayTotalMl = appState.todayTotalMl; snapshot.lastDrinkMl = appState.lastDrinkMl; snapshot.calibrationFactor = scaleManager.getCalibrationFactor(); snapshot.tareOffset = scaleManager.getTareOffset(); snapshot.cupState = appState.cupState; snapshot.drinkCountToday = appState.drinkCountToday; snapshot.dailyGoalMl = dailyGoalMl; snapshot.reminderIntervalMin = reminderIntervalMinSetting; snapshot.reminderEnabled = reminderEnabledSetting; snapshot.nextReminderSec = appState.nextReminderSec; std::strncpy(snapshot.reminderState, reminderManager.getStateName(), sizeof(snapshot.reminderState) - 1); std::strncpy(snapshot.reminderPausedUntilDate, reminderPausedUntilDate.c_str(), sizeof(snapshot.reminderPausedUntilDate) - 1); std::strncpy(snapshot.lastDrinkAt, appState.lastDrinkAt, sizeof(snapshot.lastDrinkAt) - 1); runtimeCoordinator.publishControl(snapshot);
}

void controlTask(void*) { TickType_t last = xTaskGetTickCount(); for (;;) { runControlIteration(); vTaskDelayUntil(&last, pdMS_TO_TICKS(10)); } }

void serviceTask(void*) {
    uint32_t lastHealth = 0; bool lastWifi = runtimeCoordinator.snapshot().wifiConnected;
    for (;;) {
        if (appState.mode == AppMode::NORMAL) { wifiManager.loop(); const bool connected = wifiManager.isConnected(); const std::string ipAddress = connected ? wifiManager.getIP() : "0.0.0.0"; appState.wifiConnected.store(connected); cloudSyncClient.setConnectivity(connected); if (connected != lastWifi) { lastWifi = connected; runtimeCoordinator.publishConnectivity(connected, ipAddress); } mqttPublisher.loop(runtimeCoordinator.snapshot().todayTotalMl); }
        ota_mark_app_valid_if_due(runtimeCoordinator.isControlHealthy());
        const uint32_t now = hal_millis(); if (now - lastHealth >= 30000) { lastHealth = now; const RuntimeSnapshot snapshot = runtimeCoordinator.snapshot(); const UBaseType_t stack = controlTaskHandle ? uxTaskGetStackHighWaterMark(controlTaskHandle) : 0; LOG_INFO("RTOS", "heartbeat=%lu stack_free=%u heap=%u min_heap=%u cmd_drop=%lu result_drop=%lu", static_cast<unsigned long>(snapshot.controlHeartbeat), static_cast<unsigned>(stack), static_cast<unsigned>(esp_get_free_heap_size()), static_cast<unsigned>(heap_caps_get_minimum_free_size(MALLOC_CAP_INTERNAL)), static_cast<unsigned long>(snapshot.commandDrops), static_cast<unsigned long>(snapshot.resultDrops)); if (!runtimeCoordinator.isControlHealthy()) LOG_WARN("RTOS", "control task heartbeat stalled"); }
        vTaskDelay(pdMS_TO_TICKS(50));
    }
}
}

extern "C" void app_main(void) {
    esp_log_level_set("HydraCup", ESP_LOG_INFO);
    // Tells a deliberate esp_restart() apart from a panic or watchdog reset, which otherwise
    // look identical from outside: the device simply reappears on a new firmware version.
    LOG_INFO(TAG, "HydraCup v%s booting (ESP-IDF), reset reason=%d", APP_VERSION,
             static_cast<int>(esp_reset_reason()));
    const esp_err_t nvsResult = nvs_flash_init();
    if (nvsResult != ESP_OK) { LOG_ERROR(TAG, "NVS init failed: %s", esp_err_to_name(nvsResult)); return; }
    ota_boot_check();
    // Before the mounts and before any task exists, so a wipe has nothing to race.
    history_apply_pending_clear();
    mountFilesystems(); configManager.load(appConfig); dailyGoalMl = appConfig.dailyGoalMl;
    reminderEnabledSetting = appConfig.reminderEnabled;
    reminderIntervalMinSetting = appConfig.reminderIntervalMin;
    reminderPausedUntilDate = appConfig.reminderPausedUntilDate;
    runtimeCoordinator.begin();
    appState.oledOk = displayManager.init(); if (appState.oledOk) displayManager.showBootScreen();
    scaleManager.init(appConfig.calibrationFactor, appConfig.tareOffset, appConfig.stableToleranceGram, appConfig.stableDurationMs); appState.hx711Ok = scaleManager.isReady();
    appState.buzzerOk = buzzerController.init(appConfig.buzzerFrequencyHz, appConfig.buzzerVolumePercent); buzzerController.setDuration(appConfig.buzzerDurationMs); buzzerController.setEnabled(appConfig.buzzerEnabled);
    reminderManager.init(appConfig.reminderIntervalMin, appConfig.reminderEnabled); reminderManager.setAlertTimeoutSec(appConfig.reminderAlertTimeoutSec); reminderManager.setBuzzer(&buzzerController); reminderManager.setAppState(&appState); drinkDetector.init(scaleManager, appState, appConfig, reminderManager, buzzerController);
    const bool connected = !appConfig.wifiSsid.empty() && wifiManager.connectSTA(appConfig.wifiSsid, appConfig.wifiPassword, 10000);
    if (connected) {
        appState.mode = AppMode::NORMAL; appState.wifiConnected = true; appState.ipAddress = wifiManager.getIP();
        if (appConfig.ntpEnabled) timeManager.init(appConfig);
        discordNotifier.init(appState, appConfig);
        if (appConfig.mqttEnabled) mqttPublisher.init(appState, appConfig);
        eventLogger.init(appState.logFsOk);
        if (!cloudSyncClient.init(appState, appConfig, configManager, eventLogger, appState.logFsOk)) {
            LOG_ERROR(TAG, "cloud sync initialization failed");
        }
        drinkDetector.setTimeManager(&timeManager); drinkDetector.setDiscordNotifier(&discordNotifier); drinkDetector.setEventLogger(&eventLogger); drinkDetector.setMqttPublisher(&mqttPublisher); drinkDetector.setCloudSyncClient(&cloudSyncClient); mqttPublisher.setTimeManager(&timeManager);
        dailySummaryManager.init(discordNotifier, drinkDetector, timeManager, appConfig); dashboardServer.begin(scaleManager, configManager, appState, appConfig, buzzerController, reminderManager, appState.logFsOk, runtimeCoordinator, eventLogger, discordNotifier, wifiManager, cloudSyncClient);
        if (otaUpdater.init(appState, runtimeCoordinator)) dashboardServer.setOtaUpdater(otaUpdater);
        runtimeCoordinator.publishConnectivity(true, appState.ipAddress); displayManager.sleep(); LOG_INFO(TAG, "normal mode IP=%s", appState.ipAddress.c_str());
    } else {
        const bool ap = wifiManager.startAP(appConfig.apSsid, appConfig.apPassword); appState.mode = AppMode::AP_MODE; appState.ipAddress = wifiManager.getAPIP(); runtimeCoordinator.publishConnectivity(false, appState.ipAddress); if (ap) { configPortal.begin(configManager, appState, appConfig, wifiManager); displayManager.showAPMode(appConfig.apSsid, appConfig.apPassword, appState.ipAddress); LOG_INFO(TAG, "AP mode SSID=%s IP=%s", appConfig.apSsid.c_str(), appState.ipAddress.c_str()); } else if (appState.oledOk) displayManager.showError("AP FAILED");
    }
    if (!appState.hx711Ok) buzzerController.play(BeepPattern::ERROR_BEEP); else if (connected) buzzerController.play(BeepPattern::WIFI_CONNECTED); else buzzerController.play(BeepPattern::AP_MODE);
    runtimeCoordinator.setControlRunning(true); if (xTaskCreatePinnedToCore(controlTask, "hydracup_control", 8192, nullptr, 3, &controlTaskHandle, 1) != pdPASS) { runtimeCoordinator.setControlRunning(false); LOG_ERROR(TAG, "control task creation failed"); }
    xTaskCreate(serviceTask, "hydracup_service", 4096, nullptr, 1, nullptr); LOG_INFO(TAG, "boot complete");
}

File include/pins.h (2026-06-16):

#pragma once

// HX711
#define PIN_HX711_DOUT 4
#define PIN_HX711_SCK  5

// OLED I2C
#define PIN_OLED_SDA   21
#define PIN_OLED_SCL   22

// Buzzer
#define PIN_BUZZER     18

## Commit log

2026-06-16 feat: initialize ESP32 Hydracup water tracker firmware
    - Set up PlatformIO project with ESP32 Arduino framework
    - Add libraries: HX711, ArduinoJson, Adafruit SSD1306 & GFX
    - Implement components: WiFi, ConfigPortal, DashboardServer, Scale, Display, Buzzer, DiscordNotifier
    - Configure partitions.csv and clangd LSP configuration
    - Add initial .gitignore to exclude build artifacts and VS Code configs
    [partitions.csv]
2026-06-16 feat(display): support 128x32 OLED and show AP password in AP mode
    - config.h: change OLED_SCREEN_HEIGHT from 64 to 32
    - DisplayManager: refactor pages and dot indicators to fit 32px height
    - DisplayManager: update showAPMode() to accept and display AP password
    - partitions.csv: rename partition subtype from littlefs to spiffs to resolve build/upload issues
    [partitions.csv]
2026-06-16 feat(wifi): add WiFi network scanning to configuration portal
    - WiFiManager: switch AP mode to WIFI_AP_STA to enable network scanning
    - ConfigPortal: implement /api/wifi/scan API endpoint with 5-second cooldown
    - ConfigPortal: update setup HTML portal with a scanning button, network list, and signal bar
2026-06-17 feat(detector): support cup-lift detection for drinking and refilling
    - DrinkDetector: track cup-lift state and timestamp with a 2-minute timeout
    - DrinkDetector: calculate drink or refill amount when cup is placed back
    - config: increase DEFAULT_STABLE_DURATION_MS to 3000ms for more stable readings
    - ScaleManager: change stability comparison tolerance to strict inequality
    [app_types.h, config.h]
2026-06-17 feat(reminder): make reminder alert persistent until cup is lifted
    - ReminderManager: loop reminder alert for up to 30 seconds
    - ReminderManager: automatically silence alert when cup is lifted
    - BuzzerController: add stop() method and implement a distinct 4-beep reminder pattern
    - main.cpp: link AppState to ReminderManager to enable cup state tracking
    [main.cpp]
2026-06-17 feat(reminder): defer reminder alert if cup is away during interval
    - ReminderManager: add _overdueWhileAway flag to track deferred alerts
    - ReminderManager: implement private helper _cupIsStable() using appState
    - ReminderManager: trigger alert as soon as cup returns to stable status
    - ReminderManager: reset overdue state on timer reset and when disabled
2026-06-17 feat(fs): split LittleFS into webfs and logfs partitions
    - partitions: partition spiffs into webfs (384KB) and logfs (1MB)
    - EventLogger: accept fs::LittleFSFS instance to isolate log files from web assets
    - main: mount LittleFS webfs under "/webfs" and logfs under "/logfs"
    - AppState: add logFsOk flag to track log partition status
    - platformio: document partition layout and uploadfs target behavior
    [partitions.csv]
2026-06-17 feat(discord): add daily water summary report and automatic counter reset
    - DailySummaryManager: implement daily summary task triggered at 12:00 PM
    - DiscordNotifier: add notifyDailySummary to send rich Discord embeds with fields
    - DrinkDetector: add resetDailyCounters() to clear daily intake, count, and appState
    - TimeManager: implement getLocalTm() helper to query current local time details
    - main: instantiate and update DailySummaryManager in setup and loop
    [main.cpp]
2026-06-17 feat(display): implement OLED auto-sleep and event-driven wake
    - DisplayManager: add wake(), sleep(), and 60-second auto-timeout duration
    - DisplayManager: turn off SSD1306 display when inactive to prevent OLED burn-in
    - DisplayManager: force display on for boot, error, Wi-Fi connecting, and AP modes
    - main: track cup state changes and wake display when cup is lifted or placed back
    - main: wake display when the drinking reminder timer expires
    - main: put display to sleep initially upon entering normal mode
    [main.cpp]
2026-06-18 feat(reminder): make alert timeout configurable and loop buzzer playback
    - Config: add reminderAlertTimeoutSec parameter with default of 60 seconds
    - DashboardServer: add input field to web UI for adjusting reminder alert timeout
    - ReminderManager: support dynamic alert timeout and loop BeepPattern::REMINDER
    - ReminderManager: stop buzzer on timer reset if alert is currently active
    - main: initialize reminder manager with configured alert timeout on startup
    [app_types.h, config.h, main.cpp]
2026-06-18 fix(reminder): introduce gap between buzzer beep cycles during alert
    - ReminderManager: define BEEP_CYCLE_GAP_MS of 800ms between play cycles
    - ReminderManager: track beep cycle end times using _beepCycleEndMs member
    - ReminderManager: play reminder beep pattern intermittently with configured delay
    - ReminderManager: reset beep cycle state on alert stop, timer reset, and when disabled
2026-06-18 feat(web): serve static assets from webfs and add drink history viewer
    - DashboardServer: replace PROGMEM inline HTML with filesystem-based _serveFile()
    - DashboardServer: register new /history page and stream jsonl logs via /api/logs
    - DashboardServer: support configuring advanced sensor parameters in /api/config
    - DashboardServer: report logfs partition status (hw_logfs) in status API
    - data: add new index.html, settings.html, and history.html web pages
    - data: redesign style.css to support tabs, tables, and modern dark aesthetics
    - data: remove deprecated calibration.html and redirect /calibration to settings
    [main.cpp]
2026-06-18 feat(web): add weekday chart, pagination, and stats to history page
    - data/history: implement pagination and page size selector for logs table
    - data/history: draw a new weekday average water consumption chart with goal line
    - data/history: calculate and show rich metrics (streak, max, averages, goal days)
    - data/history: perform deep analysis (peak hour, max gap between drinks, best day)
    - data/style: add CSS styles for log toggle, page size buttons, and pagination
2026-06-18 feat(web): add annual calendar heatmap and responsive stats grid to history page
    - data/history: draw a GitHub-style annual water consumption calendar heatmap
    - data/history: implement interactive tooltips and touch support for heatmap cells
    - data/history: add concurrent month log loading and past year caching for heatmap
    - data/style: change container width to 860px to fit the wide heatmap layout
    - data/style: make stats grid responsive using repeat(auto-fill, minmax(160px, 1fr))
    - data/style: add CSS styling for heatmap widgets, legend, and tooltips
2026-06-18 docs: add comprehensive project documentation and setup guides
    - README: add project overview and basic build/flash commands
    - docs/index: create documentation portal homepage
    - docs/modules: document main firmware modules, locations, and public APIs
    - docs/architecture: explain state machine design, partitions, and data flow
    - docs/hardware: document pin assignments and wiring for HX711/OLED/Buzzer
    - docs/data-formats: define JSONL log entries schema and NVS preference keys
    - docs/guides: write detailed guides for calibration, build, WiFi, and Discord
2026-07-14 feat(web): redesign dashboard and harden Discord delivery
    [main.cpp]
2026-07-14 fix(web): make annual heatmap responsive
2026-07-18 fix(discord): prevent duplicate daily summaries
    [main.cpp]
2026-07-18 style(web): standardize theme toggle labels to LIGHT and DARK
    - data/history.html: change theme labels from "紙" / "夜" to "LIGHT" / "DARK"
    - data/index.html: change theme labels from "紙" / "夜" to "LIGHT" / "DARK"
    - data/login.html: change theme labels from "紙 Paper" / "夜 Night" to "LIGHT" / "DARK"
    - data/settings.html: change theme labels from "紙" / "夜" to "LIGHT" / "DARK"
2026-07-20 fix(ap): restore setup controls and preserve display case
2026-07-20 refactor(display): migrate OLED to I2C master API
2026-07-20 feat(cad): add release assets
    [hydracup-bottom.step, hydracup-bottom.stl, hydracup-top.step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]
2026-08-11 feat(cloud): backfill device history
2026-08-12 build: shrink firmware and configure ESP-IDF for OTA
    firmware.bin occupied 90.0% of the 1,310,720-byte app slot, leaving no room
    for OTA support. Two build settings recover 146,336 bytes (90.0% -> 78.8%),
    so the partition table needs no change and logfs drink history is untouched:
    - CONFIG_COMPILER_OPTIMIZATION_SIZE (-Og -> -Os): 98,672 bytes
    - CXX exceptions and RTTI off: 47,664 bytes. The project has no try/catch and
    no dynamic_cast/typeid; virtual dispatch is unaffected by -fno-rtti.
    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
2026-08-12 feat(ota): update firmware from GitHub Releases
    Adds lib/OtaUpdater: a dedicated ota_worker task (10 KB static stack, priority
    3 so httpd at 5 keeps answering status polls, pinned to core 0) that checks a
    fixed version.txt release asset and writes the spare app slot via the stepwise
    esp_https_ota API. version.txt is used instead of api.github.com because the
    unauthenticated API allows only 60 requests/hour/IP - which several devices
    behind one NAT will exhaust - and parsing its JSON would cost 8 KB of DRAM.
    Exposes GET /api/ota/status plus POST /api/ota/check and /api/ota/update,
    reusing the existing session and CSRF checks. Wired through setOtaUpdater()
    rather than a 13th begin() parameter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
    [config.h, main.cpp]
2026-08-12 docs: document OTA and automate releases
    Adds .github/workflows/release.yml, triggered by v*.*.* tags. Two gates exist
    because OTA depends on them: the tag must match APP_VERSION in include/version.h
    (a mismatch means devices either never update or try to "update" backwards), and
    firmware.bin must stay under 92% of the app slot. The size gate also runs in CI
    so an oversized build is caught in a pull request rather than at release time.
    Release asset names are frozen - include/config.h bakes the URLs into every
    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
2026-08-12 fix(ota): verify the downloaded image and stop trusting a stale check
    Addresses findings from an independent review of the OTA implementation.
    Version identity (High): the manifest and the firmware asset are two requests
    against a mutable "latest" pointer, so a stale check could install an unexpected
    or older-but-bootable image - TLS and the image header prove integrity, not
    identity. The download now reads the app descriptor and refuses anything that is
    not both the announced version and newer than what is running.
    That check needs a comparable version string in the descriptor, which it did not
    have: PROJECT_VER came from git describe ("v0.4.0-8-g55db70d-dirty"). A top-level
    version.txt n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
    [config.h]
2026-08-12 fix(ota): wait for heap to recover instead of a fixed settle delay
    Follow-up to the second review round; no blocking findings remained.
    The 1.5 s settle delay could not do its job: cloud sync and Discord only observe
    the shed flag at the top of their loops, and their HTTP timeout is 10 s, so one
    already inside a request keeps its TLS heap well past the delay. Wait on free
    internal heap instead (250 ms poll, 12 s cap) - a worker still holding a session
    is exactly what keeps it low, so the thing being waited on is the thing at stake.
    Also makes the rollback retry deadline overflow-safe (a plain comparison wraps at
    the ~49.7 day millis() rollover and would retry every service tick), and re-ch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
    [config.h]
2026-08-12 fix(web): restore the httpd socket budget so the heatmap loads promptly
    v0.6.0 pinned max_open_sockets to 5, below the ESP-IDF default of 7, to reserve
    sockets for OTA downloads. That trade was unnecessary - the same release raised
    CONFIG_LWIP_MAX_SOCKETS from 10 to 16, and the other network workers stand down
    for the duration of an update anyway.
    Browsers keep up to 6 persistent connections open per host. Once they exceed what
    httpd will accept, the extra connections sit unaccepted in the TCP backlog until
    an existing one is reclaimed. The history page fans out 13 monthly requests for
    the year heatmap, so it presented as a permanent "loading" state; measured at over
    five minutes.
    curl cou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
2026-08-12 style(web): present firmware and calibration values as metric cells
    The OTA card borrowed .factor-badge (the calibration card's own style) inside a
    .split-grid, which is a 1.2fr/.8fr layout meant for a content column plus a
    sidebar - so two equally weighted values rendered lopsided and visually unlike
    the rest of the app.
    Both cards now use .metric-grid.compact-grid with .metric cells, the component
    the UI style guide designates for labelled values and the same one the dashboard
    already uses for its reminder figures. .factor-badge and .weight-display-lg have
    no remaining references and are removed; .split-grid stays, still used correctly
    for the card layout on the dashboard.
    The update pro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
2026-08-12 chore: ignore playwright-mcp output in the repo root
    Browser tooling writes screenshots and traces relative to the working directory,
    which lands them in the project root.
2026-08-12 feat(ota): update the web assets in the same action as the firmware
    OTA only wrote the app partition, so anything under data/ needed a USB uploadfs.
    The settings page now handles both in one "update".
    Order and preconditions matter more than the transfer itself:
    - SHA256SUMS is fetched before anything is written. Without it the web image
    cannot be verified, and an unverifiable image must not be written to a
    partition that has no spare to fall back on - so webfs is left alone.
    - Firmware is written first. If it fails the update stops with webfs untouched.
    The reverse order could leave a UI newer than the firmware serving it, and the
    compatibility contract only guarantees the other d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
    [config.h]
2026-08-12 feat(web): clear the drink history, performed at the next boot
    Adds POST /api/logs/clear and a danger card on the settings page. The session
    alone does not authorise it - the password is re-verified against the stored
    PBKDF2 hash, and failures count towards the same lockout the login endpoint uses,
    so the endpoint cannot become a brute-force oracle for an unattended tab.
    The endpoint does not clear anything. It records the request in NVS, answers, and
    restarts; the wipe runs early in the next boot, before the filesystems are
    mounted.
    That indirection is the whole design. Clearing while the system runs means racing
    every producer that writes the state being erased: the event logger's queue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
    [main.cpp]
2026-08-12 fix(ota): follow redirects when downloading the web assets
    The webfs half of the OTA has never worked. Updating hardware to v0.7.1 wrote the
    firmware correctly and then reported "網頁資源更新失敗".
    esp_http_client only resolves 301/302 inside esp_http_client_perform(), via
    esp_http_check_response(). The web image has to be streamed onto the partition as
    it arrives, so it uses the lower-level open()/fetch_headers()/read() flow - which
    hands the redirect straight back. GitHub always redirects release assets to its
    asset CDN, so the very first response was a 302 and the code gave up on seeing a
    non-2xx status. The firmware half was unaffected because esp_https_ota goes
    through the path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
    [config.h]
2026-08-12 feat(ota): keep the update outcome readable after the restart
    Every OTA ends in a restart, so its result lives on screen for about 2.5 seconds
    - precisely when nobody is watching. The v0.7.1 webfs failure was missed exactly
    this way: the message flashed by, the device rebooted, the page reloaded, and
    nothing was left to inspect. The cause had to be reconstructed by reasoning
    instead of read off the device.
    The final message is now written to NVS before the restart and returned as
    `last_outcome`, which the settings page shows as "上次更新結果：…" once the device
    is back. Success or failure, watched or not, it can be looked up afterwards.
    This release also happens to be the first re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
2026-08-12 fix(ota): erase the webfs partition in step with the writes
    The v0.7.3 update finally got past the redirect and started downloading, then
    left webfs unmountable ("Corrupted dir pair") and the device serving only
    "Web assets unavailable".
    Dumping the partition and diffing it against the published image answered it
    outright: all 384 KB were 0xFF. The erase had succeeded and not one byte had been
    written. The ~30 s it took matches the 15 s read timeout, twice.
    The sequence was: open the HTTPS connection, erase the whole 384 KB partition,
    then start reading. A full erase runs for seconds and disables the flash cache in
    bursts while it does - and lwIP executes from flash, so the connection open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
2026-08-12 feat(web): change the admin password from the settings page
    Adds POST /api/auth/password and a card on the settings page. A valid session is
    not enough on its own - the current password is re-verified, which is what stops
    an unattended tab from being turned into permanent access. Failures count towards
    the same IP lockout the login endpoint uses.
    The new password must be at least 8 characters and at most 128 bytes, and is
    compared against its confirmation in constant time. On success the session is
    dropped and the cookie cleared, so the new password has to be used: the device
    keeps a single session slot, and leaving the old one live would outlast the
    credential it came from.
    If persisting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
2026-08-12 fix(ota): give the OTA task the stack a second TLS session needs
    In the v0.7.5 update the firmware was written correctly, the status showed
    "開始更新網頁資源 · 0%", and the device restarted immediately. webfs was neither
    updated nor damaged, and after the reboot last_outcome was empty.
    That combination is the evidence. saveLastOutcome() runs at the very end of the
    normal path, so an empty value means that code was never reached - and the normal
    path also holds the final message for 2.5 s, which was never seen. Together they
    say _updateWebfs() died shortly after starting.
    The deepest point in that flow is the TLS handshake inside
    esp_http_client_open(), immediately after the firmwa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
    [main.cpp]
2026-08-12 fix(ota): allocate the webfs download buffer as byte-addressable memory
    webfs OTA has never once succeeded since v0.7.0. A serial capture of the crash
    answered it outright:
    Guru Meditation Error: Core 0 panic (LoadStoreError)
    EXCCAUSE 0x3 EXCVADDR 0x40096bc0 A2 0x40096668 A12 0x1000
    PC 0x4000c325 (ROM memcpy)
    0x40096668 is IRAM (0x40080000-0x400A0000 on ESP32), which only permits 32-bit
    aligned access, and A12 is 4096 - OTA_WEBFS_CHUNK. The panic is memcpy copying
    the first chunk of the download into a buffer that cannot take byte writes.
    The buffer was allocated with MALLOC_CAP_INTERNAL alone. That capability only
    promises "not PSRAM, survives a cache disable"; IRAM sat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
2026-08-12 chore(release): v0.7.8
    Version bump only. Exists so the IRAM buffer fix from v0.7.7 gets to run as the
    executing firmware once: an OTA download is performed by the firmware already on
    the device, not the one being downloaded, so a fix in that path is only exercised
    by the update after the one that delivers it.
    Nothing else changes, so a success here is attributable to MALLOC_CAP_8BIT alone.
2026-08-13 fix(wifi): retry the STA connection before falling back to the config portal
    connectSTA() gave up after a single 10 s attempt. After a reset the access point
    has usually not released the previous association yet, so one attempt routinely
    fails on a network that is reachable again seconds later.
    The cost was not just an extra reset. An update reboots the device; if it lands
    in AP mode the user assumes the update failed and resets it - and the new
    firmware is in pending verification at that point, needing 30 s of a healthy
    control task before it is marked valid. A reset inside that window makes the
    bootloader roll the firmware back. That sequence caused two unintended rollbacks
    during testing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
    [config.h]
2026-08-13 docs: record the webfs OTA post-mortem and flag private-repo links (#17)
    The webfs download path took three fixes to work, and each defect was only
    visible once the previous one was out of the way. Write down what they were,
    which release fixed each, and that v0.7.6's stack theory was wrong - a later
    log showed 11 KB of the 16 KB still free. Also note that paper-frame has no
    webfs OTA, so there was no existing implementation to compare against.
    The links to hydracup-service now say the repo is private. It is, so every
    external reader clicking them gets a 404 with no explanation.

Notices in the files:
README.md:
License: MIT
